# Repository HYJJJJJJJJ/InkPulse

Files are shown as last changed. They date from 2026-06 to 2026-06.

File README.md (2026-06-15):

# InkPulse

> 一块放在桌面的 7.5" 三色墨水屏，实时显示 **Claude Code 的工作状态、token 用量、待办事项、照片**，外加时钟与温湿度。
> 渲染全部在电脑端完成，设备只负责"把电脑渲染好的整屏位图拉下来贴上去"。

InkPulse 是一个**软硬件一体**的开源项目，包含：自制 PCB（ESP32-S3 + UC8179 墨水屏驱动）、3D 打印楔形外壳、设备固件、以及电脑端的渲染服务 Hub。

---

## 目录

- [它是什么](#它是什么)
- [系统架构](#系统架构)
- [仓库结构](#仓库结构)
- [技术规格速查](#技术规格速查)
- [快速开始（端到端）](#快速开始端到端)
- [当前状态与路线图](#当前状态与路线图)
- [文档索引](#文档索引)

---

## 它是什么

桌面信息屏，单屏组合显示（不翻页，避免三色屏每次全刷闪烁）：

- **Claude 状态**（主角）：某台开发机上 Claude Code 的实时状态 —— 空闲 / 工作中 / 等你输入 / 刚完成 / 出错，附项目名。需要注意的状态用**红色**强调。
- **用量**：订阅制下今日 token（输入/输出/缓存）、估算花费、5 小时计划窗口剩余比例。
- **待办**：工作/生活待办，提供局域网网页（手机也能加）。
- **照片**：可选的整屏照片布局（Floyd–Steinberg 三色抖动）。
- **顶栏白送**：时钟/日期 + 板载温湿度。

**设计取舍**（详见 [显示系统设计文档](software/docs/superpowers/specs/2026-06-09-inkpulse-display-system-design.md)）：局域网内使用、常插电无电池、订阅制用量靠解析本机日志、布局用 YAML 配置而非拖拽编辑器。

---

## 系统架构

**瘦客户端 + 本机 Hub 渲染**：复杂的排版、三色量化、抖动都在电脑上做好，设备只做整屏 blit。改布局只改配置、不用重新烧固件。

```
开发机 (跑 Claude Code)                          墨水屏设备 (ESP32-S3)
┌─────────────────────────────────────┐
│  Claude Code ──hooks──┐              │
│                       ▼              │
│  ┌────────── InkPulse Hub ─────────┐ │   WiFi / HTTP      ┌──────────────────┐
│  │ 采集器 → 状态模型 → 渲染引擎     │ │ ─────────────────▶ │ 固件:             │
│  │   ├ 用量(解析 ~/.claude 日志)    │ │  GET /frame        │  BLE/SoftAP 配网  │
│  │   ├ 待办(JSON + 网页)           │ │  → 96000B 双plane  │  拉帧→变了才刷    │
│  │   ├ 照片(目录轮换)              │ │  + ETag/304        │  →按节拍轻睡循环  │
│  │   └ Claude状态(hook POST 推送)  │ │  + X-Next-Refresh  │  离线缓存上一帧   │
│  └─────────────────────────────────┘ │                    └──────────────────┘
│   ▲ config.yaml  ▲ photos/  ▲ todos   │                       ▲ HTU21D 温湿度
└─────────────────────────────────────┘                       随取帧请求上报
```

**关键协议**（设备 ⇄ Hub）：

| 项 | 约定 |
|---|---|
| 取帧 | `GET /frame`，请求带 `If-None-Match: <上次ETag>` |
| 帧格式 | 黑 plane(48000B) + 红 plane(48000B) = **96000B**；行主序，每行 100 字节，MSB=最左像素；bit=1 表示该色 |
| 去重 | `ETag`=帧内容哈希；未变返回 `304`，**设备不刷屏**（三色屏体验命门：避免无谓闪烁） |
| 节奏 | 响应头 `X-Next-Refresh`（秒）由 Hub 决定下次拉取间隔 |
| 上报 | 设备取帧时把温湿度作为 query 带上（`/frame?t=22&h=55`），Hub 渲染进顶栏 |

---

## 仓库结构

```
InkPulse/
├── hardware/        Altium Designer PCB 工程（原理图 + PCB + 3D STEP）
│   └── library/     元件库（git submodule）
├── cad/             build123d 参数化外壳（楔形三件套 + 抽拉盖板）+ 校验脚本
│   └── output/      生成的 STL/STEP 产物
├── software/
│   ├── firmware/    ESP32-S3 固件（ESP-IDF）：UC8179 驱动 + 配网 + 拉帧主循环
│   ├── hub/         电脑端 Hub（Python/FastAPI）：采集 + 渲染 + HTTP 服务
│   └── docs/        软件侧设计文档（specs）与实现计划（plans）
└── docs/            硬件/外壳设计文档
```

各子系统都有自己的 README：[hardware](hardware/README.md) · [cad](cad/README.md) · [firmware](software/firmware/README.md) · [hub](software/hub/README.md)。

---

## 技术规格速查

| 模块 | 规格 |
|---|---|
| 主控 | ESP32-S3 模组（YD-ESP32-S3），WiFi + BLE + PSRAM |
| 屏幕 | 英瑞达 E075A42，7.5"，**800×480**，黑/白/红三色 (BWR)，控制器 **UC8179**，4 线 SPI |
| 刷新 | 全刷约 15~30s，**无局刷、无灰阶**；红色仅用于强调/告警 |
| 帧缓冲 | 双 plane（黑+红）= 96000 B ≈ 94 KB |
| 传感器 | 板载 HTU21D 温湿度（I2C，地址 0x40） |
| 供电 | USB-C 5V → LDO 3.3V，无电池，常插电 |
| 烧录 | CH343G USB 串口 + DTR/RTS 自动下载 |
| 外壳 | 3D 打印楔形支架，屏面仰角 60°，前框/后盖/底座三件 + 抽拉盖板 |

**引脚映射**（以 PCB 网表为准）：

| 信号 | GPIO | | 信号 | GPIO |
|---|---|---|---|---|
| SCL(CLK) | 41 | | DC | 39 |
| SDA(MOSI) | 42 | | RES(RST) | 38 |
| CSB(CS) | 40 | | BUSY_N | 37 |

HTU21D：SCL=GPIO2, SDA=GPIO1。

---

## 快速开始（端到端）

从零到屏上显示，需要两步：起 Hub（电脑）→ 烧固件并配网（设备）。

### 1. 起 Hub（电脑端）

```bash
cd software/hub
pip install -e ".[dev]"
( cd web-ui && npm ci && npm run build )           # 构建配置中心前端（或直接用 ./run.sh, 已内置）
cp config.example.yaml ~/inkpulse-config.yaml      # 按需改 photos/todos 路径
INKPULSE_CONFIG=~/inkpulse-config.yaml python -m inkpulse_hub
# 监听 0.0.0.0:8080（INKPULSE_PORT 可改）
```

浏览器打开 `http://<本机IP>:8080/` 即可进**配置中心**——分区管理待办/日程/行情/天气/照片、可视化布局编辑，常驻「真机当前帧 / 改完预览」面板，改动经 SSE 即时反映。无设备也能用 `/preview.png` 看渲染效果。
详见 [Hub README](software/hub/README.md)。

### 2. 烧固件 + 配网（设备端）

```bash
cd software/firmware
# 先把 main/net_config.h 的 HUB_FRAME_URL 改成你电脑的局域网地址
./build.sh setup                       # 首次：set-target esp32s3
PORT=/dev/ttyUSB0 ./build.sh fm        # 编译 + 烧录 + 看日志
```

设备首次上电无凭据 → 开 **BLE 配网**（用 Espressif 官方 *ESP BLE Provisioning* App，设备名 `PROV_InkPulse`，PoP `inkpulse`）；BLE 超时 180s 自动回退 SoftAP 网页配网。配好网后设备自动拉帧上屏。详见 [固件 README](software/firmware/README.md)。

### 3.（可选）接 Claude Code 状态

把 `software/hub/hooks/claude_status.sh` 挂到 `~/.claude/settings.json` 的 hooks，在 SessionStart→working、Stop→done、Notification→waiting_for_input 等时机上报状态。

---

## 当前状态与路线图

**已端到端跑通并真机验证**：BLE 配网 → 连 WiFi → 拉 Hub 帧 → 三色墨水屏显示仪表盘（时钟/Claude 状态/用量/温度），中文清晰、无残影。

| 子系统 | 状态 |
|---|---|
| 固件：UC8179 驱动 + 拉帧主循环 | ✅ 跑通 |
| 固件：BLE 配网（+ SoftAP 兜底） | ✅ 跑通（SoftAP 兜底路径代码就绪，未单独实测） |
| Hub：采集 + 渲染 + HTTP 服务 | ✅ 跑通，33 项测试通过 |
| 外壳 CAD：四件套 + 装配/干涉校验 | ✅ 模型与校验脚本就绪 |
| 硬件 PCB | ✅ 已制板、已焊接联调 |

**已知限制**：
- 板载这颗 HTU21D **湿度通道硬件损坏**（温度正常，湿度恒返回 0）；Hub 已在顶栏隐藏无效湿度，换好传感器后自动恢复显示。

**后续可做**：
- 微信小程序替代官方 App 配网（提升体验）
- 待办/照片/配置化的进一步打磨
- SoftAP 兜底路径的实测验证

---

## 文档索引

**设计文档（specs）**
- [显示系统设计](software/docs/superpowers/specs/2026-06-09-inkpulse-display-system-design.md) —— 软件总体架构、协议、布局、刷新策略
- [BLE 配网设计](software/docs/superpowers/specs/2026-06-11-inkpulse-ble-provisioning-design.md) —— BLE 主 + SoftAP 兜底
- [外壳设计](docs/superpowers/specs/2026-06-03-inkpulse-enclosure-design.md) —— 楔形外壳尺寸、PCB 机械接口约定

**实现计划（plans）**
- [固件：屏驱动](software/docs/superpowers/plans/2026-06-09-inkpulse-firmware-driver.md)
- [固件：联网](software/docs/superpowers/plans/2026-06-09-inkpulse-firmware-net.md)
- [固件：BLE 配网](software/docs/superpowers/plans/2026-06-11-inkpulse-firmware-ble-prov.md)
- [Hub](software/docs/superpowers/plans/2026-06-09-inkpulse-hub.md)

**子系统 README**：[hardware](hardware/README.md) · [cad](cad/README.md) · [firmware](software/firmware/README.md) · [hub](software/hub/README.md)

---

## 许可

见 [LICENSE](LICENSE)。

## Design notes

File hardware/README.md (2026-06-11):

# InkPulse 硬件（PCB）

InkPulse 驱动板的 **Altium Designer** 工程：ESP32-S3 主控 + UC8179 墨水屏接口 + HTU21D 温湿度 + USB-C 供电/烧录。板尺寸 **70.10 × 50.04mm**。

## 工程文件

| 文件 | 说明 |
|---|---|
| `PCB_Project.PrjPcb` | Altium 项目主文件（层定义/规则/工程树） |
| `PCB_Project.PrjPcbStructure` | 项目结构清单 |
| `Sheet1.SchDoc` | 原理图 |
| `PCB1.PcbDoc` | PCB 设计（布线/层/丝印） |
| `PCB1.step` | 3D STEP 导出，供 `cad/` 做装配/干涉校验 |

用 Altium Designer 打开 `PCB_Project.PrjPcb`。

## 元件库（submodule）

`library/` 是 git submodule，源 `https://github.com/HYJJJJJJJJ/AD_Library.git`，含 Altium PCB 封装库（`*.PcbLib`）与原理图库（`*.SchLib`）。首次克隆后初始化：

```bash
git submodule update --init --recursive
```

## 板上关键

| 模块 | 器件/说明 |
|---|---|
| 主控 | ESP32-S3 模组（YD-ESP32-S3），WiFi + BLE + PSRAM，板上最高元件 ≈3.7mm |
| 屏接口 | UC8179 4 线 SPI（SCL/SDA/CS/DC/RES/BUSY）+ 外部升压（GDR/RESE 驱动 MOSFET + 电感）；24-pin FPC 排座 |
| 传感器 | HTU21D 温湿度（I2C，地址 0x40，SCL=GPIO2 / SDA=GPIO1） |
| 供电 | USB-C 5V → LDO(CJ6107B33M) 3.3V，无电池 |
| 烧录 | CH343G USB 串口 + DTR/RTS 自动下载 |
| 输入 | BOOT / RESET 两键 + 1 个红色 LED |

**ESP32 ↔ 屏幕引脚映射**（固件 `main/pins.h`，以网表为准）：

| 信号 | GPIO | | 信号 | GPIO |
|---|---|---|---|---|
| SCL(CLK) | 41 | | DC | 39 |
| SDA(MOSI) | 42 | | RES(RST) | 38 |
| CSB(CS) | 40 | | BUSY_N | 37 |

## 机械接口（与外壳约定）

坐标原点 = 板几何中心；X = 长边方向；Y = Type-C(+) ↔ FPC(−) 方向。

| 项目 | 规格 | 位置 |
|---|---|---|
| 板外形 | 70.10 × 50.04，板厚 1.6mm | 中心对齐外壳 |
| 安装孔 ×4 | Φ3.2 (M3) | (±30, ±20) |
| Type-C 母座 16P | 供电/烧录 | Y− 长边中点 (0, −22)，**朝外壳后** |
| 24-pin 显示排座 | FPC 插座 | Y+ 长边中点 (0, +22)，朝屏 |

> 外壳为机械基准、PCB 跟随。详见 [外壳设计文档 §5](../docs/superpowers/specs/2026-06-03-inkpulse-enclosure-design.md)。`cad/analyze_pcb.py` 可从 `PCB1.step` 自动提取这些接口数据。

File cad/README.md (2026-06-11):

# InkPulse 外壳（CAD）

3D 打印楔形桌面外壳的**参数化建模**与校验脚本。屏面相对桌面仰角 60°，三件式打印 + 螺丝装配，外加一块抽拉盖板。

> 完整设计依据（尺寸、PCB 机械接口约定、公差）见 [外壳设计文档](../docs/superpowers/specs/2026-06-03-inkpulse-enclosure-design.md)。

## 工具链

- **建模库**：[build123d](https://github.com/gumyr/build123d) 0.10.0（Python 参数化 CAD）
- **校验**：numpy + matplotlib（干涉/装配/质心）
- 环境：Python 3.11+

```bash
conda create -n cad python=3.11
conda activate cad
pip install build123d numpy matplotlib
```

## 生成模型

```bash
cd cad
python3 enclosure.py        # 生成四件套 + 装配体，导出到 output/
```

所有尺寸是 `enclosure.py` 顶部的具名变量（与设计文档 §9 一一对应），改参数重跑即可。

## 零件（output/）

| 件 | 文件 | 作用 | 打印姿态 |
|---|---|---|---|
| 前框 bezel | `bezel.{stl,step}` | 正面开视窗露可视区，唇边压玻璃黑边 | 正面朝下（前表面最平整） |
| 后盖 back cover | `back_cover.{stl,step}` | 压紧玻璃、保护背面、开 FPC 过线槽 | 平放 |
| 底座 base | `base.{stl,step}` | 楔形，装 70×50 PCB，60° 斜接前框，后壁开 Type-C 口 | 平放 |
| 抽拉盖板 lid | `lid.{stl,step}` | 底座底盖，导轨 + 卡扣 detent + 防滑横条 | 平放 |
| 装配体 | `assembly.step` / `assembly_shell.step` | 60° 仰角姿态总装（含 PCB 与屏参考） | — |

**装配关系**：玻璃从背面放入前框 → 垫 0.5mm 泡棉 → 后盖螺丝压紧 → 屏框组件在 60° 斜接缝与底座拼接 → PCB 用 M3 锁在底座螺柱（柱心 ±30,±20）→ FPC 从屏框底经后盖线槽折入底座接显示排座。

**打印工艺**：PLA/PETG，层高 0.2mm，3 圈壁，配合间隙 0.4mm，目标免支撑/极少支撑。

## 校验脚本

这些脚本读取真实 `hardware/PCB1.step` 做几何校验，确保外壳与 PCB 配合：

| 脚本 | 作用 | 输出 |
|---|---|---|
| `analyze_pcb.py` | 从 PCB STEP 提取外形/板厚/孔位/高元件/连接器位置 | 机械接口结论 |
| `fitcheck.py` | 把真实 PCB 放入底座，检查配合间隙、螺柱对孔、Type-C 对位 | `output/fitcheck.png` |
| `check_interf.py` | 装配体各零件两两干涉体积检测（>1mm³ 报冲突） | 干涉表 |
| `fpc_reach.py` | 装配姿态下屏 FPC 出线点 → PCB 显示排座的走线距离是否够弯折 | 距离报告 |
| `verify_v3.py` | v3（PCB 前移后）关键复验：FPC 跨度 / base∩PCB / lid∩PCB / 盖板余量 / 螺柱位 | 验证清单 |
| `render_preview.py` | 4 个零件 STL 渲染成预览图 | `output/preview_parts.png` |

## 关键参数（节选）

```
SCREEN: 170.20 × 111.20 × 1.25mm，可视区 163.20 × 97.92mm
PCB:    70.10 × 50.04mm，M3 孔位 (±30, ±20)，最高元件 ≈3.7mm（ESP32 模块）
外壳:   壁厚 2.5mm，唇厚 1.2mm，仰角 60°
底座:   宽大底脚板 130 × 90 × 4mm（抗后倾），两片 60° 斜墙在 ±63
Type-C: 朝后（+Y，背向用户），开口 10×4mm，中心离内底 ≈7.3mm
```

> PCB 机械接口以**外壳为基准、PCB 跟随**；坐标原点=板几何中心，已用 `fitcheck.py` 将真实 PCB STEP 放入底座校验通过。

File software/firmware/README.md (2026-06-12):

# InkPulse 固件（ESP32-S3 + UC8179 7.5" BWR 墨水屏）

- **阶段一**：屏驱动 bring-up（清屏 + 白/黑/红测试图案）—— 已通过。
- **阶段二**：联网瘦客户端 —— BLE 配网（SoftAP 兜底）→ 从 Hub 拉 800×480 三色帧 → 写屏；ETag/304 去重、离线保留上一帧、按 `X-Next-Refresh` 节拍循环；HTU21D 温湿度随请求上报。

## 环境

ESP-IDF v5.3.2（建议装在 `~/esp/esp-idf`，可用 `IDF_PATH` 覆盖）。每开新终端先激活：

```bash
source ~/miniforge3/etc/profile.d/conda.sh && conda activate espidf   # 若用 conda
. ~/esp/esp-idf/export.sh
```

> 国内网络：工具链走 `dl.espressif.cn` 镜像、源码走 gitee。

## 构建 / 烧录 / 看日志（跨平台脚本）

脚本会自动激活 ESP-IDF 环境（找不到 `idf.py` 时 source `$IDF_PATH/export.sh`）。

**Linux / macOS / WSL** — `./build.sh`：

```bash
cd software/firmware
./build.sh setup            # 首次: set-target esp32s3
./build.sh build            # 编译
PORT=/dev/ttyUSB0 ./build.sh fm   # 烧录 + 看日志(Ctrl+] 退出)
./build.sh verify           # bring-up 验证模式(温湿度+白黑红, 不联网)
./build.sh clean
```

**Windows PowerShell** — `.\build.ps1`：

```powershell
cd software\firmware
.\build.ps1 setup
.\build.ps1 build
$env:PORT='COM5'; .\build.ps1 fm
.\build.ps1 verify
```

> 也可直接用原生 `idf.py set-target esp32s3 && idf.py build && idf.py -p <PORT> flash monitor`。
> 脚本未识别的子命令会透传给 `idf.py`，例如 `./build.sh menuconfig`。

## 配置 Hub 地址

编辑 `main/net_config.h`，把 `HUB_FRAME_URL` 改成你电脑跑 `inkpulse_hub` 的局域网地址：

```c
#define HUB_FRAME_URL "http://192.168.1.23:8080/frame"   // 改成你的 IP
```

Hub 默认端口 8080（`INKPULSE_PORT` 可改）。

## 首次配网（BLE 为主，SoftAP 兜底）

无 WiFi 凭据时，设备**优先开 BLE 配网**；超时（`PROV_BLE_TIMEOUT_S`，默认 180s）仍未配网则**自动回退 SoftAP 网页配网**。

### 方式一：BLE（推荐）

1. 手机装 **ESP BLE Provisioning** App（Espressif 官方，App Store / Google Play）
2. 打开 App → *Provision New Device* → 扫码或选设备 **PROV_InkPulse**
3. 输入 Proof of Possession：**inkpulse**
4. 选家里 WiFi → 填密码 → 提交
5. App 显示配网成功后，设备**直接复用该连接拉帧上屏，无需重启**

> 配网参数在 `main/net_config.h`：`PROV_BLE_NAME` / `PROV_POP` / `PROV_BLE_TIMEOUT_S`。
> 收到凭据后由 `wifi_prov_mgr` 完成 WiFi 连接并回报 App，再进主循环——不在配网收尾处 `esp_restart`，否则 App 会误报 “Device disconnected”。
> 后续计划：用微信小程序替代官方 App 进一步提升体验（见 `../docs`）。

### 方式二：SoftAP（BLE 超时兜底）

BLE 超时未配网时设备自动开热点 **InkPulse-Setup**（密码 `inkpulse123`）：

1. 手机/电脑连该热点 → 浏览器打开 `http://192.168.4.1`
2. 填 WiFi 的 SSID / 密码 → 保存 → 设备重启
3. 重启后连 WiFi → 拉帧 → 屏上显示 Hub 渲染的仪表盘

凭据存在 NVS namespace `inkpulse`；`./build.sh erase-flash` 可清空重新配网。

## 引脚映射（原理图确认）

| 信号 | GPIO | | 信号 | GPIO |
|---|---|---|---|---|
| SCL(CLK) | 41 | | DC | 39 |
| SDA(MOSI) | 42 | | RES(RST) | 38 |
| CSB(CS) | 40 | | BUSY_N | 37 |

HTU21D（I2C）：SCL=GPIO2, SDA=GPIO1，地址 0x40。

## 帧/颜色契约（与 Hub `/frame` 对齐，勿改）

- body = 黑 plane(48000B) + 红 plane(48000B) = 96000B；行主序，每行 100 字节，MSB=最左像素。
- 黑 plane bit=1→黑；红 plane bit=1→红。
- 写屏映射（`ip_display` 的 `uc8179.c`，阶段一极性结论）：
  - 0x10(B/W) `1=白 0=黑` → 发 `~black`
  - 0x13(RED) `1=红` → 红 plane 直发（`EPD_RED_INVERT=0`；若实测红/白反相改 1）
- 响应头 `ETag`（带引号哈希）、`X-Next-Refresh`（秒）；请求带 `If-None-Match`，命中返回 304 不刷屏。

## 代码结构（ESP-IDF components 分层）

固件按标准 components 分层解耦,`main` 只组装接口、不依赖具体实现。换屏/换数据源只需新增对应实现 component,上层零改动。接口用 ops 结构体(函数指针表 + 工厂函数)。

| component | 职责 | 公开接口 / 工厂 |
|---|---|---|
| `ip_hal` | SPI/I2C/GPIO 封装 + 板级引脚（`board_pins.h`） | `hal_spi_*` / `hal_i2c_*` |
| `ip_display` | 墨水屏（通用 display 接口 + UC8179 实现 + selftest） | `display_if_t` / `uc8179_driver()` |
| `ip_sensor` | 温湿度（sensor 接口 + HTU21D，读数带有效位） | `sensor_if_t` / `htu21d_sensor()` |
| `ip_net` | WiFi STA 连接（WPA3-SAE + 带间隔循环重连） | `ip_net_init/prepare_sta/sta_connect` |
| `ip_provisioning` | BLE/SoftAP 配网 + NVS 凭据 | `provisioning_if_t` / `ble_provisioning()` / `softap_provisioning()` / `creds_*` |
| `ip_channel` | 数据源（channel 接口 + HTTP-Hub 拉帧/上报，**不碰显示**） | `channel_if_t` / `http_hub_channel()` |
| `ip_config` | 编译期常量（Hub URL / 配网参数，`net_config.h`） | — |
| `main` | app：纯接口组装 + 主循环编排（`INKPULSE_VERIFY` 切 selftest） | — |

**换屏**：新增 `components/ip_display_xxx/` 提供 `display_if_t`，改 `main.c` 一行工厂 + CMake，上层（channel/sensor/net/app）零改动。
**换数据源**：新增 channel 实现（如 BLE 传帧）提供 `channel_if_t`，同理。

设计与实现计划见 `../docs/superpowers/specs/2026-06-12-inkpulse-firmware-layered-arch-design.md` 与 `../docs/superpowers/plans/2026-06-12-inkpulse-firmware-layered-arch.md`。

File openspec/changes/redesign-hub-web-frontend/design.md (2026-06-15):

## Context

Hub 配置中心现状是单文件 `software/hub/inkpulse_hub/web/config.html`（459 行，vanilla JS + `innerHTML` 拼接 + 内联样式），10 张卡片叠成长卷轴。后端 `server.py` 已提供完整的 `/api/*` 业务端点，渲染由 `render.engine.render_frame(cfg, state, profile)` 完成——`/frame`(设备字节) 与 `/preview.png`(预览图) 同源同一帧、on-demand 渲染。设备是瘦客户端，仅周期性 `GET /frame`（ETag/304 去重，`X-Next-Refresh` 节拍），e-ink 实际上屏约 21s 延迟。

关键缺口：服务端从不记录"上次真正送给设备的是哪一帧"，所以网页无法呈现"设备此刻物理显示的内容"；网页刷新预览靠每个操作后 `setTimeout(refreshPreview, 300)`，既不跟手也不能多端同步。

## Goals / Non-Goals

**Goals:**
- 用 Vue 3 + Vite 重写配置中心，侧栏分区导航拆掉长卷轴。
- 网页常驻"真机当前帧"（设备最后拉走的帧）+ "改完预览"切换，所见即真机。
- SSE 实时同步替换所有客户端定时刷新；多端打开自动一致。
- 纸墨/e-ink 视觉风格，响应式。
- 后端改动是纯增量加法，不碰 `render_frame` 渲染核心，设备固件零改动。

**Non-Goals:**
- 不改设备端渲染逻辑或 `/frame` 的字节格式与 ETag/304 协议（设备无感）。
- 不把屏幕上的实时数值拆成 web 原生数据卡（探索时确认走 B·真机帧，不是 A·数据镜像）。
- 不引入用户认证 / 多用户（hub 仍是单用户局域网工具）。
- 不替换现有 `/api/*` 业务端点的契约。

## Decisions

### D1：Vue 3 + Vite，而非 React 或保留 vanilla
配置型仪表盘、单文件组件(SFC)、样板少、运行时体积小，最贴这个场景。React 同样可行但样板更多；保留 vanilla 无法根治"拼字符串 + 无反应式"的老问题（用户已明确选"上正经框架"）。源码置于 `software/hub/web-ui/`，与 Python 包并列。

### D2：dist 部署时 build，不提交产物
hub 由 systemd 托管，部署时增加 `npm ci && npm run build` 一步产出 `web-ui/dist/`，FastAPI 用 `StaticFiles` 挂载。保持 git 仓库干净、避免产物与源码漂移。代价是部署机需 Node/npm，并在 README/部署文档中记录。**回退**：若构建链暂不可用，可临时保留旧 `config.html` 作 fallback 路由直到 dist 就绪（迁移期）。

### D3："真机当前帧"靠服务端记录最后送出帧实现
在 `/frame` handler 中，当返回真实帧体（非 304）时，把该帧的 `png_bytes` + 时间戳 + 当前 env(t/h/rssi) 存入 hub 状态（`state.py` 或新 `device_view` 模块的内存字段，单设备、单槽即可）。新增：
- `GET /api/device/frame.png` → 返回该 PNG（无记录时回退为当前 `preview.png` 或占位）。
- `GET /api/device/status` → `{ pulled_at, age_s, rssi, temp, humidity, etag }`。
这样"真机当前帧"与"改完预览(`/preview.png`)"是两张可对比的图，差异窗口正好可视化 e-ink 延迟。**备选**：在网页侧用 ETag 推断——否决，服务端记录更直接、可附 env/时间戳。

### D4：SSE 单向流 + 独立 web 同步令牌，替代轮询
**关键修正**：现有 `_refresh["token"]`（`/api/refresh-token`）是**设备**轮询的"强制立即刷屏"信号，只应由用户点「刷新屏幕」(`/api/refresh`) 触发。若把"设备拉帧"并入同一令牌会造成死循环（设备拉帧→bump→设备再拉帧），把"每次数据改"并入则会让设备每改一条就强刷一次、伤 e-ink。因此采用**两个独立令牌**：
- **设备令牌** `refresh_token`（`/api/refresh-token`）：语义**完全不变**，仅 `/api/refresh` 触发，设备只看它。
- **web 同步令牌** `web_token`（仅 SSE 用）：配置改 / 数据改(todos/habits/events/market/photos/...) / 设备拉帧 / `/api/refresh` 都 `bump`，**只驱动网页**自动刷新预览与真机帧；设备永不感知。

新增 `GET /api/stream`（`text/event-stream`），推送 `{ token, device_pulled_at }`，网页订阅后据此自动刷新，**删除所有 `setTimeout(refreshPreview, 300)`**。SSE 而非 WebSocket：单向推送够用、FastAPI 下 `StreamingResponse` 实现简单、无额外依赖、`EventSource` 断线自动重连。SSE 生成器以 ~1s 轮询 `web_token` 变化（避免跨线程信号，sync 端点在线程池里 bump，不能安全 `set()` 事件循环里的 Event），变化即推送。**备选**：网页直接轮询 `/api/refresh-token`——否决，延迟高、多端不同步、且会与设备令牌语义打架。

### D5：信息架构——侧栏分区 + 常驻帧主角
导航分区拆掉长卷轴，按"低频配置 vs 高频日常"归类：
```
总览 | 屏幕(布局+编辑器+刷新间隔) | 待办 | 习惯 | 日程 | 行情 | 天气 | 照片 | 设置
```
顶部/侧栏常驻 `[真机当前] / [改完预览]` 切换 + `⟳刷屏` 按钮，跨分区始终可见。布局编辑器(网格框选)作为"屏幕"分区下的子面板保留现有交互。

### D6：纸墨视觉语言
承接 `docs/mockups/mockup-explorer.html` 既有配色审美，建立 CSS 设计 token（纸白底、墨黑字、点缀红——对应 BWR 三色屏）。响应式：桌面侧栏、窄屏抽屉/底部 Tab。

## Risks / Trade-offs

- [部署新增 Node 构建依赖] → 在部署文档/README 记录 `npm ci && npm run build`；迁移期保留旧 HTML fallback（D2）。
- [SSE 长连接占用 worker / 断线] → 限制单连接、心跳 keep-alive、客户端 `EventSource` 自动重连；uvicorn 异步天然支持。
- [最后送出帧的内存状态在 hub 重启后丢失] → 可接受：重启后首次设备拉帧即重建；`/api/device/frame.png` 无记录时回退到 `preview.png`。
- [前端大改面积、回归风险] → 现有 `/api/*` 契约不变，逐分区迁移并对照旧页验证；后端改动有 pytest 覆盖。
- [真机帧 vs 预览混淆用户] → UI 明确标注"设备 N 秒前拉帧"与"下次拉帧将变成"，把延迟讲清楚而非藏起来。

## Migration Plan

1. 后端先行：加 `/api/device/*` 与 `/api/stream`、`/frame` 记录最后送出帧；补 pytest。旧 `config.html` 暂留。
2. 搭 `web-ui/` Vue+Vite 骨架，逐分区迁移（先总览+屏幕+预览/真机帧，再 todos/habits/events/market/weather/photos/settings）。
3. 接 SSE，删除 `setTimeout(refreshPreview,300)`。
4. `StaticFiles` 挂载 `dist/`，切换默认入口；验证通过后移除 `config.html`、`todos.html` 及 `/config`、`/todos` 旧路由。
5. 更新部署文档（构建步骤）。**回退**：保留旧 HTML 路由分支即可快速切回。

## Open Questions

- 纸墨配色的具体 token 值是否直接复用 mockup-explorer 的调色板，还是另立一套？（实现时定）
- 窄屏导航用底部 Tab 还是抽屉？（实现时按手感定）

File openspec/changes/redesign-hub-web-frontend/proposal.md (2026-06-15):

## Why

Hub 的配置中心目前是一个 459 行的 `config.html` 单文件：10 张卡片叠成一根长卷轴、用 vanilla JS 拼 `innerHTML`、内联样式满天飞。三个痛点叠加——(1) 全堆一页要命的长滚，配置类与日常类内容互相干扰；(2) 实时预览埋在第 3 张卡、改完要靠 `setTimeout(refreshPreview, 300)` 手动刷，预览不跟手；(3) 视觉朴素。更关键的是：网页只能看到一张"按当前 state 渲染的 PNG"，**看不到设备此刻物理显示的那一帧**——而这正是用户想要的"所见即真机"。

## What Changes

- **BREAKING**：用 Vue 3 + Vite 重写整个配置中心，退役 `config.html` 与遗留的 `todos.html`。前端产物 `dist/` 经 FastAPI `StaticFiles` 挂载到 `/`。
- 用**侧栏分区导航**拆掉长卷轴：总览 / 屏幕(布局+编辑器+刷新) / 待办 / 习惯 / 日程 / 行情 / 天气 / 照片 / 设置，各分区各司其职。
- 引入**"真机当前帧"常驻主角**：网页顶部/侧栏常驻一块，显示设备最后真正拉走的那一帧（= 此刻玻璃上的内容），附"设备 N 秒前拉帧 · RSSI · 温度"。可在 `[真机当前]` 与 `[改完预览]` 间切换，把 e-ink 刷新延迟可视化。
- 后端**增量加法**（不动渲染核心）：`/frame` 命中时记录"最后送给设备的帧"（png + 时间戳 + rssi/temp）；新增 `GET /api/device/frame.png` 与 `GET /api/device/status`。
- 引入 **SSE 实时流** `GET /api/stream`：统一 `refresh-token`，配置改 / 数据改 / 设备拉帧都 bump，网页订阅后自动更新预览与真机帧——**删除所有 `setTimeout(refreshPreview, 300)`**，多端打开自动同步。
- 现代化**纸墨 / e-ink 视觉风格**，承接 `docs/mockups/mockup-explorer.html` 已有的配色审美；响应式，手机上也可用。
- 现有 `/api/*` 业务端点（todos/habits/weather/events/market/config/layouts/photos/refresh）**保持不变**，仅被新前端消费。

## Capabilities

### New Capabilities
- `hub-web-ui`: Vue 3 + Vite 重写的 Hub 配置中心——侧栏分区导航、纸墨视觉、响应式，常驻"真机当前帧 / 改完预览"切换面板；Vite `dist/` 经 FastAPI 静态挂载、部署时 build。
- `device-frame-mirror`: 后端记录"最后送给设备的帧"（png + 时间戳 + rssi/temp），并通过 `GET /api/device/frame.png`、`GET /api/device/status` 暴露给网页，实现"真机当前帧"镜像。
- `hub-realtime-sync`: SSE 流 `GET /api/stream` 统一 `refresh-token` 信号（配置改/数据改/设备拉帧均 bump），网页订阅后自动刷新预览与真机帧，取代客户端定时轮询。

### Modified Capabilities
<!-- 现有 dashboard-rendering(设备端渲染)的需求不变；本次只新增 web 与后端配套端点。 -->

## Impact

- **新增前端工程**：`software/hub/web-ui/`（Vue 3 + Vite 源码 + `package.json`），build 产物 `dist/`。
- **`software/hub/inkpulse_hub/server.py`**：新增 `/api/device/frame.png`、`/api/device/status`、`/api/stream`(SSE)，`/frame` handler 增加"记录最后送出帧"；用 `StaticFiles` 挂载 `dist/`；移除 `/config`、`/todos` 旧 HTML 路由与 `web/config.html`、`web/todos.html`。
- **`software/hub/inkpulse_hub/state.py`**（或新模块）：保存最后送出帧的字节/PNG/时间戳/env。
- **部署**：systemd 托管的 hub 启动前需 `npm ci && vite build`（或文档化的构建步骤）；新增 Node/npm 构建依赖。
- **测试**：新增 `/api/device/*`、`/api/stream` 的 pytest；前端可加轻量构建校验。
- 设备固件**无需改动**（仍只拉 `/frame`）。

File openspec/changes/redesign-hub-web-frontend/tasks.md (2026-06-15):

## 1. 后端：真机当前帧记录与端点 (device-frame-mirror)

- [x] 1.1 在 hub 状态（`state.py` 或新 `device_view` 模块）增加"最后送出帧"内存槽：png 字节、时间戳、env(t/h/rssi)、etag
- [x] 1.2 修改 `/frame` handler：返回 200 真实帧体时写入该槽；304 命中时不覆盖
- [x] 1.3 新增 `GET /api/device/frame.png`（无记录时回退 preview/占位，不报错）
- [x] 1.4 新增 `GET /api/device/status`（`pulled_at`/`age_s`/`rssi`/`temp`/`humidity`）
- [x] 1.5 pytest 覆盖：拉帧后被记录、304 不覆盖、无记录回退、status 字段

## 2. 后端：统一信号源与 SSE (hub-realtime-sync)

- [x] 2.1 抽出 `bump_web()` 单一入口；写请求经 middleware 统一 bump，`/frame` 拉帧经 record_device_frame bump（设备 refresh_token 语义不变，避免死循环）
- [x] 2.2 新增 `GET /api/stream`（`text/event-stream`），token 变化时推送 `{token, device_pulled_at}`，含心跳 keep-alive
- [x] 2.3 pytest 覆盖：数据变更/拉帧触发 bump、设备令牌不受影响、`sse_stream` 初值+变更各发一条事件

## 3. 前端工程脚手架 (hub-web-ui)

- [x] 3.1 在 `software/hub/web-ui/` 初始化 Vue 3 + Vite 工程（`package.json`、构建脚本）
- [x] 3.2 建立纸墨视觉设计 token（纸白/墨黑/红点缀）与全局样式，承接 mockup-explorer 配色
- [x] 3.3 搭好 API 封装层（`/api/*` 调用）与 SSE 客户端（`EventSource` 自动重连）
- [x] 3.4 实现侧栏分区导航骨架（总览/屏幕/待办/习惯/日程/行情/天气/照片/设置）+ 响应式窄屏导航

## 4. 前端：常驻预览/真机帧面板

- [x] 4.1 实现跨分区常驻面板：`[真机当前]`/`[改完预览]` 切换 + `⟳刷屏`
- [x] 4.2 真机当前视图接 `/api/device/frame.png` + `/api/device/status`，标注"设备 N 秒前拉帧 · RSSI · 温度"
- [x] 4.3 改完预览视图接 `/preview.png`；两视图均由 SSE 事件自动刷新，去除任何固定 setTimeout 刷新

## 5. 前端：各分区面板迁移

- [x] 5.1 屏幕分区：布局选择 + 布局编辑器(网格框选保留交互) + 刷新间隔
- [x] 5.2 待办、习惯分区
- [x] 5.3 日程、行情、天气分区
- [x] 5.4 照片分区（上传/删除/钉选）
- [x] 5.5 设置分区（预算/token 上限/刷新间隔等）
- [x] 5.6 总览分区（汇总入口 + 真机帧主视图）

## 6. 集成、退役与文档

- [x] 6.1 FastAPI 用 `StaticFiles` 挂载 `web-ui/dist/` 为网页入口
- [x] 6.2 移除 `web/config.html`、`web/todos.html` 及 `/config`、`/todos` 路由（旧页测试一并删除）
- [x] 6.3 更新 README/部署文档：`run.sh` 内置幂等 build、hub/主 README 构建步骤与端点表、systemd 注意事项
- [x] 6.4 全量回归：pytest 292 通过、端到端冒烟(SPA 入口/旧路由404/设备帧端点/API)验证

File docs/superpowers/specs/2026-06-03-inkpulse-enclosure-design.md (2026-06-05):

# InkPulse 墨水屏桌面外壳 — 设计文档

- 日期：2026-06-03
- 状态：已确认，待实现
- 目标：为 InkPulse 项目（7.5" 三色墨水屏 + 50×50 驱动板）设计一个可 3D 打印的楔形桌面外壳。

## 1. 背景与依据

- **墨水屏**：深圳英瑞达 **E075A42**（7.5" 三色 AMEPD，800×480）。规格书：`hardware/docs/英瑞达E075A42 （BWR）(1).pdf`。
  - 外形：**170.20 (W) × 111.20 (H) × 1.25 (厚，含膜) mm**，重 44±0.5g。
  - 可视区 (AA)：**163.20 × 97.92 mm**。
  - 黑边（AA 到外形，**非对称**）：上 3.49 / 下 9.79（FPC 侧）/ 左右各 3.50 mm（长边方向居中，短边方向 AA 上偏）。
  - **FPC 排线**：从 **170.20mm 长边居中**引出（判据：偏宽黑边 9.79mm 落在 111.20mm 方向轴上，绑定边垂直于该轴 → 即长边）。FPC 宽 **79.90 ±0.2mm**，露出/弯折段 **11.50–12.50mm**，带 PI 补强（总厚 0.30mm，补强段不可弯，弯折仅发生在 0.10mm 软段）。
  - 背面平整、无金属背板或突起，可整面贴泡棉。
  - 接口 24-pin（脚距规格书未标注数值，需实测/向供应商确认，常见 0.5mm 但不可据此下料）。
- **驱动板**：**70.10 × 50.04mm**（实测自 `hardware/PCB1.step`，由 build123d 导入测量）。Type-C 与显示 FPC 排座分别在两条 70mm 长边中点。板载 16P Type-C 母座用于供电/烧录。
  - 早期为 50×50，后改版为 70×50；外壳已据 STEP 实测更新（见 §5）。
- **约束/选择**（与用户确认）：
  - 屏横放（170.2 宽 × 111.2 高），FPC 在底部长边。
  - 外形为 "∠" 楔形，底座位于屏框**正下方**。
  - 屏面与水平桌面**仰角 60°**。
  - 三件式打印 + 螺丝装配。
  - PCB 四角 M3 螺柱固定。
  - Type-C 开口**朝后**（背向用户）。
  - 打印机幅面 ≥ 220×220（屏框可整片打印）。
  - 材料默认 PLA/PETG，层高 0.2mm，3 圈壁。
  - **外壳为机械基准，PCB 跟随**（见 §5 接口约定）。

## 2. 总体架构

楔形桌面支架，三个 FDM 打印件 + 螺丝装配：

| 件 | 作用 | 打印姿态 |
|---|---|---|
| 前框 bezel | 正面开视窗露可视区，唇边压玻璃黑边 | 正面朝下 → 前表面最平整 |
| 后盖 back cover | 压紧玻璃、保护背面、开 FPC 过线槽 | 平放 |
| 底座 base（楔形） | 装 50×50 PCB，与前框 60° 拼接，后壁开 Type-C 口 | 平放 |

装配关系：玻璃从背面放入前框 → 垫 0.5mm 泡棉 → 后盖螺丝压紧（屏框组件）→ 屏框组件在 60° 斜接缝与底座螺丝拼接 → PCB 用 M3 锁在底座螺柱上 → FPC 从屏框底经后盖线槽折入底座接显示排座。

## 3. 屏框（前框 + 后盖）

- 玻璃容腔：170.20×111.20，单边间隙 0.4mm（实装容差）。
- **视窗开口**：163.20 × 97.92 + 0.5mm 余量；**向上偏置**——上边框 ~3.0 / 下边框（FPC 侧）~9.3 / 左右 ~3.0mm。视窗中心相对玻璃中心**上移 ≈ 3.15mm**（= (9.79−3.49)/2）。
- 前框唇边压黑边（不碰 AA），唇厚 1.2mm。
- 壁厚 2.5mm；屏框外形约 **176 × 117mm**。
- **背腔减薄至 5mm**（仅容玻璃 1.25 + 泡棉 0.5 + 薄后盖凸台）→ 前框总深 **7.2mm**（原 19.2），后盖总厚 **5.25mm**（原 17.25）。
- 后盖：与屏框外形齐平，4× M2.5 自攻螺丝压向前框；玻璃背面垫 0.5mm 泡棉。
- 后盖 FPC 过线槽：**宽 84 × 深 13mm**，位于底部长边中央（对齐 FPC 79.9mm 宽 + 余量）。PI 补强段直出、软段折弯下行。

## 4. 底座（楔形 + PCB 仓 + 宽大底脚板）

- **中央 PCB 核心盒**：内腔容 70×50 PCB，四周间隙 0.5mm；4× M3 打印螺柱（boss），柱心 (±30, ±20)，柱高 4mm；**内腔净高 9mm**（顶面元件仅 3.7mm，已减薄；壁高 11mm 仍包住 Type-C 开口）。
- **后壁 Type-C 开口**：10 × 4mm（含 0.5 容差 + 倒角），中心离内底 ≈ **7.3mm**；Type-C 朝 +Y（背向用户）。底脚板低矮（4mm）不遮挡插拔。
- **宽大扁平底脚板（稳定性）**：**130 (W) × 90 (D) × 4mm**，横跨支撑 176mm 宽屏、抗后倾。屏重心水平投影（Y≈−16）落在脚板内 → 不倾倒。
- **两片 60° 斜墙（gusset）**：外移到脚板宽边 **±63**，横撑屏宽；起于脚板顶。**斜面朝 −Y+Z（朝观察者-上），使屏朝 −Y 观察者、向后倾**（朝向经校验：法线 ny=−0.87, nz=+0.50, arccos=60°）。2× M3 接缝螺丝横穿斜墙。
- 顶部线槽对位显示排座，承接屏框下来的 FPC。

## 5. PCB 机械接口约定 v1（外壳基准，PCB 跟随）

坐标原点 = 板几何中心；X 右为正；Y 朝 Type-C/后为正、朝屏/前为负。单位 mm。

**实测自 `hardware/PCB1.step`（板几何中心为原点；X=长边方向，Y=Type-C↔FPC 方向）**：

| 项目 | 规格 | 位置（板中心原点） |
|---|---|---|
| 板外形 | **70.10 × 50.04**，板厚 1.6（STEP 简化为 0.41，取实际 1.6） | 中心对齐外壳 |
| 安装孔 ×4 | **Φ3.2 (M3)** | **(±30, ±20)** |
| Type-C 母座 16P | body 11.3×7.6，口中心离板底 ≈1.65mm | **Y− 长边中点 (0, −22)** |
| 24-pin 显示排座 | 0.5mm 间距 FPC 插座，~12mm 宽 | **Y+ 长边中点 (0, +22)** |
| 最高元件 | **≈3.7mm**（ESP32 模块, 17.6×15.8 @ (−8.7,2.4)） | — |

> **装配朝向**：Type-C 边朝外壳后（+Y），FPC 排座边朝屏（前/−Y）。装入时 PCB 相对外壳绕 Z 翻 180°。
> 外壳侧已据此更新：PCB 仓 71.1×51、螺柱 (±30,±20)、Type-C 开口在 +Y 壁中心高 7.65mm。
> 已用 `cad/fitcheck.py` 将真实 PCB 放入底座校验：螺柱对孔、板落仓内、Type-C 对位开口，全部通过。

## 6. 打印工艺与公差

- 前框正面朝下、后盖与底座平放，目标**免支撑或极少支撑**。
- 配合间隙 0.4mm；自攻螺纹底孔按 M2.5/M3 自攻留 0.2mm。
- 材料 PLA/PETG，层高 0.2mm，壁 3 圈。
- 输出：STEP（导回 Altium 做装配/干涉检查）+ STL（切片打印）。

## 7. 实现方式（工具链）

- **build123d（Python）** 参数化建模，所有尺寸为脚本顶部变量。
- 环境：用户提供的 conda 环境（待建：`conda create -n cad python=3.11 && pip install build123d`）。
- 重活（写脚本、生成模型、干涉/可打印性验证）派 subagent 执行，结论回传，避免污染主上下文。

## 8. 未决/风险

- **24-pin 排座脚距未知**：规格书未标，建议实测；不影响外壳腔体设计（排座位置由 §5 约定），仅影响 PCB 选型。
- **Type-C 母座精确机械尺寸**：按 16P 通用值取默认，待实物/封装确认后微调开口。
- **重心稳定性**：170×111 屏 60° 后倾于 50mm 深底座，需在 CAD 后用质心/倾覆校核；必要时底座向后延伸或加配重槽。
- FPC 软段最小弯折半径需在装配验证时确认不超限。

## 9. 参数清单（CAD 变量，初值）

```
# 屏模组
SCREEN_W=170.20  SCREEN_H=111.20  SCREEN_T=1.25
AA_W=163.20  AA_H=97.92
BORDER_TOP=3.49  BORDER_BOTTOM=9.79  BORDER_SIDE=3.50
FPC_W=79.90  FPC_EXPOSED=12.50
# 外壳
WALL=2.5  LIP=1.2  FIT_GAP=0.4  FOAM_T=0.5
WINDOW_MARGIN=0.5
ANGLE_DEG=60
BACK_LIP_DEPTH=5.0        # 背腔深(减薄) -> 前框总深~7.2, 后盖~5.25
# 底座/PCB
PCB=50.0  PCB_T=1.6  STANDOFF_H=4.0
HOLE_D=3.2  HOLE_INSET=4.0
TYPEC_W=12.5  TYPEC_H=6.0  TYPEC_PORT_Z=5.65   # 实测自PCB1.step
FPC_CONN_Y=-22.8
CAVITY_CLEAR=9.0          # 减薄(原15); 元件仅3.7mm
PCB_W=70.10  PCB_D=50.04  M3_POS_X=30  M3_POS_Y=20
# 宽大底脚板 + 斜墙
BASE_FOOT_W=130.0  BASE_FOOT_D=90.0  BASE_FOOT_T=4.0
GUSSET_HEIGHT=40.0  GUSSET_T=4.0   # 斜墙在 ±(FOOT_W/2-GUSSET_T/2)=±63
```

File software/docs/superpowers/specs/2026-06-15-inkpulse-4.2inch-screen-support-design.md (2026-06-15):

# InkPulse 4.2 寸屏(SSD1677 BW)支持 — 设计

> 日期:2026-06-15 · 状态:已批准,待写实现计划

## 背景与目标

现有 InkPulse 使用 7.5 寸 **E075A42**(800×480,UC8179,BWR 三色)墨水屏。
现要新增对 4.2 寸 **YRD0426BBS770F0**(480×800,SSD1677 类,纯黑白 1-bit,支持局部刷新)的支持,
并满足三个目标:

1. **硬件**:核对新旧屏 FPC 是否 pin-to-pin 对应,判断是否改板。
2. **固件**:屏驱动充分解耦,能快速从 UC8179(BWR)切换到 SSD1677(BW)。
3. **hub 布局**:检测屏幕大小,基于现有 7.5 寸布局新实现一组 4.2 寸 480×800 竖屏布局。

一句话方案:**新屏与旧屏 pin-to-pin 兼容、不改板;固件编译期选驱动;hub 由设备上报的面板标识驱动多 profile 渲染(尺寸/颜色/旋转/网格/打包全随 profile)。**

## 已确认的硬事实(来自规格书)

新屏 `YRD0426BBS770F0`(`hardware/docs/YRD0426BBS770F0HP-V2.0-4.2_Inch-480x800.pdf`):

- 分辨率 **480(H)×800(V) 竖屏**;有效区 55.68×92.80mm;外形 62.37×105.33mm。
- **1-bit 纯黑白单 plane**(非 BWR);控制器 RAM 仍为 **800×480**,单 plane **48000 字节**(800/8×480)。
- 控制器命令集 `0x12/0x0C/0x01/0x11/0x44/0x45/0x4E/0x4F/0x24/0x22/0x20/0x10` =
  标准 **SSD16xx(SSD1677 类)**。
- 接口 4 线 SPI(BS1=L);信号:CS#/D-C#/RES#/SCL/SDA/BUSY;24-pin FPC;图像更新 ~1.1s;支持局部刷新;内置温度传感器。

> 注意:控制器 RAM 是 800×480(横向),模组按竖屏 480 宽×800 高观看。
> 因此"480×800 竖屏"在出帧时需要 **旋转 90°** 映射到 800×480 的 RAM。

## 数据流总览

```
设备(GET /frame?...&panel=bw_426)  ──►  hub
   │ 编译期 Kconfig 选屏                    │ panel id → ScreenProfile
   │ ssd1677 driver (display_if_t)          │ 选 layout 集 + 网格 + 颜色 + 旋转 + 打包
   ▼                                        ▼
 48000B 单plane ◄──── 800×480 1bpp ◄── rotate90 ◄── 渲染 480×800 竖屏画布
```

---

## 第 1 节 · 硬件(结论:**不改板**)

逐脚对比(旧屏 E075A42 规格书 p6 vs 新屏 YRD0426 规格书 p7):

| 脚 | 旧屏 E075A42(7.5″ BWR) | 新屏 YRD0426(4.2″ BW) | 一致 |
|---|---|---|---|
| 1 | NC | NC | ✓ |
| 2 | GDR | GDR | ✓ |
| 3 | RESE | RESE | ✓ |
| 4 | NC | NC | ✓ |
| 5 | VSHR | VSH2 | ✓ |
| **6** | **TSCL**(外置温感 I2C) | **NC** | ⚠ |
| **7** | **TSDA**(外置温感 I2C) | **NC** | ⚠ |
| 8 | BS | BS1 | ✓ |
| 9 | BUSY_N | BUSY | ✓ |
| 10 | RST_N | RES# | ✓ |
| 11 | DC | D/C# | ✓ |
| 12 | CS-N | CS# | ✓ |
| 13 | CLK/SCL | SCL | ✓ |
| 14 | DATA/SDA | SDA | ✓ |
| 15 | VDDIO | VDDIO | ✓ |
| 16 | VDDA | VCI | ✓ |
| 17 | VSS | VSS | ✓ |
| 18 | VDDD | VDD | ✓ |
| 19 | VPP | VPP | ✓ |
| 20 | VSH | VSH1 | ✓ |
| 21 | VGH | VGH | ✓ |
| 22 | VSL | VSL | ✓ |
| 23 | VGL | VGL | ✓ |
| 24 | VCOM | VCOM | ✓ |

**结论:24 脚中 22 脚完全同位,信号线(BS/BUSY/RST/DC/CS/SCL/SDA)全部一致 → 电气 pin-to-pin 兼容,不需要改板。**
唯一差异 pin6/7:旧屏是外置温感 I2C(TSCL/TSDA),新屏是 NC。本项目温湿度走独立板载 HTU21D、不经屏 FPC,故 NC 无影响。

交付物为一份**真机核对清单**(非代码):

1. 照新屏参考电路核对升压外围电容(GDR/RESE/VGH/VGL/VSH)值是否需微调。
2. 真机确认板上 pin6/7 未被强驱动到会干扰的电平(NC 一般安全)。
3. 新屏更小(62×105mm),**结构件/外壳/FPC 走线需重做**(属结构设计,不属改电路板)。

---

## 第 2 节 · 固件(编译期选驱动)

固件已有良好抽象:`ip_display/display.h` 定义 `display_if_t`(含 `get_caps`),`ip_channel` 的 `ch_init(caps)` 已用 `caps->frame_bytes` 决定拉多少字节。只需新增一个驱动实现 + 编译期选择。

- 新增组件驱动 `components/ip_display/src/ssd1677.c`,实现 `display_if_t`;
  `get_caps` 返回 `{width:480, height:800, color_model:DISP_BW, frame_format:"bw-1plane", frame_bytes:48000}`。
- `Kconfig` 增加 `choice INKPULSE_PANEL`:
  - `PANEL_UC8179_BWR_750`(默认,现状)
  - `PANEL_SSD1677_BW_426`
- `main.c` 按宏选驱动:
  ```c
  const display_if_t *disp =
  #if CONFIG_PANEL_SSD1677_BW_426
      ssd1677_driver();
  #else
      uc8179_driver();
  #endif
  ```
- 命令序列照规格书 p35 OTP 参考码:
  `0x12(软复位)→0x0C(升压软启动)→0x01(驱动输出/尺寸)→0x11(数据进入模式)→0x44/45(RAM XY 窗口)→0x4E/4F(RAM XY 计数器)→0x24(写 BW)→0x22(0xF7)→0x20(刷新)`;
  局刷走 SSD1677 partial update 流程(部分窗口 + partial LUT/0x22 参数)。
- `s_framebuf` 尺寸随 Kconfig(BW 仅需 48000;BWR 96000)。
- `mark_offline` 出 BW 变体:画黑色 X(无 red plane),与现 BWR 版同位。
- `ssd1677_selftest` 对标现有 `uc8179_selftest`:白/黑/棋盘 + 一次局部刷新演示。

**真机 bring-up 校准项**(非纯软件可定):

- 渲染→面板的旋转方向(90° 还是 270°)。
- 打包 bit 极性(`1`=黑 还是 `1`=白)。
- 升压软启动 / VCOM / LUT 参数微调。

URL 上报:固件在 `GET /frame` URL 追加 `&panel=<id>`(由 Kconfig 选屏决定,如 `bw_426` / `bwr_750`),供 hub 选 profile。

---

## 第 3 节 · hub(profile 驱动多尺寸)

### 现状耦合点

- `render/planes.py` 写死 `WIDTH,HEIGHT=800,480` + BWR 双 plane(`to_planes`/`pack_frame`)。
- `render/grid.py` 从 planes 取尺寸。
- `render/layouts.py` 仅有单一全局 `GRID={cols:8,rows:6}` 与一套 `BUILTIN_LAYOUTS`。
- `render/engine.py` 按写死尺寸建画布、打 BWR 包。
- `render/widgets.py` 多为 Zone 相对坐标 + 按 z.h/z.w 算字号(可缩放),少数用 RED(日历"今天")。
- `server.py` 的 `/frame` 为无状态拉模式,仅读 `t`/`h` 查询参数,帧为全局单一。

### 引入 ScreenProfile

把渲染知识集中到 hub 的一个 profile 表:

```python
bwr_750 = {w:800, h:480, color:"bwr", rotate:0,  grid:(8,6), pack:bwr_2plane}  # 现状
bw_426  = {w:480, h:800, color:"bw",  rotate:90, grid:(4,8), pack:bw_1plane}   # 新增
```

### 改动

- **`planes.py`**:移除写死尺寸/BWR;
  - `pack_frame(img, profile)`:按 `profile.color` 选单 plane(BW)或双 plane(BWR);
    按 `profile.rotate` 在 hub 侧用 PIL 旋转 90°(480×800 → 800×480)后再 1bpp 打包。
  - BW 单 plane:`to_plane_bw(img)` 输出 48000B。
- **`grid.py`**:`cell_to_zone(grid, p, profile)` 用 `profile.w/h`。
- **`layouts.py`**:`BUILTIN_LAYOUTS` 改为**按 profile 分组**:
  - `bwr_750` 沿用现有 8×6 六布局;
  - `bw_426` 新增 4×8 竖版六布局,**同名**(dash/photo/clock/usage/split/todo);
  - `get_layout(path, name, profile)`;用户自建布局存储按 profile 命名空间隔离。
- **`engine.py`**:`render_frame(cfg, state, profile)` 按 profile 建画布、选布局集、渲染、打包。
- **`server.py /frame`**:解析 `&panel=<id>` → 解析 ScreenProfile(**缺省/未知回退 `bwr_750`**,兼容现役固件)→ `render_frame(cfg, state, profile)`;ETag/preview 随 profile。
- **颜色降级**(BW profile):
  - 提供 `accent(profile)`:BWR 返回红、BW 返回黑。
  - 提供 `emphasize(d, zone, ...)`:今天等原本靠红区分的元素改用加框/反色/下划线。
  - 仅日历"今天"、市场涨跌等少数 widget 需改;红→黑后语义靠形状保留。

### 4×8 竖版布局草案(可在 plan 阶段微调)

```
480×800 / 4列×8行(格子 120×100px)
dash:  header(4×1) / claude_status(4×2) / usage(4×2) / todos(4×3)
photo: photo(4×8)
clock: big_clock(4×3) / calendar(4×3) / 余 2 行留白或 header
usage: usage(4×3) / usage_ring(4×2) / claude_status(2×3) + todos(2×3)
split: header(4×1) / claude_status(4×2) / calendar(4×2) / todos(4×3)
todo:  todos(4×5) / calendar(4×3)
```

---

## 第 4 节 · 兼容性

- 现役 7.5 寸固件不带 `panel` 参数 → hub 回退 `bwr_750` → 行为完全不变(**零回归**)。
- 新 4.2 寸固件带 `&panel=bw_426` → hub 渲 480×800 竖屏 → 旋转 → 48000B 单 plane。

---

## 第 5 节 · 测试

**hub(可纯软件验证,无需硬件)**:

- profile 解析与 `/frame` 参数解析 + 缺省/未知回退 `bwr_750`。
- 各 profile 网格数学(cell_to_zone 边界无缝)。
- 单 plane(BW,48000B)/ 双 plane(BWR,96000B)打包正确。
- 旋转正确性:已知图案渲染→旋转→校验像素落位。
- 颜色降级:BW 下红→黑且"今天"有替代强调。
- 6 个竖版布局逐个渲染不抛异常、产出 48000B 帧。
- 扩展现有 `test_planes/test_grid/test_engine/test_layouts` 为 profile 参数化。

**固件**:`ssd1677_selftest` + `INKPULSE_VERIFY` harness;真机校准旋转方向/bit 极性/升压。

---

## 第 6 节 · 实现拆分(两条独立 plan + 一份硬件清单)

- **Plan A(hub 多 profile)**:profile 重构(planes/grid/engine/layouts)+ bw_426 竖版布局 + 颜色降级 + `/frame` panel 参数 + 测试。
  **可在 hub 用 `/preview.png` 完整验证,不依赖硬件,应先行。**
- **Plan B(固件 ssd1677 驱动)**:Kconfig 选屏 + `ssd1677.c` + caps/URL panel id + BW `mark_offline` + selftest + 真机校准。
- **硬件核对清单**:随 Plan B 收尾(升压电容核对、pin6/7、结构件/外壳重做)。

两者通过 `&panel=` + ScreenProfile 解耦;A 与 B 可并行,A 可独立先验。

## 非目标(YAGNI)

- 不做固件运行时自动探测屏型(编译期 Kconfig 已足够)。
- 不把控制器时序/LUT 参数化下发(不同控制器差异大,得不偿失)。
- 本期不为 4.2 寸引入旧屏没有的新 widget;先复用现有 widget 重排。

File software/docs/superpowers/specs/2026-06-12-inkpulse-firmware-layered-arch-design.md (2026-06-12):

# InkPulse 固件分层解耦架构 — 设计文档

- 日期：2026-06-12
- 状态：已与用户确认方向，待评审后进入实现计划
- 范围：`software/firmware/` —— 把现有平铺的 `main/*.c` 重构为标准 ESP-IDF components 分层架构

---

## 1. 背景与目标

当前固件所有模块平铺在 `main/`（`epd_uc8179`/`htu21d`/`wifi_prov`/`ble_prov`/`frame_client`/`main`/`net_config`/`pins`），互相直接 `#include`、无接口隔离。典型耦合：

- `frame_client.c` 直接 `#include "epd_uc8179.h"` 并调用 `epd_display_planes(black, red)` —— 把「数据来源（HTTP/Hub）」和「显示（UC8179 双 plane）」绑死在一个函数里。
- `epd_uc8179.h` 一个头暴露了 HAL（`epd_send_cmd/data`）+ UC8179 驱动序列 + 双 plane 协议（`EPD_RED_INVERT`）+ bring-up 测试图案，四层混在一起。

**目标**：按标准嵌入式工程分层解耦，使以后
- **换屏幕**（不同墨水屏控制器/尺寸，甚至单色/多色/LCD）只新增 display 实现、不动上层；
- **换上层数据源**（Hub 服务端 / App / PC-BLE）只新增 channel 实现、不动上层。

## 2. 设计前提（已与用户确认）

| 边界 | 结论 |
|---|---|
| 显示抽象层次 | **通用「显示设备」接口**：能力查询（分辨率/色彩模型/帧格式）+ 显帧/刷新/睡眠。不假设双 plane 三色。 |
| 上层通道 | **双向 channel 抽象**：帧下行 + 状态上行（温湿度），预留控制下行。本期只实现 WiFi/HTTP，BLE **仅配网**。 |
| 交付范围 | **重构现有功能**搬进分层 + 立好接口并预留双向/多 transport；**不**实现 BLE 传帧/双向控制。 |
| 重构形态 | **完整 ESP-IDF components 化**：每层独立 component，`include/` 接口 + `src/` 实现 + `CMakeLists` 显式依赖。 |

**非目标（YAGNI）**：BLE 传帧、双向控制下行、状态上报除温湿度外的项、运行时多 display/channel 共存。这些只在接口上预留，不实现。

## 3. Component 分层与依赖方向

```
components/
├── ip_hal/           SPI/I2C/GPIO 封装 + 板级引脚(board_pins.h)
├── ip_display/       【接口】display.h(能力查询/显帧/刷新/清屏/睡眠)
│                     【实现】uc8179.c  → 依赖 ip_hal
├── ip_sensor/        【接口】sensor.h(读环境量, 带有效位)
│                     【实现】htu21d.c  → 依赖 ip_hal
├── ip_net/           WiFi STA 生命周期(连接/WPA3-SAE/循环重连/状态)
├── ip_provisioning/  【接口】provisioning.h
│                     【实现】ble_prov.c + softap_prov.c + creds_nvs.c → 依赖 ip_net
├── ip_channel/       【接口】channel.h(取帧/上报env/预留控制下行)
│                     【实现】http_hub.c → 依赖 ip_net
└── ip_config/        编译期常量(Hub URL、配网参数、刷新节拍默认)
main/                 app: 只组装接口 + 主循环编排, 变薄
```

**依赖方向严格单向，上层只依赖接口头**：

```
main(app) ──→ display.h / channel.h / sensor.h / provisioning.h / ip_net / ip_config
uc8179.c ──→ ip_hal          htu21d.c ──→ ip_hal
http_hub.c ──→ ip_net        ble/softap_prov ──→ ip_net + creds_nvs
```

app **从不** `#include` 任何具体实现头（`uc8179.h`/`htu21d.h`/`http_hub.h`）。

## 4. 接口定义（ops 结构体 / 函数指针表）

C 里以「能力 struct + ops 函数指针表 + 工厂函数」实现面向接口编程。换实现 = 让 app 取另一个工厂 + 改 CMake，零改上层逻辑。

### 4.1 display（`ip_display/include/ip_display/display.h`）

```c
typedef enum { DISP_BWR, DISP_BW, DISP_ACEP7, DISP_RGB } disp_color_model_t;

typedef struct {
    uint16_t width, height;
    disp_color_model_t color_model;
    const char *frame_format;   // 如 "bwr-dualplane"; Hub 据此渲染
    size_t frame_bytes;          // 一帧字节数(BWR 800x480 = 96000)
} display_caps_t;

typedef struct {
    esp_err_t (*init)(void);
    void      (*get_caps)(display_caps_t *out);
    esp_err_t (*show)(const uint8_t *frame, size_t len);  // 写一帧(格式由 caps 定义)
    void      (*refresh)(void);
    void      (*clear)(void);
    void      (*sleep)(void);
} display_if_t;

const display_if_t *uc8179_driver(void);   // 工厂
```

> UC8179 实现内部保留现有极性结论（`0x10` 取反、`0x13` 直发）与 bring-up 测试图案（移到实现内部的 `uc8179_selftest.c`，不进公开接口）。

### 4.2 sensor（`ip_sensor/include/ip_sensor/sensor.h`）

```c
typedef struct {
    float temp_c;     bool temp_valid;
    float humidity;   bool humidity_valid;   // 传感器损坏读 0 时置 false
} sensor_env_t;

typedef struct {
    esp_err_t (*init)(void);
    esp_err_t (*read)(sensor_env_t *out);
} sensor_if_t;

const sensor_if_t *htu21d_sensor(void);
```

> 有效位取代现状的「传 -100 哨兵」：湿度通道坏时 `humidity_valid=false`，上层/Hub 据此隐藏，语义清晰。

### 4.3 channel（`ip_channel/include/ip_channel/channel.h`）

```c
typedef struct { bool changed; int next_refresh_s; } channel_result_t;

typedef struct {
    esp_err_t (*init)(const display_caps_t *caps);   // 知道要拉什么帧格式
    // 拉一帧到 buf(buf 大小= caps.frame_bytes), 顺带上报 env; changed=false 表示未变(304)
    esp_err_t (*fetch)(uint8_t *buf, size_t buf_len,
                       const sensor_env_t *env, channel_result_t *out);
    // 预留(本期不实现): esp_err_t (*poll_control)(channel_control_t *out);
} channel_if_t;

const channel_if_t *http_hub_channel(void);
```

### 4.4 net / provisioning

```c
// ip_net: WiFi STA(含 WPA3-SAE + 带间隔循环重连, 沿用现有修复)
esp_err_t ip_net_connect(const char *ssid, const char *pass);
bool      ip_net_is_up(void);

// ip_provisioning: 拿到凭据存 NVS(creds_nvs); 成功后(BLE)复用已建连接
typedef struct { bool (*run)(int timeout_s); } provisioning_if_t;
const provisioning_if_t *ble_provisioning(void);
const provisioning_if_t *softap_provisioning(void);
bool creds_load(char *ssid, size_t sl, char *pass, size_t pl);
```

## 5. 帧格式与能力协商

- 设备启动时由 `display->get_caps()` 得到 `display_caps_t`，`channel->init(caps)` 据此知道要拉哪种帧；HTTP 实现把 `frame_format`/分辨率作为请求参数或头带给 Hub，Hub 渲染对应格式。
- 本期 UC8179 = `bwr-dualplane`/800×480/96000B，与现有 `/frame` 协议一致（行为不变）。
- 换屏（如单色/ACeP7）只改 `get_caps` 返回值 + 对应 `show()` 解码，Hub 端按上报能力渲染——设备上层与 channel 接口不变。

## 6. 数据流（app 主循环编排）

```c
const display_if_t *disp   = uc8179_driver();
const sensor_if_t  *sensor = htu21d_sensor();
const channel_if_t *chan   = http_hub_channel();

disp->init();  display_caps_t caps; disp->get_caps(&caps);
sensor->init();

if (!creds_load(...)) {                       // 无凭据 → 配网
    if (!ble_provisioning()->run(PROV_BLE_TIMEOUT_S))
        softap_provisioning()->run(...);       // 兜底; 配完重启或复用连接
}
ip_net_connect(ssid, pass);                    // WPA3-SAE + 循环重连
chan->init(&caps);
disp->clear();                                 // 开机消残影

static uint8_t framebuf[/*caps.frame_bytes 上限*/];
while (1) {
    sensor_env_t env; sensor->read(&env);
    channel_result_t r;
    if (chan->fetch(framebuf, sizeof framebuf, &env, &r) == ESP_OK && r.changed) {
        disp->show(framebuf, caps.frame_bytes);
        disp->refresh();
    }
    delay_s(r.next_refresh_s);
}
```

帧 buffer 由 app 持有（`.bss`），channel 填、display 显示；三方通过接口协作，互不知道对方实现。

## 7. 现有代码 → 新结构映射

| 现有 | 去向 |
|---|---|
| `epd_uc8179.c` HAL 部分(SPI/GPIO/send_cmd/data/wait_busy) | `ip_hal/` |
| `epd_uc8179.c` UC8179 序列 + `epd_display_planes` | `ip_display/src/uc8179.c`(实现 `display_if_t`) |
| `epd_uc8179.c` 测试图案(`show_split/checker/solid`) | `ip_display/src/uc8179_selftest.c`(实现内部) |
| `htu21d.c` | `ip_sensor/src/htu21d.c`(实现 `sensor_if_t`，加有效位) |
| `wifi_prov.c` STA 连接/重连部分 | `ip_net/` |
| `wifi_prov.c` 配网编排 + SoftAP 页 + NVS 凭据 | `ip_provisioning/`(softap_prov + creds_nvs) |
| `ble_prov.c` | `ip_provisioning/src/ble_prov.c`(实现 `provisioning_if_t`) |
| `frame_client.c` | `ip_channel/src/http_hub.c`(实现 `channel_if_t`，去掉对 display 的直接依赖) |
| `net_config.h` | `ip_config/` |
| `pins.h` | `ip_hal/include/ip_hal/board_pins.h` |
| `main.c` | `main/`(只做接口组装 + 主循环 + 保留 `INKPULSE_VERIFY` 走 display selftest) |

## 8. 错误处理 / 容错（沿用现有，不退化）

- 离线：`channel->fetch` 失败保留上一帧、按退避节拍重试（现有行为）。
- WiFi：`ip_net_connect` 内含 WPA3-SAE + 带 2s 间隔循环重连（沿用本周期修复）。
- 配网：BLE 超时 → SoftAP 兜底（`esp_wifi_stop` 后切 AP，沿用修复）。
- 接口调用返回 `esp_err_t`，app 对失败做日志 + 安全降级，不 crash。

## 9. 测试策略

- **接口契约**：每个 ops 工厂返回非空、`get_caps` 字段合理，可在真机 boot 时断言。
- **display selftest**：`INKPULSE_VERIFY` 走 `uc8179_selftest`（白/黑/红/分屏/棋盘），真机肉眼验证（沿用，已修宏生效问题）。
- **端到端**：配网 → 连 WPA3 → 拉帧 → 上屏，真机回归（现有 harness）。
- 纯逻辑（如 sensor 有效位判定、帧字节数校验）可抽到 host 可测函数。

## 10. 落地分期（详细步骤留给实现计划）

1. **骨架**：建 components 目录 + 各 `CMakeLists` + 接口头（先空实现/桩），全工程能编译。
2. **下沉实现**：按映射表逐 component 迁移现有代码到实现里，对齐接口；每迁一层编译通过。
3. **app 重写**：`main.c` 改为纯接口组装 + 主循环；删旧平铺文件。
4. **真机回归**：selftest + 端到端配网拉帧上屏，行为与重构前一致。

## 11. 验收标准

- 目录为 components 分层，`main` 不再 `#include` 任何具体实现头。
- 「换屏」可行性自检：能描述新增一个 display 实现 component 需要改哪些（答案应为：新 component + app 一行 + CMake，零改上层）。
- 真机端到端行为与重构前一致（配网/拉帧/上屏/温度显示/重连）。

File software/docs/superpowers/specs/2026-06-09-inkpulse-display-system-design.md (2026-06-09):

# InkPulse 墨水屏显示系统 — 设计文档

- 日期：2026-06-09
- 状态：设计已与用户确认，待评审后进入实现计划
- 范围：`software/` 目录下的全部软件（开发机侧 Hub + 设备侧固件 + Claude Code hook 脚本）

---

## 1. 背景与目标

基于已有硬件（ESP32-S3 + 7.5" 三色墨水屏）开发一个**桌面信息屏**，显示：

- **Claude 状态（A）**：某台开发机上 Claude Code 的实时工作状态
- **Claude 用量（B）**：订阅制下的 token 用量 / 花费估算 / 计划窗口剩余
- **待办（C）**：工作/生活待办事项
- **照片（D）**：照片展示
- **白送项**：板载温湿度 + 时钟/日期

核心诉求：**显示内容可配置**，默认布局由实现方给出合理值。

### 非目标（v1 不做，YAGNI）
- 图形化拖拽布局编辑器（v1 用 YAML 配置）
- 云端中继 / 远程访问（局域网内使用；中继留作后续可选插件）
- 电池供电 / 低功耗优化（硬件常插电，无电池）
- API Key 计费模式的用量（用户是订阅制；详见 §4.2）

---

## 2. 硬件事实（来自原理图与 E075A42 规格书）

| 模块 | 事实 | 对软件的约束 |
|---|---|---|
| 主控 | ESP32-S3 模组（YD-ESP32-S3），WiFi + BLE，含 PSRAM | 联网无碍；PSRAM 足以放整屏帧缓冲 |
| 屏幕 | E075A42，7.5"，**800×480**，**黑/白/红三色 (BWR)**，控制器 **UC8179**，4 线 SPI；有效区 163.2×97.92mm | 全刷约 15~30s，**无局刷、无灰阶、无动画**；红色仅用于强调/告警 |
| 屏幕信号 | SCL(SPI CLK)、SDA(MOSI)、CSB(CS)、DC、RES(复位)、BUSY(忙信号输入)；BS 选择 3/4 线 SPI；外部升压由 GDR/RESE 驱动板载 MOSFET(SI2304)+电感，芯片内部时序控制 | 固件只需驱动 SPI + 控制脚；上电升压由面板上电命令触发，硬件已就绪 |
| 供电 | USB-C 5V → LDO(CJ6107B33M) → 3.3V，**无电池、无充电** | 常插电桌面设备，可常驻联网、按计划刷新 |
| 传感器 | 板载 HTU21D 温湿度（I2C：IIC_SDA / IIC_SCL） | 时钟/温湿度 widget 数据源 |
| 输入 | 仅 BOOT / RESET 两键，1 个红色 LED | 几乎无物理交互，配置/控制走网络侧 |
| 烧录 | CH343G USB 串口 + DTR/RTS 自动下载 | 调试方便 |

> 帧缓冲大小：800×480 = 384,000 px；1 bit/px/plane = 48,000 B；BWR 双 plane（黑 + 红）= 96,000 B ≈ 94 KB，PSRAM 充裕。

> ESP32 与屏幕/传感器的具体 GPIO 映射以 PCB 网表为准，bring-up 阶段核对。

---

## 3. 总体架构（方案：瘦客户端 + 本机 Hub 渲染）

```
开发机 (Claude Code 订阅)                          墨水屏设备 (ESP32-S3)
┌──────────────────────────────────────┐
│  Claude Code ──hooks──┐               │
│                       ▼               │
│  ┌──────────  InkPulse Hub  ──────────┐│   WiFi / HTTP     ┌────────────────┐
│  │ 采集器 → 数据模型 → 渲染引擎        ││───────────────────▶│ 固件:           │
│  │                    → HTTP /frame    ││  位图 + ETag       │  拉帧→变了才刷  │
│  │                    → Web /todos     ││  + X-Next-Refresh  │  →轻睡→循环     │
│  └─────────────────────────────────────┘│                    │  离线缓存上一帧│
│   ▲config.yaml  ▲photos/  ▲todo 存储     │                    └────────────────┘
└──────────────────────────────────────┘
```

**渲染在电脑上完成**：Hub 把整屏渲染成三色位图，设备只负责"拉下来贴上去"。改布局只改配置、不烧固件；三色照片抖动也只能在电脑上做好。

**离线处理（内建，与开发机是否常开无关）**：设备连不上 Hub 时保留上一帧并显示离线角标，退避重连。

---

## 4. 组件设计（边界清晰，各自可独立测试）

### 4.1 Hook 脚本（Claude Code 侧）
- 挂在 Claude Code 的 `settings.json` hooks：`SessionStart` / `Stop` / `Notification` / `UserPromptSubmit`（及可用的工作开始/结束钩子）
- 每次触发：把当前状态 + 项目名 POST 到 Hub（如 `POST /ingest/claude-status`）
- 脚本保持极薄；网络失败静默忽略（不阻塞 Claude Code）

### 4.2 采集器（Collectors，Hub 内，各产出一个类型化数据模型）
1. **Claude 状态采集器**：接收 hook POST，维护状态机
   `idle / working / waiting_for_input / done(刚完成) / error`，附带 `project`、`since`（进入该状态时间）
2. **用量采集器**：解析订阅会话日志 `~/.claude/projects/**/*.jsonl`（ccusage 思路）
   产出：今日 token（输入/输出/缓存）、估算花费、Max 计划 5 小时窗口剩余比例、今日会话数
   > 订阅制无官方用量 API，只能解析本机日志；日志结构变更需容错（缺失 → 该项 `n/a`）
3. **待办采集器**：读取待办存储（见 §4.5）
4. **照片采集器**：扫描照片文件夹，按策略选/轮换一张

每个采集器：输入明确（hook / 日志文件 / 存储 / 文件夹），输出一个 dataclass，依赖隔离，可单测。

### 4.3 渲染引擎（Hub 内）
- 输入：`config.yaml`（布局+启用的 widget）+ 各数据模型
- 流程：按 widget 把内容排版到 800×480 画布 → 量化为 **黑 plane + 红 plane** 两个 1-bit 位图
  - 文本/图标：纯黑白 + 红色强调
  - 照片：**Floyd–Steinberg 三色抖动**（黑/白/红）
- 技术：Python + Pillow
- 产物：两个 bitplane 的字节缓冲 + 一个内容哈希（用于 ETag）

### 4.4 HTTP 服务（Hub 内）
- `GET /frame`：返回打包的双 plane 位图；响应头 `ETag`（内容哈希）、`X-Next-Refresh`（建议下次拉取间隔秒数）；请求带 `If-None-Match` 命中则 `304`
- `GET /preview.png`：把当前帧渲染成 PNG，**在电脑上肉眼调布局**用（无需设备）
- `GET /health`：健康检查
- `POST /ingest/claude-status`：接收 hook 上报
- `GET|POST /todos` + 静态页：待办 Web UI（见 §4.5）
- 技术：FastAPI

### 4.5 待办 Web UI（按用户要求新增）
- Hub 提供一个轻量网页 `/todos`：增加 / 勾选完成 / 删除待办
- 局域网可访问 → 手机也能加待办
- 后端存储：**JSON 文件**（如 `~/inkpulse/todos.json`），简单够用
- Markdown 文件作为**可选导入源**（`- [ ]` 语法），非主路径

### 4.6 固件（设备侧，ESP-IDF）
- **WiFi STA**：连接配置好的 AP
- **配网**：v1 用 SoftAP 配网页一次性写入 NVS（无按键也能配）；实现复杂时先编译期写死兜底
- **主循环**：
  1. 连 WiFi（断则重连退避）
  2. `esp_http_client` 请求 `GET /frame`，带 `If-None-Match: <上次ETag>`
  3. `304` → 不刷屏；`200` → 解析双 plane → 写 UC8179 → 全刷
  4. 按响应头 `X-Next-Refresh` 延时 / 轻睡，循环
- **墨水屏驱动**：ESP-IDF 自写精简 **UC8179 SPI 驱动**（命令表取自 E075A42 规格书）：复位时序、上电、写黑 RAM、写红 RAM、刷新、深睡
- **离线**：保留上一帧（NVS/RAM 缓存最近 ETag 与帧），连不上时维持显示 + 角标
- **温湿度**：设备 I2C 读 HTU21D，在请求 `/frame` 时把读数随请求带上（query/header），由 Hub 渲染进顶栏（数据归属明确：设备采集、Hub 渲染）
- 不上 LVGL：瘦客户端只需整屏 blit 双 plane

---

## 5. 设备 ⇄ Hub 协议

| 项 | 约定 |
|---|---|
| 取帧 | `GET /frame`，`Accept` 二进制；带 `If-None-Match` |
| 帧格式 | 头部(宽/高/plane数/字节序) + 黑 plane(48000B) + 红 plane(48000B)；可选 RLE 压缩 |
| 去重 | `ETag` = 帧内容哈希；未变返回 `304`，设备不刷屏（**三色屏体验命门：避免无谓闪烁**） |
| 节奏 | 响应头 `X-Next-Refresh` 由 Hub 决定下次拉取间隔（秒） |
| 上报 | 设备可在取帧时附带温湿度（query 或 header） |

---

## 6. 默认布局（实现方决定，可配置覆盖）— 组合仪表盘，不翻页

> 翻页每切一次全刷（闪 15~30s），故默认单屏组合：

```
┌──────────────────────────────────────────────┐
│ 6/9 周一 14:32        🌡22°C 💧55%   [顶栏]     │
├───────────────────────────┬────────────────────┤
│   🔴 等你输入              │ 今日用量            │
│   project: InkPulse        │  1.2M tok ≈ $0      │
│   (Claude 状态 — 主角)     │  5h窗口 ▓▓▓▓░ 68%   │
├───────────────────────────┴────────────────────┤
│ ☐ 完成固件刷屏  ☐ 写 todos 解析  ☑ 定架构        │
│ (待办 取前几条)                                  │
└──────────────────────────────────────────────┘
```

- 红色用于"等你输入 / 出错"等需注意状态
- **照片**作为**可选布局**（如配置成 "Claude 空闲时整屏照片" 或定时切换），不挤默认仪表盘

---

## 7. 刷新策略（针对三色屏慢刷）

- **状态变化事件驱动**刷新，设**最小刷新间隔**（如 ≥60s）+ 防抖，避免连续闪屏
- **用量/时钟定时**刷新（如每 5~10 分钟）；时钟只到分钟，不显示秒
- **照片**慢速轮换（如 30~60 分钟）
- **ETag 去重**：帧未变设备不刷屏
- 调度逻辑集中在 Hub（设备只听 `X-Next-Refresh`），便于调参

---

## 8. 配置（v1：YAML 文件，Web 配置界面留后）

开发机上一个 `config.yaml`，至少包含：
```yaml
device:
  width: 800
  height: 480
refresh:
  min_interval_s: 60
  periodic_s: 600
sources:
  claude_logs: ~/.claude/projects
  photos_dir: ~/inkpulse/photos
  todos_store: ~/inkpulse/todos.json   # 或 sqlite
layout:
  default:
    widgets: [header_clock_env, claude_status, usage, todos]
  # photo: { fullscreen_photo }   # 可选布局
```
（最终 schema 在实现阶段定稿。）

---

## 9. 容错

- **Hub**：任一采集器失败 → 对应 widget 显示 `n/a`，不拖垮整帧；渲染按 widget 隔离
- **设备**：连不上 Hub → 留上一帧 + 离线角标 + 退避重连；WiFi 断 → 重连循环
- **Hook**：上报失败静默，不影响 Claude Code

---

## 10. 测试策略

- **采集器**：用日志 / todo 存储样本做单元测试（解析正确性、缺失容错）
- **渲染引擎**：PNG 黄金图对比（布局回归）
- **HTTP 服务**：端点契约测试（`/frame` 头部、`304`、`/todos` 增删）
- **固件**：用 mock Hub 喂已知帧验证刷屏；`/preview.png` 在电脑上肉眼调布局；UC8179 驱动 bring-up 在真机上分步验证（复位→上电→写 RAM→刷新）

---

## 11. 落地分期（详细步骤留给实现计划）

- **Phase 1 — 打通管道**：Hub 渲染一张**静态**仪表盘 → `/frame` → 固件拉取并全刷成功（含 ETag/304、离线缓存、UC8179 驱动）
- **Phase 2 — 接真实数据**：Claude 状态 hook + 用量日志解析 → 仪表盘活起来
- **Phase 3 — 待办/照片/配置化**：待办 Web UI + 照片抖动 + `config.yaml` 驱动布局 + 刷新策略调参

---

## 12. 待实现阶段核实的开放项
- E075A42 对应的 UC8179 具体命令时序（规格书 §7 命令表）与外部升压上电序列
- ESP32 ↔ 屏幕/HTU21D 的 GPIO 映射（PCB 网表）
- 订阅会话日志 JSONL 的字段结构与 Max 计划窗口口径
- 帧是否启用 RLE 压缩

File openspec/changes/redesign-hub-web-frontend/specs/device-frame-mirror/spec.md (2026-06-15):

## ADDED Requirements

### Requirement: 记录最后送给设备的帧
当设备通过 `GET /frame` 取得真实帧体（非 304）时，hub SHALL 记录该帧对应的预览 PNG、记录时间戳以及当时的环境数据（温度/湿度/RSSI）。该记录 MUST 反映"设备此刻物理显示的内容"。304 命中（设备复用缓存）SHALL 不覆盖已记录的帧。

#### Scenario: 设备拉取新帧后被记录
- **WHEN** 设备请求 `/frame` 且 hub 返回 200 帧体
- **THEN** hub 更新"最后送出帧"的 PNG、时间戳与 env 快照

#### Scenario: 304 不覆盖记录
- **WHEN** 设备请求 `/frame` 且命中 ETag 返回 304
- **THEN** hub 保留先前记录的最后送出帧不变

### Requirement: 真机当前帧端点
hub SHALL 提供 `GET /api/device/frame.png`，返回最后送给设备的帧的 PNG。当尚无记录时 SHALL 回退返回当前渲染预览或占位图，而非报错。

#### Scenario: 已有记录
- **WHEN** 设备至少拉过一次帧后，网页请求 `/api/device/frame.png`
- **THEN** 返回该帧的 PNG 图像

#### Scenario: 尚无记录回退
- **WHEN** hub 启动后设备尚未拉过帧，网页请求 `/api/device/frame.png`
- **THEN** 返回当前预览或占位图，HTTP 状态为成功

### Requirement: 设备状态端点
hub SHALL 提供 `GET /api/device/status`，返回最后拉帧时间、距今时长（秒）、以及最近上报的 RSSI、温度、湿度等设备状态。

#### Scenario: 查询设备状态
- **WHEN** 网页请求 `/api/device/status`
- **THEN** 返回包含 `pulled_at`、`age_s` 及可得的 `rssi`/`temp`/`humidity` 的 JSON

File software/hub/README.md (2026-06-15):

# InkPulse Hub

开发机侧服务：采集 Claude 状态/用量、管理待办/照片，把整屏渲染成 **800×480 三色位图**供墨水屏设备拉取。基于 FastAPI + Pillow。

> 设计背景见 [显示系统设计文档](../docs/superpowers/specs/2026-06-09-inkpulse-display-system-design.md)。

## 运行

```bash
cd software/hub
pip install -e ".[dev]"
( cd web-ui && npm ci && npm run build )           # 构建配置中心前端 → web-ui/dist
cp config.example.yaml ~/inkpulse-config.yaml      # 按需修改
INKPULSE_CONFIG=~/inkpulse-config.yaml python -m inkpulse_hub
```

> `run.sh` 已内置幂等的 Web UI 构建步骤（dist 不存在才 build），用脚本/systemd 启动时无需手动跑 `npm`。手动起服务则需先 build 一次，否则配置中心页面 404（API 仍正常）。开发前端用 `cd web-ui && npm run dev`（vite dev server 自动反代 :8080 的 `/api`、`/frame`、`/preview.png`、`/photos`）。

- 监听 `0.0.0.0:8080`（环境变量 `INKPULSE_PORT` 可改）。
- `INKPULSE_CONFIG` 不设时全部用默认值。
- **配置中心**（Vue SPA）：浏览器开 `http://<本机IP>:8080/` —— 侧栏分区(总览/屏幕/待办/习惯/日程/行情/天气/照片/设置)，常驻「真机当前帧 / 改完预览」面板，改动经 SSE 即时反映。手机连同一局域网也可用。
- 纯预览图：`http://<本机IP>:8080/preview.png`；真机当前帧：`/api/device/frame.png`
- 设备取帧：`GET /frame`

## 一键启动（多平台）

仓库提供幂等启动脚本：自动找 Python(≥3.11) → 没 venv 就建 → 没装依赖就 `pip install -e .` → 选配置 → 起服务。venv/依赖已在则秒起。

| 平台 | 脚本 | 用法（在 `software/hub`） |
|---|---|---|
| Linux / macOS / WSL | `run.sh` | `./run.sh` |
| Windows | `run.ps1` | `.\run.ps1`（被拦就 `powershell -ExecutionPolicy Bypass -File .\run.ps1`） |

环境变量 `INKPULSE_PORT` / `INKPULSE_CONFIG` 均生效；后者不设时自动用 `~/inkpulse-config.yaml`（存在才用）。

## 开机自起（systemd user 服务，Linux/WSL）

让 Hub 随系统启动、崩溃自动重启，无需手动开终端。

```bash
mkdir -p ~/.config/systemd/user
cat > ~/.config/systemd/user/inkpulse-hub.service <<'EOF'
[Unit]
Description=InkPulse Hub (e-ink 渲染服务)
After=network-online.target
Wants=network-online.target

[Service]
Type=simple
WorkingDirectory=%h/workspace/InkPulse/software/hub
ExecStart=%h/workspace/InkPulse/software/hub/run.sh
Environment=PATH=/usr/local/sbin:/usr/local/bin:/usr/sbin:/usr/bin:/sbin:/bin
Restart=always
RestartSec=5
# 可选覆盖：
# Environment=INKPULSE_PORT=8080
# Environment=INKPULSE_CONFIG=%h/inkpulse-config.yaml

[Install]
WantedBy=default.target
EOF

loginctl enable-linger "$USER"          # 不登录终端也常驻（WSL 一启动就拉起）
systemctl --user daemon-reload
systemctl --user enable --now inkpulse-hub.service
```

> `WorkingDirectory`/`ExecStart` 按你的仓库实际路径改（上面用 `%h` 代表家目录）。

运维：

```bash
systemctl --user status inkpulse-hub        # 状态
systemctl --user restart inkpulse-hub       # 改代码/布局后重启
journalctl --user -u inkpulse-hub -f        # 实时日志
```

> **WSL 注意**：需 `/etc/wsl.conf` 开 `[boot] systemd=true`；且 WSL 在你首次打开任意终端时才启动（`wsl --shutdown` 后服务也随之停，再次打开终端会自动拉起）。

## 模块结构

```
inkpulse_hub/
├── __main__.py        入口：起 uvicorn，读 INKPULSE_CONFIG / INKPULSE_PORT
├── config.py          Config dataclass + YAML 加载（refresh / sources / layout）
├── server.py          FastAPI 应用与全部 HTTP 端点
├── state.py           HubState：聚合状态/待办/温湿度 + 时钟 + 农历(cnlunar)，供渲染
├── models.py          数据类：ClaudeStatus / Usage / TodoItem / Photo
├── collectors/        采集器
│   ├── usage.py       解析 ~/.claude/projects/**/*.jsonl → 今日 token/花费/窗口比例
│   ├── todos.py       TodoStore：JSON 文件 CRUD（list/add/toggle/delete）
│   └── photos.py      pick_photo：扫描照片目录选一张
├── render/            渲染
│   ├── engine.py      render_frame：排版 → 量化双 plane → 出 Frame(body/etag/png)
│   ├── widgets.py     draw_header / draw_claude_status / draw_usage / draw_todos
│   ├── planes.py      RGB → 黑/红双 plane 编码（96000B）；ETag 哈希
│   └── dither.py      dither_bwr：照片 Floyd–Steinberg 三色抖动
└── hooks/             见下「接 Claude Code 状态」

web-ui/                配置中心前端（Vue 3 + Vite，独立工程）
├── src/components/    Sidebar / PreviewPanel（真机帧 ⇄ 预览 切换）
├── src/sections/      各分区：Overview/Screen/Todos/Habits/Events/Market/Weather/Photos/Settings
├── src/store.js       全局 store + SSE(EventSource) 订阅 /api/stream
└── dist/              构建产物，被 server.py 用 StaticFiles 挂载到 /（.gitignore）
```

**采集模型是推拉混合**：用量/待办/照片是 Hub 主动拉（解析日志/读文件），Claude 状态是 hook 主动 POST 推送。

## HTTP 端点

| 方法 | 路径 | 说明 |
|---|---|---|
| GET | `/health` | 健康检查 `{"ok": true}` |
| GET | `/frame?t=<温度>&h=<湿度>` | 96000B 双 plane 帧；带 `ETag`/`X-Next-Refresh`；`If-None-Match` 命中返回 304 |
| GET | `/preview.png` | 「改完预览」：按当前配置渲染的 PNG（下次拉帧设备会变成的样子）|
| GET | `/` | 配置中心 Vue SPA（构建后由 StaticFiles 挂载）|
| GET | `/api/device/frame.png` | 「真机当前帧」：设备最后真正拉走的那一帧（= 此刻物理显示）|
| GET | `/api/device/status` | 设备状态：`pulled_at`/`age_s`/`rssi`/`temp`/`humidity` |
| GET | `/api/stream` | SSE 实时流：web 同步令牌变化即推送，网页据此自动刷新（取代轮询）|
| GET | `/api/todos` | 待办列表 JSON（另有 habits/events/market/weather/layouts/photos/config 等）|
| POST | `/api/todos` | 新增待办，body `{"text": "..."}` |
| POST | `/api/todos/{id}/toggle` | 切换完成状态 |
| DELETE | `/api/todos/{id}` | 删除待办 |
| POST | `/api/refresh` | 请求真机立即刷新（递增**设备**刷新令牌；web 令牌另算）|
| POST | `/ingest/claude-status` | 接收 hook 上报，body `{"state": "...", "project": "..."}` |

## 配置（config.yaml）

```yaml
refresh:
  min_interval_s: 60       # 最小刷新间隔（防抖）
  periodic_s: 600          # 周期刷新（用量/时钟）
sources:
  claude_logs: ~/.claude/projects     # Claude Code 会话日志目录
  photos_dir: ~/inkpulse/photos        # 照片目录
  todos_store: ~/inkpulse/todos.json   # 待办存储
  layouts_store: ~/inkpulse/layouts.json   # 自定义布局存储(网页编辑器写入)
layout:
  # 当前生效布局名(对应 layouts.json 里的 key);内置: dash/photo/usage/todo/clock/split
  name: dash
usage:
  window_token_limit: 2000000   # 5h 窗口 token 上限，进度条按此算占用
  budget_usd: null              # 今日花费预算(USD)，超过则花费数字标红；null=不启用
```

任一采集器失败 → 对应 widget 显示 `n/a`，不拖垮整帧（按 widget 隔离容错）。

## 仪表盘渲染规则

- **头部两行**：第一行完整日期时间 `2026-06-12 11:23 周五`（红色强调）+ 温湿度；第二行**农历**（`cnlunar` 纯算法算出"农历日期 · 生肖年 · 节气"，遇节日自动标红）。
- **红色策略（强调 + 告警，但克制护刷新/防残影）**：固定强调红 = 日期；告警红 = Claude 等输入/出错、窗口占用 >90%、超预算（需配 `budget_usd`）、节日。分区标题栏用黑底白字（结构，不用红），正文/待办/温湿度保持黑色。
- **丰富元素**：黑底白字分区标题栏、放大的花费 hero 数字、状态持续时长（`已 N 分钟`）、今日会话数、窗口占用百分比、真复选框 ☑/☐（完成项删除线）。
- e-ink 约束:只有黑/白/红，全刷约 20s，红刷新更慢/残影更顽固;`engine.py` 关抗锯齿（`fontmode="1"`）保证红字为纯 `(255,0,0)`。
- **布局自定义**:屏幕为 8×6 网格,布局是数据(`layouts.json`)。配置中心(`/`)「屏幕」分区的"布局编辑器"可点格子放 widget、存成命名布局。加新 widget = 在 `render/registry.py` 注册一个绘制函数。

## 接 Claude Code 状态（hooks）

把 `hooks/claude_status.sh` 接到 `~/.claude/settings.json` 的相应 hook，在
SessionStart→`working`、Stop→`done`、Notification→`waiting_for_input` 等时机调用并传入状态名：

```bash
claude_status.sh working        # 状态 ∈ {idle, working, waiting_for_input, done, error}
```

脚本自动取 `basename "$PWD"` 作项目名，POST 到 `$INKPULSE_HUB`（默认 `http://127.0.0.1:8080`），2 秒超时、失败静默（不阻塞 Claude Code）。

## 测试

```bash
pytest -q       # 覆盖 config/state/models/采集器/渲染/HTTP 端点
```

测试覆盖配置加载、采集器解析与容错、双 plane 编码、各 widget 绘制、HTTP 端点契约。

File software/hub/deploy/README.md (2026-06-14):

# 部署:systemd 开机自起

把 InkPulse Hub 注册为 systemd 服务,随 WSL/systemd 启动自动拉起,崩溃自动重启。

> 前提:WSL 已开启 systemd(`/etc/wsl.conf` 含 `[boot]\nsystemd=true`,本机已配)。
> 注意:WSL 下"开机自起"= **WSL 发行版启动时**自动起(打开终端 / `wsl` 命令 / Windows 任务计划拉起 WSL),并非 Windows 登录即起,除非你另行让 WSL 随 Windows 自启。

## 安装(需要 sudo)

```bash
sudo install -m644 /home/zqx/workspace/InkPulse/software/hub/deploy/inkpulse-hub.service \
  /etc/systemd/system/inkpulse-hub.service
sudo systemctl daemon-reload
sudo systemctl enable --now inkpulse-hub
```

## 验证

```bash
systemctl status inkpulse-hub          # active (running) 即成功
curl -s localhost:8080/health          # {"ok":true}
journalctl -u inkpulse-hub -f          # 跟踪日志
```

## 常用操作

```bash
sudo systemctl restart inkpulse-hub    # 改代码后重启
sudo systemctl stop inkpulse-hub       # 临时停(开发时手动 run.sh 前先停, 免端口冲突)
sudo systemctl disable inkpulse-hub    # 取消自起
```

## 自定义

- 换端口/配置:在 `[Service]` 段加 `Environment=INKPULSE_PORT=9000` 或 `Environment=INKPULSE_CONFIG=/home/zqx/my.yaml`,改后 `daemon-reload` + `restart`。
- 首次启动若 `.venv` 不存在,`run.sh` 会自动建 venv 并 `pip install -e .`(需联网,耗时);稳态下已建好则直接起。

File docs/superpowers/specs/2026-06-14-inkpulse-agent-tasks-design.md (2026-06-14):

# InkPulse 工作任务桥(Claude Code ↔ Hub)设计文档

> 日期:2026-06-14 · 状态:已通过设计评审,待写实现计划
> 关联:`/ingest/claude-status` + `hooks/claude_status.sh`(已有的状态上报雏形)· 待办/日程(手工录入 widget)

## 1. 背景与目标

现有 hub 的数据多靠用户在 `/config` 手工增删。本设计打通 **Claude Code 会话 → hub** 的自动管道,把"我正在干什么"实时推上墨水屏,减少手工维护:

- **A 实时镜像(确定性/hook)**:Claude Code 的 TodoWrite 任务列表随会话变化,经 PostToolUse hook 自动推到屏上。
- **B 按需提炼(skill)**:用户在会话里调用一个 skill,让 AI 提炼当前"工作焦点/持久行动项"推上去。

与手工 `todos` **解耦**:Agent 数据进独立存储 + 专属 widget,互不影响。本期只做 **Claude Code**(Codex 以后再加适配脚本,hub 端接口平台无关)。

### 已核实的机制前提(Claude Code hooks)
- `PostToolUse` hook 支持 `"matcher": "TodoWrite"`。
- hook stdin JSON 含:`tool_name`、`tool_input`(TodoWrite 的 `todos` 数组:`content`/`status`/`activeForm`,`status∈{pending,in_progress,completed}`)、`tool_response`、`cwd`、`session_id`、`transcript_path`。
- shell hook 可读 stdin 并 `curl` POST 到本地;`exit 0` 不阻塞会话(沿用 `claude_status.sh` 策略)。

## 2. 范围

### 本期做(In Scope)
- hub 存储 `AgentTaskStore`(`~/inkpulse/agent_tasks.json`):接收/合并/读取"最近活跃"会话快照。
- hub 端点 `POST /ingest/agent-tasks`。
- `state` 注入 `agent_tasks`;屏上 widget `draw_agent_tasks`,注册为 `agent_tasks`。
- 客户端(随仓库发布 + 安装说明):
  - A:`hooks/inkpulse_agent_tasks.sh`(PostToolUse(TodoWrite) 脚本)+ `~/.claude/settings.json` hooks 片段。
  - B:`skills/inkpulse-sync/SKILL.md`(用户调用的提炼-推送技能)。
- 配套测试。

### 本期不做(Out of Scope / YAGNI)
- 多项目并排显示(只显示最近活跃的单一项目)。
- 跨会话历史 / 任务归档。
- 屏 → 会话的反向控制。
- Codex 适配(hub 接口已平台无关,后续加脚本即可)。
- 把 agent 任务回写进手工 `todos`。
- AI 自动(无人触发)提炼——B 需用户显式调用 skill。

## 3. 决策记录(brainstorm 结论)

| 决策点 | 选择 | 理由 |
|---|---|---|
| 平台 | **先 Claude Code** | 已有状态 hook 基础;TodoWrite+PostToolUse 支撑 A;集成面不翻倍 |
| 待办来源 | **A 镜像 + B 提炼都做** | A 实时确定性,B 按需 AI 判断 |
| 存储 | **独立 `agent_tasks` + 专属 widget** | 与手工 `todos`(长期个人提醒)生命周期不同,解耦防冲掉 |
| 多会话 | **最近活跃者胜出,单一视图** | 贴合"我现在在干嘛";屏上信息聚焦 |
| A 机制 | **PostToolUse(TodoWrite) 实时推送** | 已验证可行;比 hub 轮询 transcript 简单实时 |

## 4. 架构总览

```
Claude Code 会话(任一项目)
 ├─ A: PostToolUse hook (matcher "TodoWrite")
 │    hooks/inkpulse_agent_tasks.sh: 读 stdin JSON → 取 tool_input.todos + cwd
 │    → POST /ingest/agent-tasks {project: basename(cwd), tasks:[{content,status}]}
 └─ B: skill /inkpulse-sync(用户调用)
      AI 提炼当前焦点/行动项 → POST /ingest/agent-tasks {project, highlights:[...]}

hub:
 POST /ingest/agent-tasks → AgentTaskStore(cfg.agent_tasks_store) 写入(按 project 合并)
 build_render_state(now) → state["agent_tasks"] = store.current(now)
 render: placement(widget="agent_tasks")
   └─ _agent_tasks 适配器 → draw_agent_tasks(d, z, state["agent_tasks"])
```

合并规则(单一"最近活跃"快照):
- POST 带 `project` + (可选)`tasks` 和/或 `highlights` + 服务器侧记 `updated_at`。
- **同项目**:更新本次 POST 提供的字段(只给 tasks 则只更新 tasks,highlights 保留;反之亦然)。
- **不同项目**:整体替换为新快照(新 project + 本次字段;另一字段清空)。

### 模块划分(单一职责)
- `collectors/agent_tasks.py`(新增):`AgentTaskStore` —— 读写 + 合并 + `current`。
- `config.py`(改):`agent_tasks_store` 路径字段 + sources 覆盖。
- `state.py`(改):`HubState` 持 store;`build_render_state` 注入 `agent_tasks`。
- `server.py`(改):`POST /ingest/agent-tasks`。
- `render/widgets.py`(改):`draw_agent_tasks`。
- `render/registry.py`(改):注册 `agent_tasks`。
- 客户端:`hooks/inkpulse_agent_tasks.sh`、`skills/inkpulse-sync/SKILL.md`、安装说明(`deploy/README.md` 增补或新文件)。

## 5. 数据模型

### 5.1 存储(`~/inkpulse/agent_tasks.json`)
单一"最近活跃"快照:
```jsonc
{
  "project": "InkPulse",
  "updated_at": 1718000000.0,
  "tasks": [{"content": "写 ingest 端点", "status": "in_progress"},
            {"content": "实现 widget", "status": "pending"}],
  "highlights": ["记得给解析加测试"]
}
```
- `status ∈ {pending, in_progress, completed}`(与 TodoWrite 一致;未知值当 pending)。
- `highlights`:字符串列表(B 提炼),可空。
- 文件不存在/损坏(非 dict / JSON 错)→ 视为空(`current` 返回 None),不抛异常。

### 5.2 `AgentTaskStore`(`collectors/agent_tasks.py`)
```python
class AgentTaskStore:
    def __init__(self, path): ...
    def ingest(self, now, project, tasks=None, highlights=None) -> None:
        # 读旧快照; 若旧.project == project: 合并(仅覆盖传入的非 None 字段);
        # 否则: 新建快照(project + 传入字段, 另一字段为 [] )。统一写 updated_at=now。
        # tasks 规范化: 每项取 {content:str, status:str(三值, 否则 pending)}, 丢弃空 content。
    def current(self, now) -> dict | None:
        # 返回 {project, tasks, highlights, age_s}; 无快照 -> None
```
- `ingest` 的 `tasks`/`highlights` 任一可为 None(表示"本次不更新该字段")。

## 6. 屏上 widget(`draw_agent_tasks`)

```
┌ 工作中 · InkPulse ──────┐
│ ■ 写 ingest 端点           │  ← in_progress
│ □ 实现 agent_tasks widget  │  ← pending
│ ✓ 探索 hook 机制           │  ← completed(带删除线)
│ · 记得给解析加测试          │  ← highlights(有才显示)
│              活跃于 2 分钟前 │
└──────────────────────────┘
```
- 顶部 `_title_bar(f"工作中 · {project}")`(project 超长截断;无 project 兜底「工作中」)。
- `agent_tasks` 为 None → 居中提示「无活动会话」,return。
- 任务行(按存储顺序,按高度截断):状态标记 + content(超长截断):
  - `in_progress` → `■`;`completed` → `✓` + 删除线;其余(pending) → `□`。(字形:`■`/`□`/`✓` 思源黑已确认存在。)
- highlights(若非空):分隔后每条前缀 `·`,同样截断。
- 右下角:`age_s` → 「活跃于 X 分钟前」;若 `age_s` 超过 `STALE_S`(2 小时)→ 显示「会话可能已结束」。
- 纯黑,无红。
- 签名 `draw_agent_tasks(d, z, data)`,`data` 为 `current(now)` 的返回(含 `age_s`)或 None。

## 7. API(`server.py`)

| 方法 | 路径 | 说明 |
|---|---|---|
| POST | `/ingest/agent-tasks` | body `{project, tasks?, highlights?}`;`project` 空 → 400;`tasks`/`highlights` 缺省表示不更新该字段;调用 `store.ingest(time.time(), ...)` |

- 与现有 `/ingest/claude-status` 同风格(内网上报口,轻校验)。
- `tasks` 元素非 dict / 缺 content 的由 store 规范化时丢弃。

## 8. 客户端(随仓库发布)

### 8.1 A:`hooks/inkpulse_agent_tasks.sh`(PostToolUse TodoWrite)
- 读 stdin JSON;用 `python3 -c`(或 jq)取 `tool_input.todos`(→ `[{content,status}]`)与 `cwd`;`project=basename(cwd)`。
- `curl -s -m 2 -X POST $HUB/ingest/agent-tasks -d '{"project":...,"tasks":[...]}'`;`|| true`;`exit 0`。
- `~/.claude/settings.json` 片段:`hooks.PostToolUse[{matcher:"TodoWrite", hooks:[{type:"command", command:".../inkpulse_agent_tasks.sh"}]}]`。

### 8.2 B:`skills/inkpulse-sync/SKILL.md`
- 描述:用户调用后,让模型**提炼当前会话的工作焦点/持久行动项**(2~5 条简短中文),取当前项目名,`curl` POST 到 `/ingest/agent-tasks` 的 `highlights`(不动 tasks)。
- 仅在用户显式调用时运行(不自动)。

### 8.3 安装说明
- 在 `deploy/README.md`(或新增 `deploy/claude-code.md`)写清:拷脚本、配 settings.json hooks、放 skill、`INKPULSE_HUB` 环境变量。

## 9. 错误处理

- agent_tasks.json 不存在/损坏 → `current` 返回 None,widget 显示「无活动会话」,不崩。
- POST 空 project → 400;tasks 元素畸形 → store 规范化丢弃,不崩。
- hook:hub 不可达 → `curl ... || true` + `exit 0`,绝不阻塞 Claude Code 会话。
- 过期快照(`age_s > STALE_S`)→ widget 标「会话可能已结束」(不自动删除,留最后状态)。
- 单 widget 异常仍由引擎 per-widget 隔离画 `n/a`。

## 10. 测试计划(pytest + 少量 hook 解析测)

- `AgentTaskStore`:首次 ingest 写 tasks;同项目再 ingest highlights → 两者并存;不同项目 ingest → 整体替换(旧字段清空);tasks 规范化(丢空 content / 未知 status→pending);坏文件 → current None;`current` 含 age_s。
- `state`:无快照 → `agent_tasks` None;注入新鲜快照 → dict。
- API:`POST /ingest/agent-tasks` 正常 / 空 project 400 / 只传 highlights 不动 tasks。
- `draw_agent_tasks`:各状态标记(■/□/✓)画出黑像素;highlights 段;空 → 提示不崩;过期 → 「会话可能已结束」;长内容截断不崩。
- `registry`:`agent_tasks` 已注册,注入 state 下绘制不抛错。
- hook 脚本:把 stdin 解析逻辑写成可独立调用的小段(`python3 -c` 同款),给样例 TodoWrite stdin JSON 验证产出的 POST body(`tasks`+`project`)。

## 11. 新增依赖

无。hub 端标准库 + 现有栈;客户端用 `python3`/`curl`(系统自带)。

## 12. 验收标准

1. Claude Code 会话里 TodoWrite 变化时,屏上 `agent_tasks` widget 自动显示该会话任务(状态标记)+ 项目名 + 新鲜度。
2. 用户调用 `/inkpulse-sync` skill 后,屏上出现 AI 提炼的焦点(highlights),不影响 tasks。
3. 多会话切换时屏跟随最近活跃项目;无活动/坏文件不崩;过期标注会话可能已结束;hook 失败不阻塞会话。
4. 全部测试通过。

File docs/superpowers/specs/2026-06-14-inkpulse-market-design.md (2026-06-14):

# InkPulse 行情 widget(设计文档)

> 日期:2026-06-14 · 状态:已通过设计评审,待写实现计划
> 关联:天气 `weather`(联网范式:fetch+缓存+stale-while-revalidate,已归档)。第三期最后一块。

## 1. 背景与目标

第三期联网 widget 的收尾项:**行情**。在墨水屏上显示一组自选标的(**A股/指数 + 加密货币**)的现价与涨跌幅;标的在网页 `/config` 管理。复用天气立的联网范式(后台抓取 + 缓存 + 失败降级,渲染不阻塞网络)。

## 2. 范围

### 本期做(In Scope)
- `collectors/market.py`:两源抓取(腾讯 A股 / OKX 加密)+ 解析归一 + 带缓存的 `MarketService`(SWR)。
- 自选标的配置(runtime,网页增删):`market_symbols`。
- 屏上 widget `draw_market`:名称 + 现价 + 涨跌幅(涨红跌黑),注册为 `market`。
- `state` 注入当前行情(纯函数化,便于测试)。
- 网页 `/config` 行情卡片:增/删标的(类型 + 代码)。
- 配套 API 与测试。

### 本期不做(Out of Scope / YAGNI)
- K线 / 分时图 / 历史走势 / 盘口五档。
- 美股 / 港股 / 场外基金(本期只 A股+指数+加密;美股港股境内源不稳)。
- 涨跌停 / 阈值提醒、自选排序拖拽。
- 货币换算(加密以 OKX 计价币种原样显示,如 USDT)。

## 3. 决策记录(brainstorm 结论 + 实测)

| 决策点 | 选择 | 理由 / 实测 |
|---|---|---|
| 标的类型 | **A股/指数 + 加密** | 用户需求 A+C |
| A股源 | **腾讯 `qt.gtimg.cn`** | 实测可用、无 key、无需 Referer、支持逗号批量;**返回 GBK** 需解码;自带名称 |
| 加密源 | **OKX `www.okx.com/api/v5/market/ticker`** | 实测干净 JSON、无 key、代理可达;**Binance 实测被地域封锁**(restricted location)故弃用 |
| 抓取/缓存 | **复用天气 SWR** | 后台线程刷新,`current()` 只读缓存不阻塞渲染,失败降级旧缓存 |
| 刷新间隔 | **300 秒(5 分钟)** | 行情变化快于天气;每 /frame 本就 ~10min,5min TTL 触发后台刷新 |
| 涨跌配色 | **涨=RED,跌/平=BLACK** | 中国"红涨绿跌";e-ink 三色有红无绿,故涨用红、跌用黑 |
| 标的存储 | **`market_symbols` 进 RUNTIME_FIELDS** | 网页可调;runtime.json 存列表 |

## 4. 架构总览

```
/config 行情卡片 ──(增/删标的)──> /api/market/symbols ──> cfg.market_symbols + save_runtime + svc.clear()

板子 GET /frame → build_render_state(now):
  market_symbols 非空? → svc.current() 取缓存(命中即用)
                         svc.maybe_refresh(symbols, now)  # 过期/标的变更则后台线程抓取, 本次不等
                       → state["market"] = [{type,code,name,price,change_pct}, ...]
  为空? → state["market"] = []
render: placement(widget="market")
  └─ _market 适配器 → draw_market(d, z, state["market"])
```

要点:网络与渲染解耦(`current()` 只读缓存);解析为纯函数(注入字节/JSON),`MarketService` 的刷新决策(`_needs_refresh`)与同步抓取(`refresh_now`)分离、线程仅包装 —— 全部可单测,网络不真连。

### 模块划分(单一职责)
- `collectors/market.py`(新增):见 §5。
- `config.py`(改):`market_cache` 路径字段 + sources 覆盖;`market_symbols` 进 `RUNTIME_FIELDS`。
- `state.py`(改):`HubState` 持 `MarketService`;注入 `market` + 触发非阻塞刷新。
- `render/widgets.py`(改):新增 `draw_market`。
- `render/registry.py`(改):注册 `market`。
- `server.py`(改):`/api/market*` 端点。
- `web/config.html`(改):行情卡片。

## 5. `collectors/market.py`

### 5.1 常量与归一结构
```python
REFRESH_S = 300                       # 5 分钟
TIMEOUT_S = 8
TENCENT = "https://qt.gtimg.cn/q="    # 批量: 逗号拼接 cn 代码
OKX = "https://www.okx.com/api/v5/market/ticker?instId="
# 归一 quote: {"type": "cn"|"crypto", "code": str, "name": str,
#             "price": float, "change_pct": float}
```

### 5.2 抓取与解析(纯解析可单测)
```python
def _get_bytes(url) -> bytes: ...        # urlopen().read(); 网络seam, 测试 monkeypatch

def parse_tencent(text: str) -> dict:
    # 入参: 已 GBK 解码的一行 v_sh000001="1~名称~代码~现价~昨收~..~涨跌幅~..";
    # 取 名称=字段[1], 现价=float(字段[3]), change_pct=float(字段[32])
    # 返回 {type:"cn", code, name, price, change_pct}; 字段不足/非数值 -> 抛/None 由调用方跳过

def fetch_cn(codes: list) -> list:
    # 批量: _get_bytes(TENCENT + ",".join(codes)).decode("gbk"); 按行解析 parse_tencent
    # 每行失败跳过; 整体网络失败抛(由 refresh 吞)

def parse_okx(obj: dict, code: str) -> dict:
    # obj = OKX 响应; d=obj["data"][0]; last=float(d["last"]); open24h=float(d["open24h"])
    # change_pct = (last-open24h)/open24h*100; name = code 去 "-USDT" 等取基础符号(如 BTC)
    # 返回 {type:"crypto", code, name, price:last, change_pct}

def fetch_crypto(code) -> dict:
    # json.loads(_get_bytes(OKX + code)); parse_okx
```

### 5.3 `MarketService`(缓存 + SWR,结构同 `WeatherService`)
```python
def is_stale(fetched_at, now) -> bool: return (now - fetched_at) >= REFRESH_S

class MarketService:
    def __init__(self, cache_path): ...           # makedirs; Lock + _refreshing
    def _read_cache(self): ...                     # {fetched_at, sig, quotes}; 坏/缺 -> None
    def current(self) -> list:                     # 读缓存返回 quotes(无缓存 -> [])
    def clear(self): ...
    def _sig(self, symbols): ...                   # 标的签名(用于检测变更), 如 tuple(sorted(...))
    def _needs_refresh(self, symbols, now): ...     # 无缓存 / 标的变更 / is_stale
    def refresh_now(self, symbols, now, fetch_cn=fetch_cn, fetch_crypto=fetch_crypto):
        # 分流: cn 批量 fetch_cn, crypto 逐个 fetch_crypto; 单标的失败跳过
        # 成功项汇成 quotes(保持 symbols 顺序), 写缓存 {fetched_at:now, sig, quotes}
        # 整体异常吞掉记日志, 保留旧缓存
    def maybe_refresh(self, symbols, now, ...):     # _needs_refresh 才起 daemon 线程
```
- 缓存文件 `~/inkpulse/market_cache.json`:`{"fetched_at": float, "sig": [...], "quotes": [...]}`。坏/缺当无缓存。
- `current()` 不触网(渲染路径只调它 + `maybe_refresh`)。

## 6. 屏上 widget(`draw_market`)

```
┌ 行情 ─────────────────┐
│ 上证指数   4031.51  +1.12% │   ← 涨=红
│ 贵州茅台   1680.00  -0.45% │   ← 跌=黑
│ BTC       64544.6  +1.04% │
└──────────────────────┘
```
- 顶部 `_title_bar("行情")`。
- `quotes` 为空 → 居中提示「无标的 · 去网页添加」,return。
- 每行:名称(左,超长截断)+ 现价(中)+ 带符号涨跌幅(右,`+1.12%`/`-0.45%`)。
  - **涨跌幅 > 0 → RED;≤ 0 → BLACK**(名称与现价恒黑)。
  - 价格格式:`f"{price:.2f}"`(加密大数也用 2 位小数,够用)。
- 按 `zone.h` 估算可容纳行数,`quotes[:N]` 截断。
- 签名 `draw_market(d, z, quotes)`,`quotes=[{name,price,change_pct,...}]`。

## 7. API(`server.py`)

| 方法 | 路径 | 说明 |
|---|---|---|
| GET | `/api/market` | `{symbols: cfg.market_symbols, quotes: svc.current()}`,供网页显示当前 |
| GET | `/api/market/symbols` | 返回 `cfg.market_symbols` |
| POST | `/api/market/symbols` | body `{type,code}`;`type∈{cn,crypto}` 且 `code` 非空 → 追加并 `save_runtime`+`svc.clear()`;否则 400;重复(同 type+code)忽略 |
| DELETE | `/api/market/symbols` | body `{type,code}`(或 query),移除该标的 + `save_runtime`+`svc.clear()` |

- `code` 规范化:cn 去空格小写(如 `sh000001`);crypto 大写(如 `BTC-USDT`)。具体规范化在 server 入口做。

## 8. 网页 `/config` 行情卡片

- 列出 `market_symbols`:`类型 代码  ×`(× 删除)。
- 录入行:类型下拉(A股/指数=cn、加密=crypto)+ 代码输入(占位提示:cn 填 `sh000001`/`sh600519`,crypto 填 `BTC-USDT`)+「添加」。
- 增删后刷新本卡片 + `refreshPreview()`。

## 9. 错误处理

- `market_symbols` 为空 → widget「无标的 · 去网页添加」;`/api/market` 的 `quotes` 为 `[]`。
- 首次无缓存 → widget 同空提示(后台已起刷新,下帧即有);为简化不单设"加载中"态(行情非首屏关键)。
- 单标的抓取/解析失败 → 跳过该标的,其余正常;整源网络失败 → 后台线程吞异常、保留旧缓存。
- 缓存文件坏/缺 → 当无缓存,不崩。
- GBK 解码失败 → 该批 cn 解析跳过(不崩)。
- POST 非法 type / 空 code → 400。
- 并发刷新 `_refreshing` 标志防抖;daemon 线程不挂起进程。
- 单 widget 异常仍由引擎 per-widget 隔离画 `n/a`。

## 10. 测试计划(pytest,**不真连网络**)

- `parse_tencent`:样例(GBK 解码后的)行 → 名称/现价/涨跌幅;字段不足/非数值不崩(跳过)。
- `parse_okx`:样例 OKX JSON → last/change_pct 计算;name 取基础符号。
- `fetch_cn`/`fetch_crypto`:monkeypatch `_get_bytes` 返回样例字节(cn 给 GBK 编码字节)→ 归一结构;批量多行;单行坏跳过。
- `is_stale`:边界。
- `MarketService`:注入假 `fetch_cn`/`fetch_crypto` + 控 `now` —— 无缓存刷新、新鲜不刷、标的变更刷新(`_sig`)、`refresh_now` 写缓存、单标的失败仍写其余、整体失败保留旧缓存、`current` 无缓存返回 `[]`、`clear`。
- `state`:无标的 → `market` `[]`;有标的 + 注入新鲜缓存 → `market` 为 list。
- `draw_market`:有数据画黑+红像素(涨红);空 → 提示不崩;全跌(无红)只黑;长名截断不崩。
- API:GET 结构;POST 加 / 非法 type 拒 / 空 code 拒 / 重复忽略;DELETE。
- `registry`:`market` 已注册,注入 state 下绘制不抛错。

## 11. 新增依赖

无。`urllib`/`json`/`threading`/`bytes.decode("gbk")`(GBK 编解码是 Python 标准库内置 codec)均标准库。

## 12. 验收标准

1. 网页能增删自选标的(A股/指数 + 加密);屏上 `market` widget 显示各标的名称+现价+涨跌幅,涨红跌黑。
2. 网络后台抓取不阻塞渲染;单标的失败跳过、整源失败用旧缓存,不崩。
3. 无标的/坏缓存不崩;非法标的被 API 拒。
4. 全部测试通过(网络部分 mock,不真连)。

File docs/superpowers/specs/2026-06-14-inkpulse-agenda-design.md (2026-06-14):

# InkPulse 日程 widget(设计文档)

> 日期:2026-06-14 · 状态:已通过设计评审,待写实现计划
> 关联:待办 `todos`(本地录入范式)· 月历 `calendar` · 天气 `weather`(已归档)。第三期原计划联网,但日程无可靠外部来源(用户无可用 ICS),故落地为**本地录入打样**。

## 1. 背景与目标

第三期日程 widget。原设想订阅外部日历(ICS),但用户**当前没有可靠的 ICS 来源**,故本期不联网,做一个**本地录入的最小可用日程板**:用户在网页 `/config` 添加日程(标题 + 日期 + 可选时间),墨水屏按时间排出近期日程、过期自动隐去。定位是"打样",刻意精简。

与现有 `todos` 的区别:日程带**具体日期/时刻**,按时间排序、按相对日(今天/明天/日期)标注、过期自动消失;`todos` 是无时间的勾选清单。

## 2. 范围

### 本期做(In Scope)
- 事件存储 `EventStore`(`~/inkpulse/events.json`):增/删/列表 + `upcoming` 过滤排序。仿 `TodoStore`。
- 屏上 widget `draw_agenda`:近期日程列表(相对日标签 + 时间 + 标题),注册为 `agenda`。
- `state` 注入近期日程(纯函数化,便于测试)。
- 网页 `/config` 日程卡片:增/删 + 录入(标题 + 日期 + 可选时间)。
- 配套 API 与测试。

### 本期不做(Out of Scope / YAGNI)
- 订阅外部日历(ICS/CalDAV)—— 无可靠来源,留待以后。
- 重复事件、提醒/通知、条目编辑、起止时间段、地点/备注。
- 跨设备同步、农历/节假日联动(农历已在头部)。
- 屏上录入(墨水屏无输入)。

## 3. 决策记录(brainstorm 结论)

| 决策点 | 选择 | 理由 |
|---|---|---|
| 数据来源 | **本地手动录入** | 无可靠 ICS 来源;先打样 |
| 条目粒度 | **标题 + 日期 + 可选时间** | 填时间=定时事件,不填=全天;最贴合真实日程又不啰嗦 |
| 排序/范围 | **按 date+time 升序,只显 date≥今天,取前 N** | 议程式展示,过期自动隐去 |
| 过期判定 | **按日期**(date < 今天 隐去) | 简单;今天的事件当天整天都显示,不按时刻消失 |
| widget 名 | **`agenda`** | 区别于已有月历 `calendar` |

## 4. 架构总览

```
build_render_state(now)
  └─ EventStore(cfg.events_store).upcoming(now, AGENDA_LIMIT)
       → state["events"] = [{"id","title","date","time"}, ...]  # date≥今天, 升序

render: placement(widget="agenda")
  └─ _agenda 适配器 → draw_agenda(d, z, state["events"], state["now"])

网页 /config 日程卡片 ──(增/删)──> /api/events* ──> EventStore
```

设计要点:存储/过滤/排序在 `EventStore`;widget 为纯函数(注入事件 + `now`),`now` 仅用于算"今天/明天"相对标签,测试确定性。

### 模块划分(单一职责)
- `collectors/events.py`(新增):`EventStore` —— events.json 读写 + add/delete/list + upcoming。
- `config.py`(改):新增 `events_store` 路径字段 + sources 覆盖。
- `state.py`(改):`HubState` 持 `EventStore`;`build_render_state` 注入 `events`。
- `render/widgets.py`(改):新增 `draw_agenda`。
- `render/registry.py`(改):注册 `agenda` widget + 适配器。
- `server.py`(改):`/api/events` 系列端点。
- `web/config.html`(改):日程卡片。

## 5. 数据模型

### 5.1 存储(`~/inkpulse/events.json`)
裸 JSON 列表(仿 `todos.json`),每条:
```jsonc
[{"id": "a1b2c3d4", "title": "团队周会", "date": "2026-06-14", "time": "14:30"},
 {"id": "...",        "title": "交报告",   "date": "2026-06-14", "time": ""}]   // time="" = 全天
```
- `id`:`uuid4().hex[:8]`(同 `TodoStore`)。
- 文件不存在/损坏(非列表/JSON 错)→ 视为空 `[]`,不抛异常。

### 5.2 `EventStore`(`collectors/events.py`)
```python
AGENDA_LIMIT = 8   # state 注入上限(widget 再按高度截断)

class EventStore:
    def __init__(self, path): ...
    def list(self) -> list[dict]:          # 全部, 按 (date, time) 升序; time="" 视为最早("00:00"前)
    def add(self, title, date, time="") -> dict:   # 追加, 返回新条目; 调用方已校验
    def delete(self, eid) -> None
    def upcoming(self, now, limit) -> list[dict]:  # date >= 今天(由 now 求) 的, 升序, 取前 limit
```
- 排序键:`(date, time or "00:00")` —— 全天事件(`time=""`)排在当天定时事件之前。
- `今天` 由 `now`(unix 秒)经 `date.fromtimestamp(now).isoformat()` 求;`upcoming` 保留 `date >= 今天` 的条目。

## 6. 屏上 widget(`draw_agenda`)

```
┌ 日程 ──────────────────┐
│ 今天 14:30  团队周会         │
│ 今天 全天   交报告           │
│ 明天 09:00  体检             │
│ 6/18 周三 19:00 看演出       │
└───────────────────────┘
```
- 顶部 `_title_bar("日程")`。
- `events` 为空 → 居中提示「无日程 · 去网页添加」,return。
- 每行:**相对日标签** + 时间 + 标题:
  - 相对日:`date==今天`→「今天」;`==明天`→「明天」;否则「`M/D 周X`」(周X 用 `_WEEKDAYS`)。
  - 时间:`time` 非空→`time`(如 `14:30`);空→「全天」。
  - 标题:超长按宽度截断(同 `draw_todos`)。
- 按 `zone.h` 估算可容纳行数,`events[:N]` 截断。
- 纯黑,无红。
- 签名:`draw_agenda(d, z, events, now)`,`events=[{"title","date","time"}, ...]` 已升序。

## 7. API(`server.py`)

| 方法 | 路径 | 说明 |
|---|---|---|
| GET | `/api/events` | 返回全部日程(`list()`,升序),供网页渲染 |
| POST | `/api/events` | body `{title,date,time}`;`title` 空白 → 400;`date` 非 `YYYY-MM-DD` → 400;`time` 非空且非 `HH:MM` → 400 |
| DELETE | `/api/events/{id}` | 删除该日程 |

- 校验:`date` 用 `datetime.date.fromisoformat` 解析失败 → 400;`time` 非空时用 `datetime.time.fromisoformat`(或正则 `HH:MM`)校验失败 → 400。
- 增删后网页刷新本卡片 + 调 `refreshPreview()`(沿用现有模式)。

## 8. 网页 `/config` 日程卡片

- 列出每条日程:`日期 时间  标题  ×`(`×` 删除)。按 `GET /api/events` 顺序。
- 录入行:标题输入框 + `<input type=date>` + `<input type=time>`(可留空)+「添加」。
- 添加/删除后刷新本卡片 + `refreshPreview()`。

## 9. 错误处理

- events.json 不存在/损坏 → 当空 `[]`,不崩。
- POST 空标题 / 坏日期 / 坏时间 → 400。
- `events` 为空 → widget「无日程 · 去网页添加」。
- 单 widget 异常仍由引擎 per-widget 隔离画 `n/a`。

## 10. 测试计划(pytest)

- `EventStore`:add/list/delete;`list` 按 (date,time) 升序、全天排当天之前;`upcoming` 过滤过期(date<今天)并取前 limit;损坏文件当空;持久化跨实例。
- `state`:`build_render_state` 含 `events`(list)。
- `draw_agenda`:有数据画黑像素;空 → 提示不崩;今天/明天/日期标签与"全天"分支均不崩;长标题截断不崩。
- API:GET 结构;POST 加 / 空标题拒 / 坏日期拒 / 坏时间拒;DELETE。
- `registry`:`agenda` 已注册,注入 state 下绘制不抛错。

## 11. 新增依赖

无。复用现有 Pillow / 标准库(`datetime`/`uuid`/`json`)。

## 12. 验收标准

1. 网页能新增/删除日程(标题+日期+可选时间);屏上 `agenda` widget 按时间排出近期日程,相对日标签 + 时间/全天 + 标题,过期自动隐去。
2. 无日程/坏文件不崩;坏日期/坏时间/空标题被 API 拒。
3. 全部测试通过。

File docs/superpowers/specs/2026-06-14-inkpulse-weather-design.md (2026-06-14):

# InkPulse 天气 widget(设计文档)

> 日期:2026-06-14 · 状态:已通过设计评审,待写实现计划
> 关联:第二期数据 widget(已归档 `docs/superpowers/archive/`)。**第三期(联网 widget)的第一个**。

## 1. 背景与目标

第三期做需要**对外请求第三方 API** 的 widget(前两期全是本地数据、零联网)。本设计是第三期第一个:**天气**。

目标:在墨水屏上显示某地点的**当前天气 + 未来 3 天预报**;地点由用户在网页 `/config` 搜索城市设定。这是项目首个联网 widget,重点是把"联网"的复杂度(失败降级、缓存、不阻塞渲染)处理干净,为后续日程/行情 widget 立范式。

## 2. 范围

### 本期做(In Scope)
- 数据源 Open-Meteo(免费、**无需 API key**),标准库 `urllib.request` 抓取(零新依赖)。
- `collectors/weather.py`:抓取 + 解析 + 地理编码 + 带缓存的 `WeatherService`(stale-while-revalidate)。
- 网页 `/config` 天气地点卡片:城市搜索 → 选定 → 存坐标到 runtime。
- 屏上 widget `draw_weather`:当前天气(手绘图标 + 中文词 + 当前温度)+ 今日高低 + 未来 3 天预报 + 缓存新鲜度。注册为 `weather`。
- 配套 API 与测试。

### 本期不做(Out of Scope / YAGNI)
- 空气质量 / AQI(Open-Meteo 另一套接口,后续再说)。
- 逐小时预报、降水概率、风力风向、日出日落、生活指数。
- 多地点切换 / 收藏夹(只存一个地点)。
- IP 自动定位(本机常开代理 TUN,IP 会解析到代理出口节点的城市,必然错;故只用网页手动配)。
- 天气预警推送 / 阈值标红(纯黑显示)。
- 字体天气符号字形(思源黑缺失严重,改用 Pillow 手绘图标)。

## 3. 决策记录(brainstorm 结论)

| 决策点 | 选择 | 理由 |
|---|---|---|
| 数据源 | **Open-Meteo** | 完全免费、**无需 key**、全球、当前+逐日齐全;换源只影响一个模块 |
| HTTP | **标准库 `urllib.request`** | 零新依赖,延续项目最小依赖原则 |
| 定位 | **网页手动配地点(地理编码)** | IP 定位因代理 TUN 必然错;`/config` 搜城市最稳且契合现有模式 |
| 抓取时机 | **stale-while-revalidate,后台线程刷新** | 渲染**绝不阻塞网络**(否则一帧卡在超时上,叠加 e-ink 21s 很糟) |
| 刷新间隔 | **30 分钟** | 天气变化慢,避免每帧打 API |
| 展示 | **手绘图标 + 中文天气词 + 温度** | 图标比纯文字好看;字体符号字形缺失,故 Pillow 自绘(同打卡/曲线画法) |
| 图标 | **7 类**(晴/多云/阴/雾/雨/雪/雷) | WMO 码归并,绘制函数可控 |

## 4. 架构总览

```
/config 搜城市 → GET /api/weather/search?q=杭州 → geocode() → 候选[{name,lat,lon,admin}]
  用户选定 → POST /api/weather/location {lat,lon,name} → 存 runtime + 清 weather_cache

板子 GET /frame → build_render_state(now):
  有坐标? → svc.current(now) 取缓存(命中即用)
            svc.maybe_refresh(lat, lon, now)  # 过期/坐标变更则起后台线程抓取, 本次不等
          → state["weather"] = {...解析数据, "age_s", "status"}  (无缓存则 None)
            state["weather_place"] = "杭州"
  无坐标? → state["weather"] = None; state["weather_place"] = None
render: placement(widget="weather")
  └─ _weather 适配器 → draw_weather(d, z, state["weather"], state["weather_place"])
```

设计要点:**网络与渲染解耦**——渲染只读缓存,刷新在后台线程;`parse_weather` 为纯函数(注入 JSON + now),`is_stale` 为纯函数,均确定性可测;网络抓取(`fetch_weather`/`geocode`)隔离在薄薄一层,单测不真连(mock `urlopen` 或只测解析)。

### 模块划分(单一职责)
- `collectors/weather.py`(新增):见 §5。
- `config.py`(改):`weather_cache` 路径字段 + `sources` 覆盖;`weather_lat`/`weather_lon`/`weather_place` 进 `RUNTIME_FIELDS`。
- `state.py`(改):`HubState` 持 `WeatherService`;`build_render_state` 注入 `weather`/`weather_place` 并触发非阻塞刷新。
- `server.py`(改):`/api/weather*` 端点。
- `render/widgets.py`(改):`draw_weather` + 7 图标 helper。
- `render/registry.py`(改):注册 `weather`。
- `web/config.html`(改):天气地点卡片。

## 5. `collectors/weather.py`

### 5.1 WMO 天气码 → 中文 + 图标类别
```python
# 类别枚举: "sun" "partly" "cloud" "fog" "rain" "snow" "thunder"
# WMO_CN[code] = (中文词, 类别)
# 0 晴/sun; 1 晴/sun; 2 多云/partly; 3 阴/cloud;
# 45,48 雾/fog; 51..57 毛毛雨/rain; 61..67 雨(小/中/大)/rain;
# 71..77 雪/snow; 80..82 阵雨/rain; 85,86 阵雪/snow; 95..99 雷阵雨/thunder
```
未知码 → `("未知", "cloud")` 兜底。

### 5.2 抓取与解析
```python
OPEN_METEO = "https://api.open-meteo.com/v1/forecast"
GEOCODE = "https://geocoding-api.open-meteo.com/v1/search"
TIMEOUT_S = 8

def fetch_weather(lat, lon) -> dict:
    # urlopen(OPEN_METEO?latitude=&longitude=&current=temperature_2m,weather_code
    #         &daily=weather_code,temperature_2m_max,temperature_2m_min
    #         &timezone=auto&forecast_days=4, timeout=TIMEOUT_S) -> json.load
    # 抛 URLError/超时/JSON 错由调用方处理

def parse_weather(raw: dict, now: float) -> dict:
    # 纯函数。返回:
    # {"cur_temp": float, "cur_code": int, "cur_cn": str, "cur_cat": str,
    #  "today_hi": float, "today_lo": float,
    #  "days": [{"label": "明"/"周三", "cn", "cat", "hi", "lo"}, ...3条]}  # 未来3天
    # label: 明天="明", 其余用 _WEEKDAYS; 日期对齐用 daily.time

def geocode(name) -> list[dict]:
    # urlopen(GEOCODE?name=&count=5&language=zh) -> [{"name","lat","lon","admin"}]
    # 无结果/失败 -> []
```

### 5.3 缓存与 SWR(`WeatherService`)
```python
REFRESH_S = 1800   # 30 分钟

def is_stale(fetched_at, now) -> bool:   # 纯函数
    return (now - fetched_at) >= REFRESH_S

class WeatherService:
    def __init__(self, cache_path): ...
    def current(self, now) -> dict | None:
        # 读缓存文件 {fetched_at, lat, lon, raw}; 无 -> None
        # 返回 {**parse_weather(raw, now), "age_s": now-fetched_at,
        #       "status": "ok"|"stale"}  (stale = is_stale)
    def maybe_refresh(self, lat, lon, now) -> None:
        # 若无缓存 或 缓存坐标≠当前坐标 或 is_stale: 且当前无刷新在跑 ->
        #   起 daemon 线程: fetch_weather -> 写缓存 {fetched_at:now,lat,lon,raw}
        #   线程内异常 try/except 吞掉(记 print), 不抛
        # 用 threading.Lock + _refreshing 标志防并发
    def clear(self) -> None:   # 删缓存文件(改地点时调)
```
- 缓存文件 `~/inkpulse/weather_cache.json`:`{"fetched_at": float, "lat": float, "lon": float, "raw": {...}}`。坏/缺 → 视为无缓存。
- `current` 不触发网络;`maybe_refresh` 才可能起线程。渲染路径只调 `current` + `maybe_refresh`(后者立即返回)。

## 6. 屏上 widget(`draw_weather`)

```
┌ 天气 · 杭州 ─────────────┐
│  (大图标) 多云   23°C     │
│           今日 26° / 18°   │
│ ───────────────────────  │
│ 明  (小)  27° / 19°       │
│ 周三(小)  24° / 17°       │
│ 周四(小)  22° / 16°       │
│              更新于 12 分钟前 │
└─────────────────────────┘
```
- 顶部 `_title_bar(f"天气 · {place}")`(无 place 时 `"天气"`)。
- 签名 `draw_weather(d, z, weather, place)`,**三态由 (place, weather) 区分**(无需额外标志):
  - `place is None` → 「未设置地点 · 去网页添加」(无坐标)。
  - `place` 有值 且 `weather is None` → 「加载中…」(有坐标但首次无缓存)。
  - `weather` 有值 → 正常态(下述)。
- 正常态:当前块大图标(§5.1 类别 → §6.1 绘制)+ 中文词 + 当前温度大字;今日高/低;分隔线;未来 3 天每行 小图标 + 高/低。
- 右下角:`age_s` → 「更新于 X 分钟前」(`status=="stale"` 也照常显示,数据即便旧也展示)。
- 纯黑无红。

### 6.1 七类图标(Pillow 手绘,字体无关)
`_wx_icon(d, cx, cy, r, cat)`:按 `cat` 画——
- `sun`:实心圆 + 8 条放射短线。
- `partly`:小太阳(圆+短线)左上 + 一朵云右下盖住部分。
- `cloud`:2~3 个叠圆 + 平底(空心或浅填)。
- `fog`:云 + 下方 3 条横线。
- `rain`:云 + 4~5 条斜短线。
- `snow`:云 + 3 个雪点(小圆/米字)。
- `thunder`:云 + 一条闪电折线(多段 `line`)。
大图标 `r` 大、预报行小图标 `r` 小,同一函数按 `r` 缩放。

## 7. API(`server.py`)

| 方法 | 路径 | 说明 |
|---|---|---|
| GET | `/api/weather/search?q=` | 代理 `geocode(q)`,返回候选 `[{name,lat,lon,admin}]`;空 `q` → `[]` |
| POST | `/api/weather/location` | body `{lat,lon,name}`,存进 runtime(`weather_lat/lon/place`)并 `save_runtime` + `svc.clear()`;缺字段 → 400 |
| DELETE | `/api/weather/location` | 清除地点(三字段置空)+ `save_runtime` + `svc.clear()` |
| GET | `/api/weather` | `{place, lat, lon, weather: current(now)或null}`,供 `/config` 显示当前 |

## 8. 网页 `/config` 天气地点卡片

- 搜索框 + 「搜索」:输入城市 → `GET /api/weather/search?q=` → 候选列表(每条 `名字 · 省/行政区`,点击即 `POST /api/weather/location`)。
- 顶部显示当前地点(`GET /api/weather` 的 `place`)+「清除」(`DELETE`)。
- 设置/清除后刷新本卡片 + `refreshPreview()`(沿用现有模式)。

## 9. 错误处理

- 无坐标 → widget「未设置地点 · 去网页添加」;API `/api/weather` 的 `weather` 为 null。
- 首次无缓存 → widget「加载中…」(后台已起刷新,下帧即有)。
- 抓取失败(网络/超时/解析)→ 后台线程吞异常记日志、不写缓存;`current` 仍返回上次缓存(`status` 可能 `stale`),widget 照常显示 + 「更新于 X 分钟前」;彻底无缓存才「加载中…」直至成功。
- `geocode` 无结果/失败 → 返回 `[]`,前端提示「没找到」。
- 并发刷新由 `_refreshing` 标志 + Lock 防抖;线程 daemon,进程退出不挂起。
- 缓存文件坏/缺 → 当无缓存,不崩。
- 单 widget 异常仍由引擎 per-widget 隔离画 `n/a`。

## 10. 测试计划(pytest,**不真连网络**)

- `parse_weather`:用样例 Open-Meteo JSON → 当前温度/天气码/中文词/类别正确;今日高低;未来 3 天 label(明/周X)与高低;各 WMO 段(0/2/3/45/61/71/80/95)映射到正确中文+类别;未知码兜底。
- `is_stale`:边界(刚好 30 分钟、之内、之外)。
- `WeatherService`:注入假 `fetch`(monkeypatch)+ 控 `now` —— 新鲜不刷;过期触发刷新写缓存;坐标变更触发刷新;`fetch` 抛异常时保留旧缓存不崩;无缓存 `current` 返回 None;`clear` 删缓存。
- `geocode`:mock `urlopen` 返回样例 JSON → 候选解析;空结果 → `[]`。
- `state`:无坐标 → `weather` None、`weather_place` None;有坐标(注入假缓存)→ `weather` 为 dict。
- `draw_weather`:正常数据画黑像素;7 类图标各画不崩;`place=None`→未设置提示;`place` 有值+`weather=None`→加载中;有黑像素、不崩。
- API:`search`(mock geocode)、`location` POST 存 runtime + 缺字段 400、`DELETE` 清除、`GET /api/weather` 结构。
- `registry`:`weather` 已注册,注入 state 下绘制不抛错。

## 11. 新增依赖

无。`urllib.request` / `json` / `threading` 均标准库。

## 12. 验收标准

1. 网页搜城市并选定后,屏上 `weather` widget 显示该地当前天气(图标+中文+温度)+ 今日高低 + 未来 3 天。
2. 网络抓取在后台进行,**不阻塞渲染**;抓取失败时显示上次缓存 + 新鲜度,不崩。
3. 未设地点显示提示;首次加载显示「加载中…」;坏缓存/无结果不崩。
4. 全部测试通过(网络部分以 mock/纯解析覆盖,不真连)。

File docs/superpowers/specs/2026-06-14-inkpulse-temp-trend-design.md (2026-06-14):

# InkPulse 温度曲线 widget(设计文档)

> 日期:2026-06-14 · 状态:已通过设计评审,待写实现计划
> 关联:网格布局系统(第一期,已归档)· 第二期只读 widget `usage_trend`/`project_dist`(已归档)· 习惯打卡(第二期,已合并)

## 1. 背景与目标

第二期数据 widget 的收尾项。板子(ESP32-S3 + HTU21D)每次拉帧 `GET /frame?t=..&h=..&rssi=..` 顺带上报温湿度;hub 现状只用 `set_env` 保存**最新一条**,无历史。湿度通道硬件损坏(I2C NACK,恒回哨兵值),仅温度有效,故本 widget 是**温度曲线**(非温湿度)。

目标:在墨水屏上画**最近 24 小时**的温度折线,叠加**当前温度大数字**与**24h 峰谷**,让人一眼看出室温现状与一天波动。需要新增历史存储(持久化,hub 重启不丢)。

## 2. 范围

### 本期做(In Scope)
- 历史存储 `EnvHistoryStore`(`~/inkpulse/env_history.json`):按时间追加温度采样 + 24h 裁剪 + 取窗口。
- `/frame` 入口:温度有效时追加一条采样。
- `state` 注入近 24h 采样(纯函数化,便于测试)。
- 屏上 widget `draw_temp_trend`:24h 温度折线 + 当前值大数字 + 高/低标记,注册为 `temp_trend`。
- 配套测试。

### 本期不做(Out of Scope / YAGNI)
- 湿度曲线(通道坏,无有效数据)。
- 网页端展示/配置温度历史(只读 widget,无交互)。
- 可配置时间窗 / 多档窗口(固定 24h)。
- y 轴刻度线 / 网格(墨水屏小字易糊,brainstorm 决定不做)。
- 高频采样 / 下采样固定槽(读数本就 ~10 分钟一个,直接画即可)。
- 温度报警 / 阈值标红(纯黑显示)。

## 3. 决策记录(brainstorm 结论)

| 决策点 | 选择 | 理由 |
|---|---|---|
| 时间窗 | **最近 24 小时** | 看一天昼夜温差节律;~144 点数据量可控 |
| 叠加信息 | **当前温度大数字 + 24h 高/低标记** | 信息够又不挤;y 轴刻度小字易糊,不做 |
| 存储 | **持久化环形(裁剪)列表落盘** | hub/板子重启不丢;仿 `TodoStore`/`HabitStore` 落盘模式 |
| 采样 | **每帧上报即存一条(~10min/点)** | `refresh_periodic_s=600`,读数天然稀疏,无需高频/下采样 |
| 峰谷标记字形 | **「高/低」中文字**,不用 `↑↓` 箭头 | 规避思源黑符号字形缺失风险 |
| 折线 x 轴 | **固定窗口 `[now-24h, now]` 映射** | 数据有空档显示为稀疏,不假装连续 |

## 4. 架构总览

```
板子 GET /frame?t=23.4&h=..&rssi=..
  └─ state.set_env(t,h,rssi)                 # 现有: 存最新一条(头部右上角用)
  └─ state.env_history.append(now, t)        # 新增: t 有效才追加, 顺手裁掉 >24h

build_render_state(now)
  └─ state["env_history"] = EnvHistoryStore(cfg.env_history_store).window(now)
       → [[ts:float, temp:float], ...]  近24h, 按 ts 升序

render: placement(widget="temp_trend")
  └─ _temp_trend 适配器 → draw_temp_trend(d, z, state["env_history"], state["now"])
```

设计要点:有效性过滤 + 裁剪 + 取窗口都在 `EnvHistoryStore`;widget 为纯函数(注入采样 + now),无 I/O 无时间调用,测试确定性。只存 `t` 不存 `h`,坏湿度数据自然被排除在外。

### 模块划分(单一职责)
- `collectors/env_history.py`(新增):`EnvHistoryStore` —— env_history.json 读写 + append(裁剪) + window。
- `config.py`(改):新增 `env_history_store` 路径字段 + `sources.env_history_store` 覆盖。
- `server.py`(改):`/frame` 里温度有效时 `state.env_history.append(time.time(), t)`。
- `state.py`(改):`HubState` 持有 store;`build_render_state` 注入 `env_history`。
- `render/widgets.py`(改):新增 `draw_temp_trend`。
- `render/registry.py`(改):注册 `temp_trend` widget + 适配器。

## 5. 数据模型

### 5.1 存储(`~/inkpulse/env_history.json`)
裸 JSON 列表(仿 `todos.json`),每条 `[unix秒(float), 温度(float)]`,按 ts 升序:
```jsonc
[[1749800000.0, 23.4], [1749800600.0, 23.6], [1749801200.0, 23.1]]
```
- 文件不存在/损坏(非列表/JSON 错)→ 视为空 `[]`,不抛异常。

### 5.2 `EnvHistoryStore`(`collectors/env_history.py`)
```python
RETENTION_S = 86400          # 24h
TEMP_MIN, TEMP_MAX = -40.0, 85.0   # 合理温度范围(挡 None/哨兵/越界)

class EnvHistoryStore:
    def __init__(self, path): ...
    def append(self, ts: float, temp) -> None:
        # temp 为 None 或不在 [TEMP_MIN, TEMP_MAX] → 直接 return(不存)
        # 否则: 读 → 追加 [ts, float(temp)] → 裁掉 ts < (this_ts - RETENTION_S) → 写
    def window(self, now: float) -> list[list]:
        # 返回 ts >= now - RETENTION_S 的采样, 按 ts 升序
```
- 裁剪以"本次 append 的 ts"为基准(`ts - RETENTION_S`),避免依赖墙钟。
- `window` 再按传入的 `now` 过滤一次(渲染时刻可能晚于最后采样)。

## 6. 屏上 widget(`draw_temp_trend`)

```
┌ 温度曲线 24h ─────────┐
│                      23°C │   ← 当前温度大数字(右上, 末点温度)
│        ╭╮      ╭─╮         │
│   ╭───╯ ╰─╮  ╭╯  ╰──╮      │   ← 24h 折线(纯黑)
│ ──╯       ╰──╯      ╰───   │
│ 高 26°  低 18°             │   ← 24h 峰谷(左下, 中文字)
└──────────────────────────┘
```
- 顶部 `_title_bar("温度曲线 24h")`。
- 采样数 `< 2` → 居中提示「暂无温度数据」,return(不崩)。
- **当前值**:末点温度,右上角大字号 `f"{temp:.0f}°C"`。
- **折线**:
  - x:`ts` 在 `[now-86400, now]` 线性映射到 [zone 左, zone 右];数据有空档则点稀疏(只连相邻采样点)。
  - y:`temp` 在 `[tmin, tmax]` 映射到 [zone 下, zone 上](温度高→偏上);`tmin==tmax`(全等)时画水平中线避免除零。
  - 相邻采样点 `d.line` 连段;单段宽度由像素决定,不分桶。
- **峰谷**:窗口内 `max`/`min` 温度,左下角 `f"高 {tmax:.0f}°  低 {tmin:.0f}°"`(中文字,避开箭头字形)。
- 纯黑,无红。
- 签名:`draw_temp_trend(d, z, samples, now)`,`samples=[[ts,temp], ...]` 升序。

## 7. 集成点

- `config.py`:`Config` 加 `env_history_store: str = os.path.expanduser("~/inkpulse/env_history.json")`;`load_config` 加 `sources.env_history_store` 覆盖。
- `state.py`:`HubState.__init__` 加 `self.env_history = EnvHistoryStore(cfg.env_history_store)`;`build_render_state` 加 `"env_history": self.env_history.window(now)`。
- `server.py`:`/frame` 内 `set_env` 之后,`if t is not None: state.env_history.append(time.time(), t)`(有效性由 append 内部把关)。
- `registry.py`:适配器 `_temp_trend(d,img,z,state,cfg,p) → W.draw_temp_trend(d, z, state.get("env_history", []), state.get("now"))`;`REGISTRY` 加 `"temp_trend": WidgetSpec("temp_trend","温度曲线",_temp_trend,{"cols":4,"rows":3})`(无参数)。

## 8. 错误处理

- env_history.json 不存在/损坏 → 当空 `[]`,不崩。
- 温度 `None`/越界(挡哨兵/坏值)→ append 静默丢弃,不入库。
- 采样 `< 2` → widget 画「暂无温度数据」提示,不崩。
- 全等温度(`tmin==tmax`)→ 画水平中线,不除零。
- 单 widget 异常仍由引擎 per-widget 隔离画 `n/a`。

## 9. 测试计划(pytest)

- `EnvHistoryStore`:append 后 window 含该点;append 越界/None 不入库;超 24h 旧点被裁;损坏文件当空;持久化跨实例;window 按 now 过滤并升序。
- `state`:`build_render_state` 含 `env_history`(list)。
- `server`:`GET /frame?t=23.4` 后 `state.env_history.window(now)` 多一条;`t` 缺省不追加。
- `draw_temp_trend`:有数据画黑线;空/单点画提示不崩;全等温度不崩;当前值与峰谷文字出现(有黑像素)。
- `registry`:`temp_trend` 已注册,注入 state 下绘制不抛错。

## 10. 新增依赖

无。复用现有 Pillow / 标准库。

## 11. 验收标准

1. 板子上报温度后,屏上 `temp_trend` 显示近 24h 折线,右上当前值、左下高/低标记。
2. hub 重启后历史仍在(持久化生效)。
3. 无数据/坏文件/坏温度值不崩;湿度坏通道数据不入库。
4. 全部测试通过。

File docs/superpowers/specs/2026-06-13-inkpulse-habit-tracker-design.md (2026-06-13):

# InkPulse 习惯打卡 widget(设计文档)

> 日期:2026-06-13 · 状态:已通过设计评审,待写实现计划
> 关联:网格布局系统(第一期,已归档 `docs/superpowers/archive/`)· 第二期只读 widget(已归档)

## 1. 背景与目标

第二期规划的本地数据 widget 中,「用量趋势 / 项目分布」已完成(只读、零新存储)。本设计做第二期需要**新存储 + 交互**的第一个:**习惯打卡**。

目标:在墨水屏上以"本周打卡墙"展示若干习惯的坚持情况;用户在网页 `/config` 里管理习惯并逐日打卡(可补打本周已过的日子)。设备屏只读显示,不在屏上操作。

## 2. 范围

### 本期做(In Scope)
- 习惯存储 `HabitStore`(`~/inkpulse/habits.json`):习惯列表 + 按日完成记录。
- 屏上 widget `draw_habits`:本周(周一~周日)打卡墙,注册为 `habits`。
- `state` 注入本周打卡数据(纯函数化,便于测试)。
- 网页 `/config` 新增「习惯打卡」卡片:增/删习惯 + 点格子打卡(本周任意已到日期,未来禁用)。
- 配套 API 与测试。

### 本期不做(Out of Scope / YAGNI)
- 习惯改名、拖拽排序。
- 连续天数 / 完成率统计(brainstorm 时的备选 C 未采纳)。
- 提醒 / 通知。
- 跨周历史视图(只展示本自然周)。
- 屏上直接打卡(墨水屏无逐项输入)。

## 3. 决策记录(brainstorm 结论)

| 决策点 | 选择 | 理由 |
|---|---|---|
| 显示形式 | **7 天打卡墙**(习惯×本周7天) | 最能体现"打卡"、一眼看连续性 |
| 7 天语义 | **本周(周一~周日)** | 表头 `一..日` 固定;今天列描边;未来留空 |
| 周起始 | **周一**(Mon=0) | 与现有月历 `firstweekday=0` 一致 |
| 打卡操作 | **网页可点本周任意已到日** | 可补打/纠错;未来日禁用 |
| 参数 | **v1 无参数** | 显示全部习惯,放不下就截;先简单 |

## 4. 架构总览

```
build_render_state(now)
  └─ HabitStore(cfg.habits_store).week_view(now)
       → state["habits"]   = [{"name": str, "days": [bool×7 周一→周日]}, ...]
       → state["habit_today_idx"] = 0..6   # 今天是本周第几列(周一=0)

render: placement(widget="habits")
  └─ _habits 适配器 → draw_habits(d, z, state["habits"], state["habit_today_idx"])

网页 /config「习惯打卡」卡片  ──(增删/打卡)──>  /api/habits*  ──>  HabitStore
```

设计要点:存储与"本周视图计算"放在 `HabitStore` / `state`,widget 与网页只消费结构化数据;widget 为纯函数(注入数据),测试确定性。

### 模块划分(单一职责)
- `collectors/habits.py`(新增):`HabitStore` —— habits.json 读写 + 打卡切换 + 本周视图。
- `config.py`(改):新增 `habits_store` 路径字段 + `sources.habits_store` 覆盖。
- `state.py`(改):`build_render_state` 注入 `habits` / `habit_today_idx`。
- `render/widgets.py`(改):新增 `draw_habits`。
- `render/registry.py`(改):注册 `habits` widget + 适配器。
- `server.py`(改):新增 `/api/habits` 系列端点。
- `web/config.html`(改):新增「习惯打卡」卡片。

## 5. 数据模型

### 5.1 存储(`~/inkpulse/habits.json`)
```jsonc
{
  "habits": [ {"id": "a1b2c3d4", "name": "运动"}, {"id": "...", "name": "阅读"} ],
  "log": { "2026-06-13": ["a1b2c3d4", "..."],   // 该日完成的习惯 id 列表
           "2026-06-12": ["a1b2c3d4"] }
}
```
- `id`:`uuid4().hex[:8]`(同 TodoStore)。
- `log` 按日期(本地 `YYYY-MM-DD`)归集当天打卡的习惯 id。删除习惯时一并从各日 `log` 移除其 id。

### 5.2 `HabitStore`(`collectors/habits.py`)
```python
class HabitStore:
    def __init__(self, path): ...
    def list(self) -> list[dict]:                  # [{"id","name"}]
    def add(self, name) -> dict:                    # 追加, 返回新习惯
    def delete(self, hid) -> None:                  # 删习惯 + 清各日 log 里的该 id
    def toggle(self, hid, date_iso) -> None:        # 在 date_iso 切换该习惯打卡(增/删)
    def is_done(self, hid, date_iso) -> bool
    def week_view(self, now) -> tuple[list[dict], int]:
        # 返回 ([{"name","days":[bool×7 周一→周日]}, ...], today_idx)
```
- `date_iso` 形如 `"2026-06-13"`;空习惯列表时 `week_view` 返回 `([], today_idx)`。
- 文件不存在/损坏 → 视为空(`{"habits":[],"log":{}}`),不抛异常。

### 5.3 本周日期计算
- 周一为起点:`monday = today - timedelta(days=today.weekday())`;7 列为 `monday + i`(i=0..6)。
- `today_idx = today.weekday()`(周一=0 … 周日=6)。

## 6. 屏上 widget(`draw_habits`)

```
┌ 习惯打卡 ──────────┐
│        一 二 三 四 五 六 日 │
│ 运动   ■ ■ ■ [■] · · ·   │   [■]=今天列描边, ·=未来留空
│ 阅读   ■ □ ■ [□] · · ·   │   ■=打卡, □=已过未打
│ 喝水   ■ ■ ■ [■] · · ·   │
└──────────────────┘
```
- 顶部 `_title_bar("习惯打卡")`;其下一行星期表头 `一..日`(列与下方格对齐)。
- 每行:习惯名(左,超长截断)+ 7 个格子:
  - 列 `< today_idx` 或 `== today_idx`:`■`(已打卡,实心方块)/ `□`(未打,空心方块);
  - 列 `> today_idx`(未来):`·`(小点/留空,不可达)。
  - 今天列(`== today_idx`)在格子外描一圈细框强调。
- 字形使用确认存在的 `■`(U+25A0)/`□`(U+25A1)(思源黑已含);纯黑,无红。
- 习惯数超出可显示行数时按可容纳行数截断(同 `draw_todos` 的 `items[:N]` 思路,N 由 `zone.h` 估算)。
- 无习惯 → 居中提示「无习惯 · 去网页添加」。

签名:`draw_habits(d, z, habits, today_idx)`,`habits=[{"name","days":[bool×7]}]`。

## 7. API(`server.py`)

| 方法 | 路径 | 说明 |
|---|---|---|
| GET | `/api/habits` | `{habits:[{id,name}], week:[7个 "YYYY-MM-DD"], done:{hid:[bool×7]}, today_idx}`:供网页渲染本周格 |
| POST | `/api/habits` | body `{name}`,新增习惯;空名返回 400 |
| DELETE | `/api/habits/{id}` | 删除该习惯(含清 log) |
| POST | `/api/habits/{id}/toggle` | body `{date}`,切换该习惯在 date 的打卡;**date 晚于今天 → 400**;未知 id → 404 |

打卡后网页可调用现有 `/api/refresh` 让真机刷新(同待办/照片)。

## 8. 网页 `/config`「习惯打卡」卡片

- 列出每个习惯:`名字  [一][二][三][四][五][六][日]  ×`
  - 7 个格子按 `done` 矩阵着色;**今天及之前可点**(toggle),**未来禁用置灰**;
  - `×` 删除习惯。
- 底部:输入框 + 「添加」按钮新增习惯。
- 打卡/增删后刷新本卡片 + 调 `refreshPreview()`(沿用现有模式)。

## 9. 错误处理

- habits.json 不存在/损坏 → 当空处理,不崩。
- toggle 未知习惯 id → 404;未来日期 → 400。
- 新增空白名 → 400。
- widget:`habits` 为空 → "无习惯 · 去网页添加";单 widget 异常仍由引擎 per-widget 隔离画 `n/a`。

## 10. 测试计划(pytest)

- `HabitStore`:add/list/delete(含从 log 清 id)、toggle 增删往返、is_done、损坏文件当空、`week_view` 结构与 today_idx、空习惯返回 `([], idx)`。
- `state`:`build_render_state` 含 `habits`(list)与 `habit_today_idx`(0..6)。
- `draw_habits`:有数据画黑格;空习惯画提示不崩;未来列不画实心格;今天列有描边。
- API 契约:GET 结构;POST 加/空名拒;DELETE;toggle 正常 / 拒未来 / 未知 id 404。
- registry:`habits` 已注册,注入 state 下绘制不抛错。

## 11. 新增依赖

无。复用现有 Pillow / 标准库。

## 12. 验收标准

1. 网页能新增/删除习惯,并点本周任意已到日期格子打卡(未来禁用)。
2. 屏上 `habits` widget 显示本周打卡墙,今天列描边、未来留空,数据与网页一致。
3. 无习惯/坏文件不崩;toggle 未来日期被拒。
4. 全部测试通过。

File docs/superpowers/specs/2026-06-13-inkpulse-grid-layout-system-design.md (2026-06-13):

# InkPulse 数据驱动网格布局系统(设计文档)

> 日期:2026-06-13 · 状态:已通过设计评审,待写实现计划
> 关联:[显示系统设计](2026-06-09-inkpulse-display-system-design.md) · [固件分层架构](2026-06-12-inkpulse-firmware-layered-arch-design.md)

## 1. 背景与目标

当前 Hub 的布局是 6 个写死的 Python 函数(`dash/photo/usage/todo/clock/split`),分区坐标硬编码在各函数里(仅 `dash` 读 `cfg.layout` 配合固定 `ZONES`)。"自定义布局"=网页里选 1 个预设;改布局必须改代码,加功能要同时碰布局逻辑。

**目标(提高自由度)**:把布局从代码变成**数据**,让用户在网页里把屏幕切成网格、往格子里放任意 widget、存成自己命名的布局;同时让"加新功能"退化成"加一个 widget 函数 + 注册一行"。

本设计是**第一期(地基)**,只做布局引擎本身 + 编辑器 + 2 个验证 widget。后续两期(见 §9)在此之上增量加 widget。

## 2. 范围

### 本期做(In Scope)
- 数据驱动**网格渲染引擎**(固定网格 + 矩形跨格,模型 B)。
- **Widget 注册表**:统一签名 + 元数据(默认跨度、参数 schema),把现有 8 个 widget 适配进来。
- 布局以 **JSON** 存储(`layouts.json`):命名布局 = placements 列表。
- **网页网格编辑器**("点格子选 widget"版):框选矩形 → 选 widget → 填参数 → 保存命名布局;布局切换/新建/删除;复用现有实时预览。
- 把现有 **6 个预设迁移**成 `builtin` 布局(像素位置尽量还原,从此可编辑、不可删)。
- **2 个验证 widget**:`countdown`(倒计时/纪念日)、`qrcode`(二维码)——纯本地、零新数据管线。
- 配套 **API** 与 **测试**。

### 本期不做(Out of Scope / YAGNI)
- 鼠标拖拽缩放编辑(本期只"点格子",拖拽留后续)。
- L4 像素级自由画布。
- 第二/三期的 7 个 widget(天气、日程、行情、用量趋势、项目分布、习惯打卡、温湿度曲线)。
- 布局导入/导出/分享。

## 3. 决策记录(brainstorm 结论)

| 决策点 | 选择 | 理由 |
|---|---|---|
| 自由度档位 | **L3 网格自定义** | 布局变数据,自由度大涨而复杂度可控 |
| 网格模型 | **B 固定网格 + 跨格** | 像 CSS Grid,墨水屏上随意摆又自动对齐,编辑器好做 |
| 第一期范围 | **地基 + 2 极简 widget** | 先把引擎跑通,不被数据采集拖住 |
| 编辑器程度 | **点格子选 widget** | 够用、好实现;拖拽留后续 |
| 默认网格 | **8 列 × 6 行**(格子 100×80px) | 800×480 整除,48 格易点选,跨格仍灵活;数值可配 |

## 4. 架构总览

```
render_frame(cfg, state)
  └─ load_layout(cfg.layout_name)         # 读 layouts.json → Layout(grid, placements)
       └─ for placement in placements:
            zone = cell_to_zone(grid, placement)   # 网格坐标 → 像素 Zone
            spec = REGISTRY[placement.widget]       # 注册表查 widget
            spec.draw(d, zone, state, cfg, placement.params)   # 单 widget 隔离容错
```

设计要点:现有 widget 函数已统一接收 `Zone`,因此本改造**复用全部现有 widget**,改动集中在引擎与新增的注册表/布局存储/编辑器。

### 模块划分(每个单元单一职责)
- `render/registry.py`(新增):`WidgetSpec` 数据类 + `REGISTRY` 字典 + 现有 widget 的薄适配器。依赖 `widgets.py`。
- `render/grid.py`(新增):`cell_to_zone()` 网格→像素换算;`Layout`/`Placement` 数据类。无副作用、纯函数,易测。
- `layouts.py`(新增):`layouts.json` 的加载/保存/迁移/校验。依赖 `grid.py`。
- `render/engine.py`(改):`render_frame` 改走数据驱动路径;退役 6 个 `draw_xxx`(逻辑转为 builtin 布局数据)。
- `render/widgets.py`(改):新增 `draw_countdown`、`draw_qrcode`。
- `server.py`(改):新增 `/api/layouts` 系列端点。
- `web/config.html`(改):新增网格编辑器区。

## 5. 数据模型

### 5.1 Widget 注册表(`render/registry.py`)
```python
@dataclass
class WidgetSpec:
    name: str                       # 唯一 key,如 "countdown"
    label: str                      # 中文显示名,如 "倒计时"
    draw: Callable                  # fn(d, zone, state, cfg, params) -> None
    default_span: dict              # {"cols": 3, "rows": 2} 拖入时默认大小
    params: list[dict]              # [{"key","label","type","default"}],编辑器据此生成表单

REGISTRY: dict[str, WidgetSpec]     # name -> spec
```
- 现有 widget 各写一个适配器把旧签名包成统一签名后登记:
  `header / claude_status / usage / usage_ring / todos / big_clock / month_calendar / photo`。
- `params` 的 `type` 第一期支持:`text`、`date`、`number`。

### 5.2 布局存储(`~/inkpulse/layouts.json`)
```jsonc
{
  "version": 1,
  "grid": {"cols": 8, "rows": 6},
  "layouts": {
    "dash": {
      "builtin": true,
      "placements": [
        {"widget": "header",        "col": 0, "row": 0, "colspan": 8, "rowspan": 1, "params": {}},
        {"widget": "claude_status", "col": 0, "row": 1, "colspan": 4, "rowspan": 3, "params": {}},
        {"widget": "usage",         "col": 4, "row": 1, "colspan": 4, "rowspan": 3, "params": {}},
        {"widget": "todos",         "col": 0, "row": 4, "colspan": 8, "rowspan": 2, "params": {}}
      ]
    },
    "我的桌面": { "placements": [ /* 用户自建,无 builtin 标记 */ ] }
  }
}
```
- `runtime.json` 的 `layout_name` 指向 `layouts` 的某个 key(沿用现有机制;`config.py` 的 `RUNTIME_FIELDS` 不变)。
- `grid` 全局一份(本期不做"每布局不同网格")。
- 文件不存在时由迁移逻辑生成(含 6 个 builtin)。

### 5.3 网格→像素换算(`render/grid.py`)
- `cell_w = WIDTH / cols`,`cell_h = HEIGHT / rows`(WIDTH=800, HEIGHT=480)。
- `cell_to_zone(grid, p)` → `Zone(round(p.col*cell_w), round(p.row*cell_h), round(p.colspan*cell_w), round(p.rowspan*cell_h))`。
- 边界用 round 累计,保证铺满不留缝;**gutter=0**(墨水屏避免多余分隔线,由 widget 自身决定是否画边框)。

## 6. 网页编辑器(`config.html` 新增区)

交互(点格子版):
1. 选/新建布局 → 画布(8×6)渲染其 placements。
2. 点一个格子=矩形起点,再点另一格=终点 → 黄色高亮选中区。
3. 右侧:widget 下拉(来自 `/api/layouts` 的 widget 目录)+ 按 `params` schema 自动生成的参数输入框 → "放入选中区域"。
4. 删除:点已有 widget → 删;移动/改尺寸:重新框选覆盖。
5. "保存布局" → `PUT /api/layouts/{name}`;切到该布局后点现有「刷新屏幕」即下发设备。
6. 下方复用现有 `/preview.png` 实时预览。

builtin 布局:可选中、可"另存为"副本编辑,不可直接删除/覆盖(UI 禁用删除按钮)。

## 7. API(`server.py`)

| 方法 | 路径 | 说明 |
|---|---|---|
| GET | `/api/layouts` | `{grid, layouts, widgets}`:全部布局 + 网格 + widget 目录(label/default_span/params schema) |
| PUT | `/api/layouts/{name}` | 新建/更新布局的 placements;body 校验 widget 存在、坐标在网格内 |
| DELETE | `/api/layouts/{name}` | 删除;`builtin` 返回 400 |

现有 `POST /api/config {layout_name}`、`POST /api/refresh`、`/preview.png` 不变。

## 8. 错误处理(沿用现有 per-widget 隔离原则)

- **未知 widget / 参数缺失**:该格画 `n/a` 占位框,不崩整帧。
- **布局文件损坏 / 空 / layout_name 不存在**:回退 `dash`,日志告警。
- **placements 越界**(超出 grid):加载时 clamp 到网格内 + 日志。
- **重叠区域**:编辑器阻止重叠落子;引擎按 placements 顺序渲染,后者覆盖前者(不报错)。
- **PUT 校验失败**:返回 400 + 原因,不写文件。

## 9. 后续分期(非本期,记录方向)

- **第二期(Claude 增强 + 本地批)**:用量趋势(近7天柱状)、项目分布(今日各项目占比)、习惯打卡、温湿度曲线(sparkline,注:本机湿度通道损坏,仅温度有效)。数据本地已有/好采,无外部 API 风险。
- **第三期(联网批)**:天气预报、今日日程(Google Calendar/ICS)、行情/自定义数值。共用"外部采集器 + 缓存 + 失败回退 n/a"一套模式。
- 每个 widget 落地 = 写 `draw_xxx` + 注册一行(+ 需要时加采集器),不动布局引擎——这正是本期地基的价值。

## 10. 测试计划(pytest,沿用现有风格)

- `grid.cell_to_zone`:各种 col/row/span 的像素换算,边界铺满不留缝。
- `layouts.json` 读写往返;迁移逻辑产出 6 个 builtin 且能渲染。
- 注册表查找;未知 widget 返回 None。
- 数据驱动 `render_frame`:用一个自定义布局渲染出非空帧。
- 单 widget draw 抛错 → 画 n/a、其余 widget 正常(隔离容错)。
- `draw_countdown`(日期差计算 + 文案)、`draw_qrcode`(纯黑白、可解码)输出正确。
- API 契约:GET 返回结构、PUT 校验(越界/未知 widget 拒绝)、DELETE 拒删 builtin。

## 11. 新增依赖

- `qrcode`(纯 Python,生成二维码 PIL 图像)。其余复用现有 Pillow/FastAPI 栈。

## 12. 验收标准

1. 网页里能新建一个布局、框选区域放入 widget(含 countdown/qrcode 并填参数)、保存、切换、在设备/预览上看到效果。
2. 原 6 个预设作为 builtin 仍可用、外观与现状基本一致、且可"另存为"后编辑。
3. 任一 widget 出错只影响该格,整帧仍出图。
4. 全部测试通过。

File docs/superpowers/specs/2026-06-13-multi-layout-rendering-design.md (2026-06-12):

# 阶段①：hub 多布局渲染

日期：2026-06-13
状态：待评审
所属：可视化配置多布局系统（整体 3 阶段之一）

## 背景与目标

hub 当前只渲染 2 种布局（dash 仪表盘 / photo 相框），`engine.render_frame` 按 `cfg.layout`(widget 列表) 顺序画 widget。

本阶段把 mockup-explorer 里的另外 4 种布局做进 hub，并把 engine 重构成**布局注册表**结构，让加布局变成"加一个函数"。布局本阶段先由 config 指定（web 选布局留阶段②）。目标尺寸只做当前设备的 **800×480**。

最终支持 6 种布局：

| 布局 | 组成 |
|---|---|
| dash（已有） | header + claude 状态 + usage + todos 环绕 |
| photo（已有） | 整屏三色照片 + 角标 |
| usage（新） | 巨号 token + 5h 进度环为主，状态/待办压小 |
| todo（新） | 大号待办清单为主 + 万年历/状态侧栏 |
| clock（新） | 巨型时钟 + 农历/节气 + 月历，信息为页脚 |
| split（新） | 左(状态+用量) / 右(万年历+待办) 四模块等权 |

## 设计

### 1. 布局注册表（engine 重构）

- 定义 `LAYOUTS: dict[str, Callable]`，每个布局一个渲染函数：
  `draw_dash / draw_photo / draw_usage / draw_todo / draw_clock / draw_split`，
  签名统一 `def draw_xxx(d, img, state, cfg) -> None`（photo 需要 img 贴图，故传 img）。
- `render_frame` 改为：取当前布局名 → `LAYOUTS[name](d, img, state, cfg)`；未知名回退 `dash`。
- 现有 dash/photo 渲染逻辑封装进 `draw_dash` / `draw_photo`（行为不变）。

### 2. config 指定布局

- `config.py` 新增 `layout_name: str = "dash"`（从 `config.yaml` 的 `layout.name` 读）。
- 保留旧 `layout.widgets` 兼容（dash 内部仍可用其顺序），但布局选择以 `layout_name` 为准。

### 3. 新 widget（widgets 扩展）

- `draw_big_clock(d, z, now)`：巨型 `HH:MM`（字号按 zone 自适应，黑色，冒号可红）。
- `draw_month_calendar(d, z, now)`：当月 7×6 网格 + 今日高亮(红) + 表头周几；农历用 cnlunar 算当月（格内小字可选）。
- `draw_usage_ring(d, z, usage)`：5h 窗口占用百分比画圆环进度（Pillow `arc`，满则红）。
- usage/todo/split 大量复用现有 `draw_header / draw_usage / draw_todos / draw_claude_status`，只是 zone 重排。

### 4. 各新布局组成（800×480，具体坐标实现时参照 mockup-explorer）

- **usage**：上半巨号 token + 进度环；下半状态/待办压缩成小条。
- **todo**：左 2/3 大号待办清单；右 1/3 侧栏(万年历 + 状态)。
- **clock**：上部巨型时钟 + 农历/节气；下部月历；最底信息页脚。
- **split**：竖分两栏，左(header+状态+用量)，右(万年历+待办)。

## 数据流

- 复用 `state.build_render_state`（已有 clock/lunar/usage/todos/claude/env）。
- 月历需要"当月各日 + 今日"：由 widget 内用 `now` + `cnlunar`/`calendar` 现算，不进 state。

## 错误处理

- 未知 layout_name → 回退 dash + log warning。
- photo 布局无图 → 回退 dash（沿用现有逻辑）。
- 新 widget 数据缺失（如 usage 无数据）→ 画占位，不崩。

## 测试（TDD，hub 侧 pytest）

- 新 widget：`draw_big_clock / draw_month_calendar / draw_usage_ring` 各渲染不崩 + 关键像素断言（如今日格有红像素、进度环高占用有红）。
- 各布局：`render_frame` 在每个 layout_name 下产出 800×480 帧不崩、字节数正确。
- config：`layout_name` 默认/yaml 覆盖。

## 落地顺序

1. engine：抽 `LAYOUTS` 注册表 + 把现有 dash/photo 封装成 `draw_dash/draw_photo`（保持行为，回归测试绿）。
2. config：加 `layout_name`。
3. 新 widget：`draw_big_clock` → `draw_usage_ring` → `draw_month_calendar`（TDD）。
4. 新布局：`draw_usage` → `draw_split` → `draw_todo` → `draw_clock`（组合 widget，TDD 渲染不崩）。
5. 本地 preview 逐布局看效果 + 真机抽验。

## 风险

- 月历 + 农历每格小字在 800×480 下可能偏挤，必要时只标今日农历 + 节气。
- 巨型时钟/进度环字号与圆弧需按 zone 调试，先粗后细。
- 坐标移植自 mockup-explorer(canvas) → Pillow，需逐布局比对预览。

## 非目标（留后续阶段）

- web 选布局 / 实时预览（阶段②）。
- 参数配置 / 照片管理（阶段③）。
- 400×300、240×416 小屏尺寸（当前单一 800×480 设备）。

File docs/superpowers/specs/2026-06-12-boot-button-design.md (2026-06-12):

# BOOT 按键(GPIO0)：短按刷新 + 长按配网

日期：2026-06-12
状态：待评审

## 背景与目标

板载 BOOT 键（GPIO0，低电平有效，内部上拉）接入固件，赋予两个手势：
- **短按** → 手动刷新（立即拉新帧刷屏，不等下次定时 600s）。
- **长按** → 重新配网（清 NVS WiFi 凭据 + 重启进 BLE/SoftAP 配网，换 WiFi 不用接串口擦 NVS）。

双击切换显示本期不做（预留）。

## 设计

### ① 手势识别（新 component `ip_button`）
- GPIO0 配置输入 + 内部上拉，低=按下。
- 一个 FreeRTOS task 轮询（20ms 周期）+ 消抖，识别：
  - **短按**：按下→释放，总时长 `< 1000ms`。
  - **长按**：持续按住 `≥ 3000ms`，触发即回调（不等释放）。
- 接口：`button_init(on_short_cb, on_long_cb)`，识别到手势调对应回调。

### ② 动作（main 接回调）
- **短按 → 刷新**：`xTaskNotify` 主循环，打断其等待，立即 `ch_fetch` + 刷屏。
- **长按 → 配网**：`creds_clear()` 清 NVS 的 ssid/pass + `esp_restart()` → 开机无凭据走配网流程。

### ③ 主循环改造
- 现有 `vTaskDelay(next*1000)` → `ulTaskNotifyTake(timeout=next*1000)`，短按 notify 时提前唤醒（其余超时行为不变）。

### ④ `ip_provisioning` 加 `creds_clear()`
- `nvs_erase_key("ssid"/"pass")` + commit（只清凭据，hub 地址 key 保留）。

## 开机下载模式注意

GPIO0 是 BOOT 键：**开机瞬间按住会进下载模式**（bootloader 行为，不进 app）。本功能只在 app 运行时检测，不受影响；用户开机别按住即可，运行中长按正常配网。实现里 button task 在 app 启动后才创建，天然规避。

## 测试

- 手势识别核心抽成纯函数 `gesture_step(state, level, now_ms) -> event`，逻辑可推理验证（项目无 C 单测框架，主要靠真机）。
- 真机：短按 → 屏立即刷新（日志 fetch 提前）；长按 ≥3s → 设备重启进配网（广播 PROV_InkPulse）。

## 落地顺序

1. `ip_button` component（GPIO0 + 手势 task + 回调）。
2. `ip_provisioning`：`creds_clear()`。
3. `main`：主循环改 notify 等待 + 注册短按/长按回调。
4. 真机验证：短按刷新；长按进配网。

## 风险

- 长按阈值 3s / 短按 1s 凭手感，真机可微调。
- 短按打断刷新若恰逢上一次刷新未完成（e-ink 21s），需让 fetch/show 串行（主循环单线程本就串行，notify 只是提前唤醒，安全）。

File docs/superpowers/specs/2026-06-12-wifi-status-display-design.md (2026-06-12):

# 仪表盘 WiFi 状态显示设计

日期：2026-06-12
状态：待评审

## 背景与目标

仪表盘由 hub 渲染位图、设备只负责显示。当前从屏上看不出网络状态：离线时屏保留旧帧，用户分不清是 WiFi 断、hub 不可达、还是数据没变。

本功能在 header 右上角设一个**统一的「WiFi 状态指示器」**：在线显示信号强度、离线显示红色告警。

## 设计

右上角同一块区域既是信号指示也是离线告警，两种互斥状态：

### ① 信号图标（在线，hub 渲染）
- **数据流**：设备 `ch_fetch` 用 `esp_wifi_sta_get_rssi()` 取 RSSI，像现有 `t/h` 一样加 URL 参数 `&rssi=<dBm>` 传给 hub。
- hub `/frame` 接收 `rssi`，传入渲染状态；`widgets` 在 header 右上角（温度左侧）按 RSSI 画 WiFi 信号格：
  - `>= -60` → 3 格(强)；`-60~-72` → 2 格；`-72~-82` → 1 格；`< -82` 或无 → 0 格(空心)。
- 颜色：黑色。

### ② 离线告警（离线，设备叠加）
- **触发**：主循环 `ch_fetch` 返回非 `ESP_OK`（http perform 失败 = WiFi 断 / hub 不可达），且**状态翻转**（在线→离线）。
- **形式**：设备在 `s_framebuf` 的**红 plane** 右上角（对齐信号图标区）画一个红色 WiFi 叉图标，`disp->show` + `refresh` 一次。利用 BWR 的红色 plane 做醒目告警。
- **恢复**：再次 fetch 成功时正常 hub 帧覆盖，红叉自然消除。
- **刷新策略**：仅在状态翻转（在线↔离线）时刷一次，避免 e-ink 频繁全刷（一次 21s）。

## 数据流 / 架构

- **RSSI**：固件 → URL 参数 → hub 渲染（在线信号格）。
- **离线叉**：固件本地检测 + 叠加（hub 不参与——离线时本就拉不到帧）。
- **位置对齐**：hub 信号格区 = 固件红叉区（右上角同坐标），保证两种状态视觉连贯。

## 坐标约定

- 指示器区域：header 右上角，约 32×24px；温度数字移到其左侧，避免重叠。
- 固件红叉：把该区域的 EPD 坐标换算成红 plane 字节偏移，写入内置叉位图。

## 错误处理

- `esp_wifi_sta_get_rssi()` 失败：`rssi` 传 0 / 省略，hub 画 0 格，不崩。
- 开机即离线（尚无有效帧）：跳过叠加（屏已 clear），仅靠后续翻转触发。

## 测试

- **hub**（TDD）：`widgets` 信号格按 rssi 画对应格数（渲染不崩、像素断言）；`/frame` 正确接收 `rssi` 参数。
- **固件**：离线叠加靠真机验证（断 hub 看红叉出现、恢复 hub 看红叉消失）。

## 落地顺序

1. hub：`/frame` 收 `rssi` + `widgets` 画信号格（TDD）。
2. 固件：`ch_fetch` 取 RSSI 传 URL 参数。
3. 固件：在线/离线状态翻转检测 + 红叉叠加 + 刷新策略。
4. 真机验证：信号格随 RSSI 变化；断 hub 看红叉；恢复看消失。

## 风险

- header 右上角空间紧张（温度 + 信号格），需调坐标避免重叠。
- e-ink 慢刷：离线红叉刷新占 21s，仅翻转时刷一次可接受。
- 离线叉只在「翻转」时刷；若设备此间被复位，需保证开机首次成功/失败也能正确置位。

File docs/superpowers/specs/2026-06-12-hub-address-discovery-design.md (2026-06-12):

# Hub 地址通用化（自动发现 + 可配置）设计

日期：2026-06-12
状态：待评审

## 背景与问题

固件里 hub 服务器地址是编译期写死的宏：

```c
// components/ip_config/include/ip_config/net_config.h
#define HUB_FRAME_URL "http://172.27.73.66:8080/frame"
```

仅 `components/ip_channel/src/http_hub.c:66` 一处使用。换网络、换跑 hub 的机器、或 DHCP 导致 IP 变化，都要改源码重新编译烧录。本次把它通用化：换网/换 IP 不再需要重编重烧。

## 目标 / 非目标

**目标**
- 局域网内设备开机自动找到 hub，无需任何手动配置。
- 跨网/公网/云上场景，能给设备配一个固定 hub 地址并持久保存。
- 都失败时仍有编译默认值兜底，行为不比现在差。

**非目标**
- 不改 hub 的帧渲染/接口协议（路径仍是 `/frame?t=..&h=..`）。
- 不给 BLE 配网加自定义字段（YAGNI；BLE 用户靠 mDNS 自动发现，跨网时用 SoftAP 补配）。
- 不引入云端注册/反向通道等重型发现机制。

## 解析链（每次开机，按优先级）

设备启动联网后，按顺序解析出一个 **hub base URL**（形如 `http://<host>:<port>`，不含路径与 query）：

1. **mDNS 自动发现** — 查询服务 `_inkpulse._tcp.local`。命中则取第一条结果的 IP + 端口，拼成 base URL。超时约 1.5s。
2. **NVS 手动地址** — mDNS 未命中时，读 NVS namespace `inkpulse` 的 key `hub`（用户通过 SoftAP 表单配置）。非空则用。
3. **编译默认值** — 仍为空则用 `net_config.h` 的 `HUB_DEFAULT_BASE` 兜底（永远有值）。

解析出的 base URL 交给 `http_hub`，由它统一拼 `"%s/frame?t=%.1f&h=%.1f"`。任一级成功即停止；HTTP 拉取失败时保留上一帧（沿用现有行为）。

## 固件改动
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

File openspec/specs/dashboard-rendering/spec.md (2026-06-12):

# dashboard-rendering Specification

## Purpose
TBD - created by archiving change enrich-dashboard-layout. Update Purpose after archive.
## Requirements
### Requirement: 头部显示完整日期时间与农历行
头部 SHALL 显示两行:第一行为完整公历日期时间 `YYYY-MM-DD HH:MM 周X`,第二行为农历信息。header 区高度 SHALL 增加以容纳两行,且下方各 widget 不被遮挡。

#### Scenario: 渲染完整日期时间
- **WHEN** 以本地时间 2026-06-12 11:23(周四)渲染头部
- **THEN** 第一行显示 `2026-06-12 11:23 周四`(年-月-日 时:分 周几)

#### Scenario: 头部新增农历行不挤压下方内容
- **WHEN** 渲染整帧
- **THEN** header 占据顶部约 76px 两行,`claude_status`/`usage`/`todos` 三区完整可见、无重叠
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

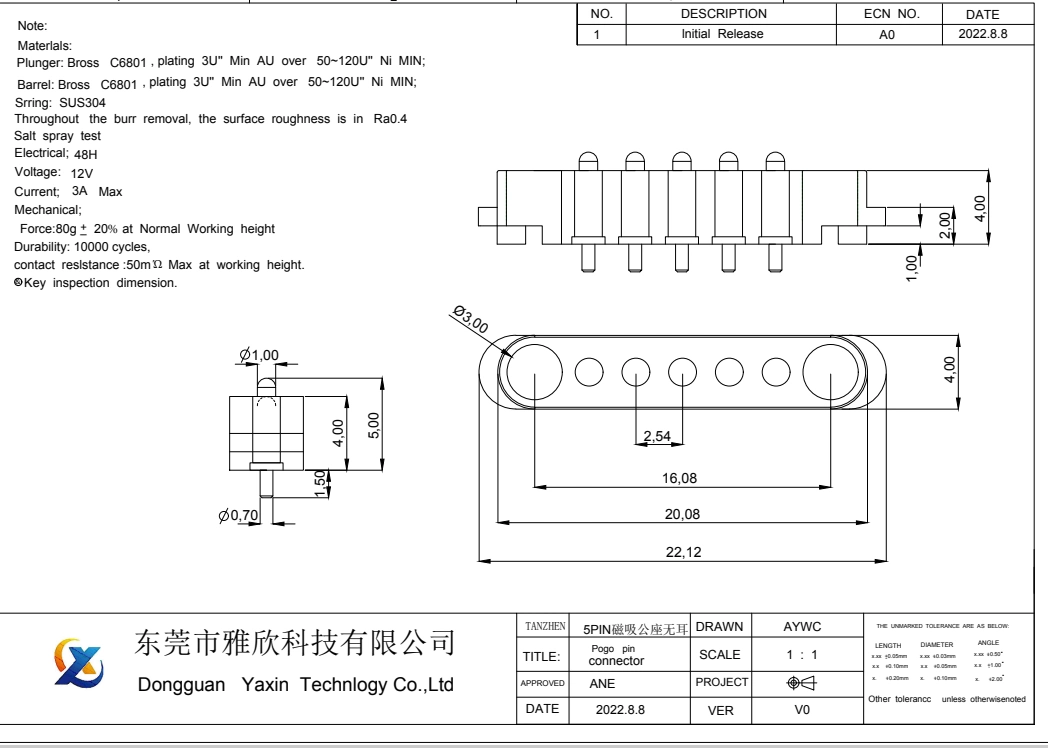
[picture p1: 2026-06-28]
hardware/docs/O1CN01B5k2d72NKPcyqfIw6_!!4611686018427382776-2-amp.webp

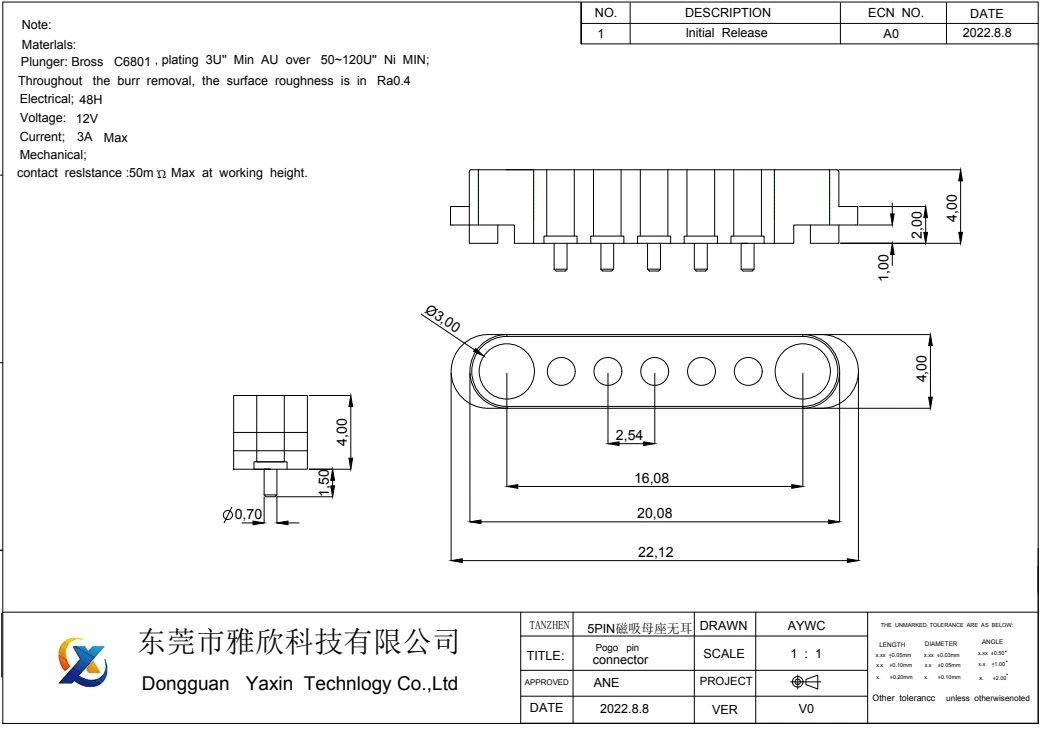
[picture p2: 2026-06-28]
hardware/docs/O1CN01paZEw42NKPcyueNwc_!!4611686018427382776-2-amp.webp

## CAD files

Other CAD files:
cad/output/assembly_shell.step
cad/output/assembly.step
cad/output/bezel.step
cad/output/base.step
cad/output/lid.step
cad/output/back_cover.step
hardware/archived/PCB.step
cad/output/back_cover.stl
cad/output/base.stl
cad/output/bezel.stl
cad/output/lid.stl
hardware/archived/PCB.DWG

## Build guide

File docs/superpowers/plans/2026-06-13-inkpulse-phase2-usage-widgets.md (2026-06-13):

# 第二期只读 widget(用量趋势 + 项目分布)实现计划

> **For agentic workers:** REQUIRED SUB-SKILL: Use superpowers:subagent-driven-development (recommended) or superpowers:executing-plans to implement this plan task-by-task. Steps use checkbox (`- [ ]`) syntax for tracking.

**Goal:** 给 InkPulse Hub 加两个只读 widget——用量趋势(近 N 天柱状)与项目分布(今日各项目占比),数据全部来自现有 Claude Code 日志,零新存储;并新增 `select` 参数类型让"度量(tokens/cost)"在网页编辑器里可选。

**Architecture:** 把 `collectors/usage.py` 的 jsonl 解析抽成共享迭代器 `_iter_usage_records()`,在其上建"按日"与"按项目"两个聚合函数;`build_render_state` 预算出 `usage_daily` / `usage_projects` 塞进 state;两个新 widget 在绘制时按自己的参数(days / top_n / metric)切片渲染。现有 8 widget 与 6 内置布局不受影响。

**Tech Stack:** Python 3.11 / FastAPI / Pillow / pytest。工作目录 `software/hub/`,测试用 `.venv/bin/python -m pytest`,提交统一加 `git commit --no-verify`(仓库 LFS 钩子缺 git-lfs)。

**关键约定:**
- `project = basename(cwd)`,cwd 取自每条日志记录的顶层 `cwd` 字段,缺失记 `"?"`。
- token 口径 = 净 `input + output`(不含缓存);cost 复用现有 `_PRICING` 估算。
- 度量 `metric ∈ {"tokens","cost"}`,默认 `tokens`,未知值回退 `tokens`。
- 所有颜色纯黑(无红色告警);空数据画"无数据"。
- 测试用合成 tmp `.jsonl` + 显式传 `now`,避开时区/真实文件的不确定性。

---

## Task 1: 抽出共享迭代器 `_iter_usage_records`(重构 `collect_usage`,行为不变)

**Files:**
- Modify: `inkpulse_hub/collectors/usage.py`
- Test: `tests/test_usage_iter.py`(新建)

- [ ] **Step 1: 写失败测试**

新建 `tests/test_usage_iter.py`:

```python
import json
import os
from datetime import datetime, timedelta, timezone
from inkpulse_hub.collectors.usage import _iter_usage_records, UsageRecord

NOW = datetime(2026, 6, 13, 12, 0, 0, tzinfo=timezone.utc).astimezone()

def _iso(dt_local):
    return dt_local.astimezone(timezone.utc).strftime("%Y-%m-%dT%H:%M:%S.000Z")

def _write_log(d, name, records):
    os.makedirs(d, exist_ok=True)
    with open(os.path.join(d, name), "w", encoding="utf-8") as f:
        for r in records:
            f.write(json.dumps(r) + "\n")

def _rec(dt_local, cwd, inp, out, model="claude-opus-4-8"):
    return {"timestamp": _iso(dt_local), "cwd": cwd,
            "message": {"model": model,
                        "usage": {"input_tokens": inp, "output_tokens": out}}}

def test_iter_yields_records_with_project_basename(tmp_path):
    _write_log(str(tmp_path), "a.jsonl", [
        _rec(NOW, "/home/u/workspace/InkPulse", 10, 5),
        _rec(NOW, "/home/u/webapp", 3, 2),
    ])
    recs = list(_iter_usage_records(str(tmp_path)))
    assert len(recs) == 2
    assert all(isinstance(r, UsageRecord) for r in recs)
    assert {r.project for r in recs} == {"InkPulse", "webapp"}
    one = next(r for r in recs if r.project == "InkPulse")
    assert one.input == 10 and one.output == 5

def test_iter_skips_bad_lines_and_no_usage(tmp_path):
    p = tmp_path / "b.jsonl"
    p.write_text(
        "{ not json\n"
        + json.dumps({"timestamp": _iso(NOW), "cwd": "/x/y", "message": {}}) + "\n"   # 无 usage
        + json.dumps(_rec(NOW, "/x/y", 1, 1)) + "\n",
        encoding="utf-8")
    recs = list(_iter_usage_records(str(tmp_path)))
    assert len(recs) == 1

def test_iter_missing_cwd_is_question_mark(tmp_path):
    _write_log(str(tmp_path), "c.jsonl", [
        {"timestamp": _iso(NOW), "message": {"usage": {"input_tokens": 1, "output_tokens": 0}}},
    ])
    recs = list(_iter_usage_records(str(tmp_path)))
    assert recs and recs[0].project == "?"

def test_iter_empty_dir(tmp_path):
    assert list(_iter_usage_records(str(tmp_path / "nope"))) == []
```

- [ ] **Step 2: 运行,确认失败**

Run: `.venv/bin/python -m pytest tests/test_usage_iter.py -v`
Expected: FAIL — `ImportError: cannot import name '_iter_usage_records'`(及 `UsageRecord`)

- [ ] **Step 3: 实现迭代器并重构 `collect_usage`**

在 `inkpulse_hub/collectors/usage.py` 顶部 import 段补充:

```python
from dataclasses import dataclass
from typing import Iterator, Optional
```

在 `_record_local_date` 函数之后、`collect_usage` 之前,插入:

```python
@dataclass
class UsageRecord:
    dt: datetime          # 本地时区
    project: str          # basename(cwd), 缺失记 "?"
    input: int
    output: int
    cache_read: int
    cache_create: int
    model: Optional[str]
    source: str           # 来源文件路径(供 session_count 计数, 保持旧行为)

def _project_of(rec: dict) -> str:
    cwd = rec.get("cwd")
    if isinstance(cwd, str) and cwd.strip():
        return os.path.basename(cwd.rstrip("/")) or "?"
    return "?"

def _iter_usage_records(logs_dir: str) -> Iterator[UsageRecord]:
    """遍历 logs_dir/**/*.jsonl, 逐条 yield 带 usage 的记录。
    坏行 / 无时间戳 / 无 usage 一律跳过(沿用旧容错口径)。"""
    if not os.path.isdir(logs_dir):
        return
    files = glob.glob(os.path.join(logs_dir, "**", "*.jsonl"), recursive=True)
    for fp in files:
        try:
            with open(fp, "r", encoding="utf-8") as f:
                for line in f:
                    line = line.strip()
                    if not line:
                        continue
                    try:
                        rec = json.loads(line)
                    except json.JSONDecodeError:
                        continue
                    dt = _record_dt(rec)
                    if dt is None:
                        continue
                    msg = rec.get("message") or {}
                    usage = msg.get("usage")
                    if not isinstance(usage, dict):
                        continue
                    yield UsageRecord(
                        dt=dt,
                        project=_project_of(rec),
                        input=int(usage.get("input_tokens", 0) or 0),
                        output=int(usage.get("output_tokens", 0) or 0),
                        cache_read=int(usage.get("cache_read_input_tokens", 0) or 0),
                        cache_create=int(usage.get("cache_creation_input_tokens", 0) or 0),
                        model=msg.get("model"),
                        source=fp,
                    )
        except OSError:
            continue

def _cost_of_record(r: UsageRecord) -> float:
    """单条记录花费估算(复用 _cost_of 的定价口径)。"""
    return _cost_of({
        "input_tokens": r.input,
        "output_tokens": r.output,
        "cache_creation_input_tokens": r.cache_create,
        "cache_read_input_tokens": r.cache_read,
    }, r.model)
```

然后把 `collect_usage` 的函数体(从 `u = Usage()` 到 `return u`)整体替换为基于迭代器的版本(保持签名与口径完全不变):

```python
def collect_usage(
    logs_dir: str,
    today: date | None = None,
    now: datetime | None = None,
    window_token_limit: int | None = None,
) -> Usage:
    """解析 Claude Code 会话日志(.jsonl):今日 token/花费 + 近 5h 窗口占比。"""
    u = Usage()
    if now is None:
        now = datetime.now().astimezone()
    if today is None:
        today = now.date()
    window_start = now - timedelta(hours=_WINDOW_HOURS)

    sessions_today = set()
    window_tokens = 0
    for r in _iter_usage_records(logs_dir):
        if r.dt.date() == today:
            u.input_tokens += r.input
            u.output_tokens += r.output
            u.cache_tokens += r.cache_read
            u.cost_usd += _cost_of_record(r)
            sessions_today.add(r.source)
        if r.dt >= window_start:
            window_tokens += r.input + r.output
    u.session_count = len(sessions_today)
    if window_token_limit and window_token_limit > 0:
        u.window_used_ratio = min(1.0, window_tokens / window_token_limit)
    return u
```

- [ ] **Step 4: 运行新测试 + 回归**

Run: `.venv/bin/python -m pytest tests/test_usage_iter.py tests/test_usage.py -v`
Expected: PASS(新 4 个 + `test_usage.py` 现有全部仍绿,证明重构未改 `collect_usage` 行为)

- [ ] **Step 5: 提交**

```bash
git add inkpulse_hub/collectors/usage.py tests/test_usage_iter.py
git commit --no-verify -m "refactor(hub): 抽出 _iter_usage_records 共享迭代器(collect_usage 行为不变)"
```

---

## Task 2: 按日聚合 `collect_daily_usage`

**Files:**
- Modify: `inkpulse_hub/collectors/usage.py`
- Test: `tests/test_usage_daily.py`(新建)

- [ ] **Step 1: 写失败测试**

新建 `tests/test_usage_daily.py`:

```python
import json
import os
from datetime import datetime, timedelta, timezone
from inkpulse_hub.collectors.usage import collect_daily_usage

NOW = datetime(2026, 6, 13, 12, 0, 0, tzinfo=timezone.utc).astimezone()

def _iso(dt_local):
    return dt_local.astimezone(timezone.utc).strftime("%Y-%m-%dT%H:%M:%S.000Z")

def _write_log(d, name, records):
    os.makedirs(d, exist_ok=True)
    with open(os.path.join(d, name), "w", encoding="utf-8") as f:
        for r in records:
            f.write(json.dumps(r) + "\n")

def _rec(dt_local, inp, out):
    return {"timestamp": _iso(dt_local), "cwd": "/p/InkPulse",
            "message": {"model": "claude-opus-4-8",
                        "usage": {"input_tokens": inp, "output_tokens": out}}}

def test_buckets_length_equals_days_and_ordered_old_to_new(tmp_path):
    _write_log(str(tmp_path), "a.jsonl", [_rec(NOW, 10, 5)])
    out = collect_daily_usage(str(tmp_path), days=7, now=NOW)
    assert len(out) == 7
    assert out[0]["date"] < out[-1]["date"]          # 旧 -> 新
    assert out[-1]["date"] == NOW.date()             # 末桶是今天

def test_missing_days_are_zero_filled(tmp_path):
    _write_log(str(tmp_path), "a.jsonl", [
        _rec(NOW, 10, 5),                    # 今天: 15 tok
        _rec(NOW - timedelta(days=3), 4, 1),  # 3 天前: 5 tok
    ])
    out = collect_daily_usage(str(tmp_path), days=7, now=NOW)
    by_date = {x["date"]: x["tokens"] for x in out}
    assert by_date[NOW.date()] == 15
    assert by_date[(NOW - timedelta(days=3)).date()] == 5
    assert by_date[(NOW - timedelta(days=1)).date()] == 0   # 无数据补零

def test_cost_summed(tmp_path):
    _write_log(str(tmp_path), "a.jsonl", [_rec(NOW, 1_000_000, 0)])  # opus 输入 $15/M
    out = collect_daily_usage(str(tmp_path), days=1, now=NOW)
    assert out[-1]["cost"] > 0

def test_empty_dir_all_zero(tmp_path):
    out = collect_daily_usage(str(tmp_path / "nope"), days=5, now=NOW)
    assert len(out) == 5 and all(x["tokens"] == 0 and x["cost"] == 0 for x in out)
```

- [ ] **Step 2: 运行,确认失败**

Run: `.venv/bin/python -m pytest tests/test_usage_daily.py -v`
Expected: FAIL — `ImportError: cannot import name 'collect_daily_usage'`

- [ ] **Step 3: 实现**

在 `inkpulse_hub/collectors/usage.py` 的 `collect_usage` 之后追加:

```python
def collect_daily_usage(logs_dir: str, days: int = 14,
                        now: datetime | None = None) -> list[dict]:
    """近 days 天每日桶, 旧->新, 缺日补零。
    返回 [{"date": date, "tokens": int(净), "cost": float}], 长度恒 = days。"""
    if now is None:
        now = datetime.now().astimezone()
    today = now.date()
    start = today - timedelta(days=days - 1)
    buckets: dict = {}
    for r in _iter_usage_records(logs_dir):
        d = r.dt.date()
        if start <= d <= today:
            b = buckets.setdefault(d, [0, 0.0])
            b[0] += r.input + r.output
            b[1] += _cost_of_record(r)
    out = []
    for i in range(days):
        d = start + timedelta(days=i)
        tk, co = buckets.get(d, (0, 0.0))
        out.append({"date": d, "tokens": tk, "cost": co})
    return out
```

- [ ] **Step 4: 运行,确认通过**

Run: `.venv/bin/python -m pytest tests/test_usage_daily.py -v`
Expected: PASS(4 个)

- [ ] **Step 5: 提交**

```bash
git add inkpulse_hub/collectors/usage.py tests/test_usage_daily.py
git commit --no-verify -m "feat(hub): collect_daily_usage 近N天按日聚合(缺日补零)"
```

---

## Task 3: 按项目聚合 `collect_project_usage`

**Files:**
- Modify: `inkpulse_hub/collectors/usage.py`
- Test: `tests/test_usage_project.py`(新建)

- [ ] **Step 1: 写失败测试**

新建 `tests/test_usage_project.py`:

```python
import json
import os
from datetime import datetime, timedelta, timezone
from inkpulse_hub.collectors.usage import collect_project_usage

NOW = datetime(2026, 6, 13, 12, 0, 0, tzinfo=timezone.utc).astimezone()

def _iso(dt_local):
    return dt_local.astimezone(timezone.utc).strftime("%Y-%m-%dT%H:%M:%S.000Z")

def _write_log(d, name, records):
    os.makedirs(d, exist_ok=True)
    with open(os.path.join(d, name), "w", encoding="utf-8") as f:
        for r in records:
            f.write(json.dumps(r) + "\n")

def _rec(dt_local, cwd, inp, out):
    return {"timestamp": _iso(dt_local), "cwd": cwd,
            "message": {"model": "claude-opus-4-8",
                        "usage": {"input_tokens": inp, "output_tokens": out}}}

def test_groups_by_basename_today_only_desc(tmp_path):
    _write_log(str(tmp_path), "a.jsonl", [
        _rec(NOW, "/p/InkPulse", 100, 0),
        _rec(NOW, "/p/InkPulse", 50, 0),
        _rec(NOW, "/p/webapp", 30, 0),
        _rec(NOW - timedelta(days=1), "/p/old", 999, 0),   # 昨天: 不计入今日
    ])
    out = collect_project_usage(str(tmp_path), now=NOW)
    assert [x["project"] for x in out] == ["InkPulse", "webapp"]   # 降序
    assert out[0]["tokens"] == 150

def test_empty_dir_returns_empty(tmp_path):
    assert collect_project_usage(str(tmp_path / "nope"), now=NOW) == []
```

- [ ] **Step 2: 运行,确认失败**

Run: `.venv/bin/python -m pytest tests/test_usage_project.py -v`
Expected: FAIL — `ImportError: cannot import name 'collect_project_usage'`

- [ ] **Step 3: 实现**

在 `inkpulse_hub/collectors/usage.py` 的 `collect_daily_usage` 之后追加:

```python
def collect_project_usage(logs_dir: str, today: date | None = None,
                          now: datetime | None = None) -> list[dict]:
    """今日各项目桶, 按 tokens 降序。
    返回 [{"project": str, "tokens": int(净), "cost": float}]; 空 -> []。"""
    if now is None:
        now = datetime.now().astimezone()
    if today is None:
        today = now.date()
    buckets: dict = {}
    for r in _iter_usage_records(logs_dir):
        if r.dt.date() == today:
            b = buckets.setdefault(r.project, [0, 0.0])
            b[0] += r.input + r.output
            b[1] += _cost_of_record(r)
    out = [{"project": p, "tokens": v[0], "cost": v[1]} for p, v in buckets.items()]
    out.sort(key=lambda x: x["tokens"], reverse=True)
    return out
```

- [ ] **Step 4: 运行,确认通过**

Run: `.venv/bin/python -m pytest tests/test_usage_project.py -v`
Expected: PASS(2 个)

- [ ] **Step 5: 提交**

```bash
git add inkpulse_hub/collectors/usage.py tests/test_usage_project.py
git commit --no-verify -m "feat(hub): collect_project_usage 今日按项目聚合(降序)"
```

---

## Task 4: 把两组聚合注入 `state`

**Files:**
- Modify: `inkpulse_hub/state.py`
- Test: `tests/test_state_phase2.py`(新建)

- [ ] **Step 1: 写失败测试**

新建 `tests/test_state_phase2.py`:

```python
from inkpulse_hub.config import Config
from inkpulse_hub.state import HubState

def test_render_state_has_daily_and_projects(tmp_path):
    cfg = Config()
    cfg.claude_logs = str(tmp_path / "logs")   # 不存在 -> 聚合返回空/全零, 不崩
    cfg.todos_store = str(tmp_path / "todos.json")
    cfg.photos_dir = str(tmp_path / "photos")
    st = HubState(cfg)
    state = st.build_render_state(now=1718000000.0)
    assert "usage_daily" in state and isinstance(state["usage_daily"], list)
    assert "usage_projects" in state and isinstance(state["usage_projects"], list)
    assert len(state["usage_daily"]) == 14   # 默认 14 天全零桶
```

- [ ] **Step 2: 运行,确认失败**

Run: `.venv/bin/python -m pytest tests/test_state_phase2.py -v`
Expected: FAIL — `KeyError: 'usage_daily'`

- [ ] **Step 3: 实现**

`inkpulse_hub/state.py` 顶部把 usage 的 import 改为同时引入两个新函数。找到:

```python
from .collectors.usage import collect_usage
```
改为:
```python
from .collectors.usage import collect_usage, collect_daily_usage, collect_project_usage
```

在 `build_render_state` 的返回字典里,`"clock": self._clock(now),` 这一行之后(`"now": now,` 之前)插入两行:

```python
            "usage_daily": collect_daily_usage(self.cfg.claude_logs),
            "usage_projects": collect_project_usage(self.cfg.claude_logs),
```

> 说明:这里不传 `now`,聚合各自取系统当前时间——与 `collect_usage(...)` 现状一致;`build_render_state` 的 `now` 参数仅用于时钟/农历的确定性测试。

- [ ] **Step 4: 运行,确认通过**

Run: `.venv/bin/python -m pytest tests/test_state_phase2.py -v`
Expected: PASS

- [ ] **Step 5: 提交**

```bash
git add inkpulse_hub/state.py tests/test_state_phase2.py
git commit --no-verify -m "feat(hub): build_render_state 注入 usage_daily/usage_projects"
```

---

## Task 5: `draw_usage_trend` 竖直柱状 widget

**Files:**
- Modify: `inkpulse_hub/render/widgets.py`
- Test: `tests/test_widget_usage_trend.py`(新建)

- [ ] **Step 1: 写失败测试**

新建 `tests/test_widget_usage_trend.py`:

```python
from datetime import date, timedelta
from PIL import Image, ImageDraw
from inkpulse_hub.render.widgets import draw_usage_trend, Zone

def _img(w=400, h=240):
    img = Image.new("RGB", (w, h), (255, 255, 255))
    d = ImageDraw.Draw(img)
    d.fontmode = "1"
    return img, d

def _has_black(img):
    return any(img.getpixel((x, y)) == (0, 0, 0)
               for x in range(img.width) for y in range(img.height))

def _daily(vals):
    base = date(2026, 6, 1)
    return [{"date": base + timedelta(days=i), "tokens": v, "cost": v / 1000}
            for i, v in enumerate(vals)]

def test_draws_black_bars_with_data():
    img, d = _img()
    draw_usage_trend(d, Zone(0, 0, 400, 240), _daily([10, 20, 30, 5, 40, 15, 25]), days=7)
    assert _has_black(img)

def test_empty_data_shows_no_data_no_crash():
    img, d = _img()
    draw_usage_trend(d, Zone(0, 0, 400, 240), [], days=7)
    assert _has_black(img)   # "无数据" 文字也是黑像素, 关键是不抛异常

def test_all_zero_shows_no_data():
    img, d = _img()
    draw_usage_trend(d, Zone(0, 0, 400, 240), _daily([0, 0, 0]), days=3)
    # 不抛异常即可(全零 -> 无数据)

def test_metric_cost_uses_cost_values():
    # cost 全大、tokens 全零时, metric=cost 仍应画出柱子(证明读了 cost 维度)
    img, d = _img()
    series = [{"date": date(2026, 6, 1), "tokens": 0, "cost": 5.0},
              {"date": date(2026, 6, 2), "tokens": 0, "cost": 9.0}]
    draw_usage_trend(d, Zone(0, 0, 400, 240), series, days=2, metric="cost")
    assert _has_black(img)
```

- [ ] **Step 2: 运行,确认失败**

Run: `.venv/bin/python -m pytest tests/test_widget_usage_trend.py -v`
Expected: FAIL — `ImportError: cannot import name 'draw_usage_trend'`

- [ ] **Step 3: 实现**

在 `inkpulse_hub/render/widgets.py` 末尾追加:

```python
def draw_usage_trend(d: ImageDraw.ImageDraw, z: Zone, daily,
                     days: int = 7, metric: str = "tokens") -> None:
    """近 days 天用量竖直柱状图。daily: [{date, tokens, cost}] 旧->新。"""
    days = max(1, min(int(days), 14))
    key = metric if metric in ("tokens", "cost") else "tokens"
    cy = _title_bar(d, z, f"用量趋势 · 近{days}天")
    body = Zone(z.x, cy, z.w, z.y + z.h - cy)
    series = (daily or [])[-days:]
    vals = [max(0, x.get(key, 0)) for x in series]
    if not series or max(vals, default=0) <= 0:
        _center_text(d, body, "无数据", _font(20), BLACK)
        return
    n = len(series)
    gap, label_h = 4, 16
    chart_h = body.h - label_h
    bw = max(2, (body.w - gap * (n + 1)) // n)
    vmax = max(vals)
    f = _font(12)
    for i, (x, v) in enumerate(zip(series, vals)):
        bx = body.x + gap + i * (bw + gap)
        bh = int((chart_h - 2) * (v / vmax))
        top = body.y + chart_h - bh
        d.rectangle((bx, top, bx + bw - 1, body.y + chart_h - 1), fill=BLACK)
        dt = x["date"]
        lbl = f"{dt.month}/{dt.day}"
        tw = d.textlength(lbl, font=f)
        d.text((bx + (bw - tw) / 2, body.y + chart_h + 2), lbl, fill=BLACK, font=f)
```

- [ ] **Step 4: 运行,确认通过**

Run: `.venv/bin/python -m pytest tests/test_widget_usage_trend.py -v`
Expected: PASS(4 个)

- [ ] **Step 5: 提交**

```bash
git add inkpulse_hub/render/widgets.py tests/test_widget_usage_trend.py
git commit --no-verify -m "feat(hub): draw_usage_trend 近N天柱状 widget"
```

---

## Task 6: `draw_project_dist` 横向占比条 widget

**Files:**
- Modify: `inkpulse_hub/render/widgets.py`
- Test: `tests/test_widget_project_dist.py`(新建)

- [ ] **Step 1: 写失败测试**

新建 `tests/test_widget_project_dist.py`:

```python
from PIL import Image, ImageDraw
from inkpulse_hub.render.widgets import draw_project_dist, Zone

def _img(w=400, h=240):
    img = Image.new("RGB", (w, h), (255, 255, 255))
    d = ImageDraw.Draw(img)
    d.fontmode = "1"
    return img, d

def _has_black(img):
    return any(img.getpixel((x, y)) == (0, 0, 0)
               for x in range(img.width) for y in range(img.height))

def _projects(pairs):
    return [{"project": p, "tokens": t, "cost": t / 1000} for p, t in pairs]

def test_draws_black_with_data():
    img, d = _img()
    draw_project_dist(d, Zone(0, 0, 400, 240), _projects([("InkPulse", 60), ("webapp", 40)]))
    assert _has_black(img)

def test_top_n_caps_and_merges_others():
    # 6 个项目, top_n=2 -> 应渲染 2 行 + "其他"。用一个能抓行数的探针:
    img, d = _img(h=300)
    projs = _projects([(f"proj{i}", 10 * (6 - i)) for i in range(6)])
    rows = []
    orig = ImageDraw.ImageDraw.text
    def spy(self, xy, text, *a, **k):
        rows.append(text)
        return orig(self, xy, text, *a, **k)
    ImageDraw.ImageDraw.text = spy
    try:
        draw_project_dist(d, Zone(0, 0, 400, 300), projs, top_n=2)
    finally:
        ImageDraw.ImageDraw.text = orig
    assert any("其他" in t for t in rows)          # 合并行存在
    assert any("proj0" in t for t in rows)          # 最大项在
    assert not any("proj5" in t for t in rows)      # 被并入"其他"

def test_empty_shows_no_data_no_crash():
    img, d = _img()
    draw_project_dist(d, Zone(0, 0, 400, 240), [])
    # 不抛异常即可
```

- [ ] **Step 2: 运行,确认失败**

Run: `.venv/bin/python -m pytest tests/test_widget_project_dist.py -v`
Expected: FAIL — `ImportError: cannot import name 'draw_project_dist'`

- [ ] **Step 3: 实现**

在 `inkpulse_hub/render/widgets.py` 末尾追加:

```python
def draw_project_dist(d: ImageDraw.ImageDraw, z: Zone, projects,
                      top_n: int = 5, metric: str = "tokens") -> None:
    """今日各项目占比横向条。projects: [{project, tokens, cost}]。"""
    top_n = max(1, int(top_n))
    key = metric if metric in ("tokens", "cost") else "tokens"
    cy = _title_bar(d, z, "项目分布 · 今日")
    body = Zone(z.x, cy, z.w, z.y + z.h - cy)
    items = sorted(projects or [], key=lambda x: x.get(key, 0), reverse=True)
    total = sum(max(0, x.get(key, 0)) for x in items)
    if not items or total <= 0:
        _center_text(d, body, "无数据", _font(20), BLACK)
        return
    rows = [(x["project"], max(0, x.get(key, 0))) for x in items[:top_n]]
    rest = items[top_n:]
    if rest:
        rows.append(("其他", sum(max(0, x.get(key, 0)) for x in rest)))
    f = _font(16)
    row_h = max(18, min(28, body.h // len(rows)))
    name_w, pct_w = 84, 48
    bar_x = body.x + name_w
    bar_max = max(4, body.w - name_w - pct_w)
    for i, (name, v) in enumerate(rows):
        ry = body.y + i * row_h
        nm = name if len(name) <= 6 else name[:5] + "…"
        d.text((body.x + 4, ry), nm, fill=BLACK, font=f)
        frac = v / total
        bw = int(bar_max * frac)
        d.rectangle((bar_x, ry + 3, bar_x + bw, ry + row_h - 6), fill=BLACK)
        d.text((bar_x + bw + 4, ry), f"{int(round(frac * 100))}%", fill=BLACK, font=f)
```

- [ ] **Step 4: 运行,确认通过**

Run: `.venv/bin/python -m pytest tests/test_widget_project_dist.py -v`
Expected: PASS(3 个)

- [ ] **Step 5: 提交**

```bash
git add inkpulse_hub/render/widgets.py tests/test_widget_project_dist.py
git commit --no-verify -m "feat(hub): draw_project_dist 今日项目占比横向条 widget"
```

---

## Task 7: 注册两个 widget + `select` 参数元数据

**Files:**
- Modify: `inkpulse_hub/render/registry.py`
- Modify: `tests/test_registry.py`(给注入 state 补两个键 + 新增 select 元数据断言)

- [ ] **Step 1: 改 `tests/test_registry.py`(先让其失败)**

把 `test_registry.py` 里 `_state()` 返回字典中追加两键(在 `"now": ...` 行旁):

```python
        "usage_daily": [{"date": __import__("datetime").date(2026, 6, 13), "tokens": 100, "cost": 0.1}],
        "usage_projects": [{"project": "InkPulse", "tokens": 100, "cost": 0.1}],
```

把 `test_existing_widgets_registered` 里的 `expected` 集合加入两个新名:

```python
    expected = {"header", "claude_status", "usage", "usage_ring",
                "todos", "big_clock", "calendar", "photo",
                "usage_trend", "project_dist"}
```

在文件末尾新增一个断言 select 元数据的测试:

```python
def test_phase2_widgets_have_select_metric_param():
    for name in ("usage_trend", "project_dist"):
        params = REGISTRY[name].params
        metric = next(p for p in params if p["key"] == "metric")
        assert metric["type"] == "select"
        assert {"tokens", "cost"} <= {o["value"] for o in metric["options"]}
```

- [ ] **Step 2: 运行,确认失败**

Run: `.venv/bin/python -m pytest tests/test_registry.py -v`
Expected: FAIL — `usage_trend` 未注册(`expected <= set(REGISTRY)` 失败 / KeyError)

- [ ] **Step 3: 实现**

在 `inkpulse_hub/render/registry.py` 的 `_qrcode` 适配器之后(`REGISTRY = {` 之前)追加两个适配器:

```python
def _usage_trend(d, img, z, state, cfg, p):
    W.draw_usage_trend(d, z, state.get("usage_daily", []),
                       days=int(p.get("days", 7) or 7),
                       metric=p.get("metric", "tokens"))

def _project_dist(d, img, z, state, cfg, p):
    W.draw_project_dist(d, z, state.get("usage_projects", []),
                        top_n=int(p.get("top_n", 5) or 5),
                        metric=p.get("metric", "tokens"))
```

在 `REGISTRY` 字典里、`"qrcode": ...` 那一项之后(闭合 `}` 之前)加两项:

```python
    "usage_trend":   WidgetSpec("usage_trend", "用量趋势", _usage_trend, {"cols": 4, "rows": 3},
        [{"key": "days", "label": "天数", "type": "number", "default": 7},
         {"key": "metric", "label": "度量", "type": "select", "default": "tokens",
          "options": [{"value": "tokens", "label": "Token数"},
                      {"value": "cost", "label": "花费$"}]}]),
    "project_dist":  WidgetSpec("project_dist", "项目分布", _project_dist, {"cols": 4, "rows": 3},
        [{"key": "top_n", "label": "显示前N项", "type": "number", "default": 5},
         {"key": "metric", "label": "度量", "type": "select", "default": "tokens",
          "options": [{"value": "tokens", "label": "Token数"},
                      {"value": "cost", "label": "花费$"}]}]),
```

- [ ] **Step 4: 运行,确认通过**

Run: `.venv/bin/python -m pytest tests/test_registry.py -v`
Expected: PASS(含新 select 元数据测试,且 `test_each_widget_draws_without_error` 对两个新 widget 也用注入数据画出不抛错)

- [ ] **Step 5: 提交**

```bash
git add inkpulse_hub/render/registry.py tests/test_registry.py
git commit --no-verify -m "feat(hub): 注册 usage_trend/project_dist + select 度量参数"
```

---

## Task 8: 网页编辑器支持 `select` 参数 + API 契约测试 + 全量回归

**Files:**
- Modify: `inkpulse_hub/web/config.html`(参数表单渲染 + 取值)
- Modify: `tests/test_layouts_api.py`(新增契约测试)

- [ ] **Step 1: 写失败的 API 契约测试**

在 `tests/test_layouts_api.py` 末尾追加:

```python
def test_catalog_exposes_phase2_widgets_with_select(tmp_path):
    cfg, c = _client(tmp_path)
    widgets = {w["name"]: w for w in c.get("/api/layouts").json()["widgets"]}
    assert {"usage_trend", "project_dist"} <= set(widgets)
    metric = next(p for p in widgets["usage_trend"]["params"] if p["key"] == "metric")
    assert metric["type"] == "select"
    assert {"tokens", "cost"} <= {o["value"] for o in metric["options"]}
```

- [ ] **Step 2: 运行,确认通过(后端已在 Task 7 就绪)**

Run: `.venv/bin/python -m pytest tests/test_layouts_api.py::test_catalog_exposes_phase2_widgets_with_select -v`
Expected: PASS(GET /api/layouts 已返回完整 REGISTRY,含 select 参数)

> 说明:此测试在 Task 7 完成后即应通过,作为 API 契约固化;无需改后端。

- [ ] **Step 3: 编辑器渲染 `select`(改 config.html)**

`inkpulse_hub/web/config.html` 中,`edParams` 渲染逻辑(约第 211-213 行)当前为:

```javascript
  if (!w || !w.params.length) { box.innerHTML = ''; return; }
  box.innerHTML = w.params.map(p =>
    `<div class="row"><label>${esc(p.label)}</label><input data-k="${p.key}" type="${p.type === 'date' ? 'date' : (p.type === 'number' ? 'number' : 'text')}" value="${p.default || ''}"></div>`).join('');
```

替换为(新增 select 分支):

```javascript
  if (!w || !w.params.length) { box.innerHTML = ''; return; }
  box.innerHTML = w.params.map(p => {
    if (p.type === 'select') {
      const opts = (p.options || []).map(o =>
        `<option value="${o.value}" ${o.value === p.default ? 'selected' : ''}>${esc(o.label)}</option>`).join('');
      return `<div class="row"><label>${esc(p.label)}</label><select data-k="${p.key}" style="flex:1;padding:6px 8px;border:1px solid #d4d4d8;border-radius:6px">${opts}</select></div>`;
    }
    const t = p.type === 'date' ? 'date' : (p.type === 'number' ? 'number' : 'text');
    return `<div class="row"><label>${esc(p.label)}</label><input data-k="${p.key}" type="${t}" value="${p.default || ''}"></div>`;
  }).join('');
```

- [ ] **Step 4: 取值时把 `select` 也收进 params(改 config.html)**

同文件中收集参数那一行(约第 256 行)当前为:

```javascript
  document.querySelectorAll('#edParams input').forEach(i => params[i.dataset.k] = i.value);
```

替换为:

```javascript
  document.querySelectorAll('#edParams input, #edParams select').forEach(i => params[i.dataset.k] = i.value);
```

- [ ] **Step 5: 全量回归**

Run: `.venv/bin/python -m pytest -q`
Expected: 全绿(基线 95 + 本期新增约 20 个测试,合计 ~115 passed)。

- [ ] **Step 6: 真机/浏览器手动验收**

```bash
systemctl --user restart inkpulse-hub 2>/dev/null || (pkill -f inkpulse_hub; cd software/hub && nohup ./run.sh >/tmp/inkpulse-hub.log 2>&1 & disown)
```
打开 `http://192.168.2.139:8080/config`:新建一个布局 → 框选区域 → widget 下拉选「用量趋势」/「项目分布」→ 「度量」应是**下拉框**(Token数/花费$)→ 填天数/TopN → 放入 → 保存 → 切到该布局 → 看 `/preview.png` 出现柱状图/占比条。

- [ ] **Step 7: 提交**

```bash
git add inkpulse_hub/web/config.html tests/test_layouts_api.py
git commit --no-verify -m "feat(hub): 编辑器支持 select 参数 + 用量趋势/项目分布 API 契约测试"
```

---

## 自检(写完计划对照 spec)

- **Spec §2 范围**:迭代器重构(T1)、daily(T2)、project(T3)、state 注入(T4)、两 widget(T5/T6)、注册+select(T7)、编辑器 select(T8)——逐条有任务。✓
- **Spec §5 数据模型**:`UsageRecord` 字段、`collect_daily_usage(days=14)`、`collect_project_usage` 签名与计划一致。✓
- **Spec §6 参数**:`usage_trend{days,metric}`、`project_dist{top_n,metric}`、`metric` 为 select 带 options——T7 元数据与 T5/T6 适配器默认值一致(days=7/top_n=5/metric=tokens)。✓
- **Spec §6.4 select 类型**:T7(元数据)+ T8(编辑器渲染+取值);PUT API 不校验 params 值,无后端改动。✓
- **Spec §7 容错**:空目录→空/全零(T2/T3 测试)、空数据→"无数据"(T5/T6 测试)、未知 metric 回退 tokens(widget 内 `key=...` 逻辑)。✓
- **Spec §8 测试计划**:迭代器/daily/project/collect_usage 回归/两 widget/registry/API 契约——全覆盖。✓
- 类型一致性:`state["usage_daily"]` 元素 `{date,tokens,cost}` 在 T2 产出、T5 消费;`{project,tokens,cost}` 在 T3 产出、T6 消费,字段名一致。✓

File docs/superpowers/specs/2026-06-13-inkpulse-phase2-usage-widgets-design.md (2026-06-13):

# InkPulse 第二期(只读批):用量趋势 + 项目分布(设计文档)

> 日期:2026-06-13 · 状态:已通过设计评审,待写实现计划
> 关联:[网格布局系统设计(第一期)](2026-06-13-inkpulse-grid-layout-system-design.md) · 实现计划见 `docs/superpowers/plans/`

## 1. 背景与目标

第一期把布局变成了数据驱动的网格系统:加新功能 = 写一个 `draw_xxx` + 注册一行,不再碰布局引擎。本设计是 **第二期的第一批**——按第一期 spec §9 规划的"本地数据 widget"中**零外部 API 风险、零新存储**的两个:

- **用量趋势**:近 N 天用量柱状图。
- **项目分布**:今日各项目用量占比(横向条)。

二者的数据都来自现有 Claude Code 会话日志(`~/.claude/projects/**/*.jsonl`),只需扩展现有 `collectors/usage.py` 的聚合维度,**不引入任何新数据管线或存储**。

第二期剩余两个 widget(习惯打卡、温湿度曲线)各自需要新存储/交互,**另开 spec**,不在本期范围。

## 2. 范围

### 本期做(In Scope)
- 扩展 `collectors/usage.py`:把现有 jsonl 解析抽成共享迭代器,新增**按日聚合**与**按项目聚合**两个函数。
- `state` 新增 `usage_daily`、`usage_projects` 两键(在 `build_render_state` 预算)。
- 两个新 widget:`usage_trend`(竖直柱状)、`project_dist`(横向条),注册进 REGISTRY。
- 新增参数类型 **`select`**(下拉),让"度量(tokens/cost)"在网页编辑器里可选。
- 配套测试(collector 聚合 + widget 绘制 + 参数行为)。

### 本期不做(Out of Scope / YAGNI)
- 习惯打卡、温湿度曲线(各自另开 spec,需新存储/交互/采集器)。
- 第三期联网 widget(天气/日程/行情)。
- 单遍扫描优化(三个聚合函数各自扫一遍日志,见 §7)。
- sparkline / 图表库(纯 Pillow 画)。
- 度量值的服务端校验(PUT API 不校验 params 值,沿用现状)。

## 3. 决策记录(brainstorm 结论)

| 决策点 | 选择 | 理由 |
|---|---|---|
| 本期范围 | **只做两个只读 widget** | 零外部 API、零新存储,快且低风险;打卡/温度曲线各自要新存储,另开 spec |
| 数据放置 | **预算进 `state`,widget 按参数切片** | 沿用现有"collector→state,adapter 只读 state"模式;registry 测试可注入数据,确定性好;IO 集中 |
| 度量(纵轴) | **做成 widget 参数 `metric`(select)** | 用户在编辑器里选 tokens/cost,无需为两套度量各做一个 widget |
| token 口径 | **净 input+output(不含缓存)** | 与现有 5h 窗口口径一致;缓存量级极大(可上亿)会压扁所有柱子,失去趋势意义 |
| 项目识别 | **`project = basename(cwd)`** | 每条日志记录都带 `cwd` 字段,稳健,无需解码目录名 |
| 颜色 | **纯黑,无红色告警** | 趋势/占比无"告警"语义;红色在本系统专留给"需注意"(超预算/临近等) |
| 默认网格跨度 | **均 4×3 格** | 与 usage/calendar 同档,放得下柱状/条形 + 标题栏 |

## 4. 架构总览

```
build_render_state(now)
  ├─ usage         = collect_usage(...)              # 现有, 不变
  ├─ usage_daily   = collect_daily_usage(logs, 14)   # 新: 近14天每日桶
  └─ usage_projects= collect_project_usage(logs)     # 新: 今日每项目桶

render_frame → placement(widget="usage_trend", params={days,metric})
  └─ adapter 读 state["usage_daily"] → 取末 days 天 → 按 metric 取值 → draw_usage_trend
     placement(widget="project_dist", params={top_n,metric})
  └─ adapter 读 state["usage_projects"] → 按 metric 排序取 top_n + 其他 → draw_project_dist
```

要点:数据层算"全量"(近 14 天 / 所有项目),widget 在绘制时按自己的参数(days/top_n/metric)切片。这样 `state` 与参数解耦,adapter 保持纯函数(只读 state + params),测试可注入数据。

### 模块划分(单一职责)
- `collectors/usage.py`(改):抽出 `_iter_usage_records()` 共享迭代器;`collect_usage` 改用它(行为不变);新增 `collect_daily_usage`、`collect_project_usage`。
- `state.py`(改):`build_render_state` 增 `usage_daily`、`usage_projects` 两键。
- `render/widgets.py`(改):新增 `draw_usage_trend`、`draw_project_dist`。
- `render/registry.py`(改):注册两个 widget + 适配器;`metric` 参数用新类型 `select`。
- `web/config.html`(改):参数表单支持 `type: "select"`(渲染下拉框)。

## 5. 数据模型

### 5.1 共享迭代器(`collectors/usage.py`)
```python
@dataclass
class UsageRecord:
    dt: datetime          # 本地时区
    project: str          # basename(cwd), 缺失记 "?"
    input: int
    output: int
    cache_read: int
    cache_create: int
    model: str | None

def _iter_usage_records(logs_dir) -> Iterator[UsageRecord]:
    # 遍历 **/*.jsonl, 逐条 yield 带 usage 的记录(坏行/无时间戳/无 usage 跳过)
```
现有 `collect_usage` 改为消费此迭代器重建"今日累计 + 5h 窗口"(口径、字段完全不变)。

### 5.2 按日聚合
```python
def collect_daily_usage(logs_dir, days=14, now=None) -> list[dict]:
    # 返回近 days 天(含今天)每日桶, 旧→新, 无数据的天补零:
    # [{"date": date, "tokens": int, "cost": float}, ...]   长度恒 = days
```
- `tokens = input + output`(净),`cost` 按现有 `_PRICING` 估算。
- 缺数据的日期补零桶(保证柱状图 X 轴连续)。

### 5.3 按项目聚合(今日)
```python
def collect_project_usage(logs_dir, today=None, now=None) -> list[dict]:
    # 今日每个项目一桶, 按 tokens 降序:
    # [{"project": str, "tokens": int, "cost": float}, ...]
```
- 仅统计今日记录;空 → 空列表。

### 5.4 注入 state
`build_render_state` 新增:
```python
"usage_daily":    collect_daily_usage(self.cfg.claude_logs),
"usage_projects": collect_project_usage(self.cfg.claude_logs),
```

## 6. Widget 与参数

### 6.1 `usage_trend`(竖直柱状,近 N 天)
```
┌ 用量趋势 · 近7天 ────────────┐
│                  ▆           │
│        ▃    ▅    █    ▆      │
│   ▂    █    █    █    █   ▃  │
│ 6/07 6/08 6/09 6/10 6/11 …  │
└──────────────────────────────┘
```
- 顶部标题栏(复用 `_title_bar`);其下等宽柱;X 轴标 `M/D`。
- 柱高按区间内最大值归一化;全零时画基线 + "无数据"。
- 参数:`days`(number, 默认 7,绘制时 clamp 到 1..14)、`metric`(select: tokens/cost,默认 tokens)。

### 6.2 `project_dist`(横向条,今日 Top-N 占比)
```
┌ 项目分布 · 今日 ─────────────┐
│ InkPulse  ▓▓▓▓▓▓▓▓▓▓  62%   │
│ webapp    ▓▓▓▓▓        28%   │
│ 其他      ▓▓            10%   │
└──────────────────────────────┘
```
- 按 `metric` 降序;取前 `top_n`,其余合并为"其他"行。
- 每行:项目名(截断)+ 横条(长度∝占比)+ 百分比。
- 空数据 → 居中"无数据"。
- 参数:`top_n`(number, 默认 5)、`metric`(select,默认 tokens)。

### 6.3 适配器(`registry.py`)
```python
def _usage_trend(d, img, z, state, cfg, p):
    W.draw_usage_trend(d, z, state.get("usage_daily", []),
                       days=int(p.get("days", 7)), metric=p.get("metric", "tokens"))

def _project_dist(d, img, z, state, cfg, p):
    W.draw_project_dist(d, z, state.get("usage_projects", []),
                        top_n=int(p.get("top_n", 5)), metric=p.get("metric", "tokens"))
```
注册项(`default_span` 均 `{cols:4, rows:3}`):
```python
"usage_trend": WidgetSpec("usage_trend", "用量趋势", _usage_trend, {"cols":4,"rows":3},
    [{"key":"days","label":"天数","type":"number","default":7},
     {"key":"metric","label":"度量","type":"select","default":"tokens",
      "options":[{"value":"tokens","label":"Token数"},{"value":"cost","label":"花费$"}]}]),
"project_dist": WidgetSpec("project_dist", "项目分布", _project_dist, {"cols":4,"rows":3},
    [{"key":"top_n","label":"显示前N项","type":"number","default":5},
     {"key":"metric","label":"度量","type":"select","default":"tokens",
      "options":[{"value":"tokens","label":"Token数"},{"value":"cost","label":"花费$"}]}]),
```

### 6.4 新参数类型 `select`
- 数据约定:params 项 `{"key","label","type":"select","default","options":[{"value","label"}]}`。
- `config.html` 编辑器:`type==="select"` 时渲染 `<select>`(选项取 `options`),否则沿用现有 text/date/number 输入框。
- 后端 `PUT /api/layouts` 不校验 params 值(沿用现状),故无 API 改动。

## 7. 错误处理与性能

- **日志目录不存在 / 空**:聚合返回空(daily 仍返回长度 = days 的全零桶);widget 画"无数据"。
- **坏行 / 无时间戳 / 无 usage**:迭代器跳过(沿用现有容错)。
- **未知 metric**:回退 tokens。
- **widget 内异常**:被 engine 的 per-widget 隔离捕获,画 `n/a`(第一期已有)。
- **性能**:三个聚合各扫一遍日志(每次渲染)。现有 `collect_usage` 本就每次渲染扫一遍;新增两个 widget 仅在出现在当前布局时其数据才被用到,但 `build_render_state` 当前对所有 widget 一律预算。渲染非高频(设备 ~10s 轮询、变化才出图),**本期接受三遍扫描,不做单遍优化**(YAGNI;日志规模过大再议)。

## 8. 测试计划(pytest,沿用现有风格)

合成数据:测试写若干 tmp `.jsonl`(含 `timestamp` / `cwd` / `message.usage` / `message.model`),指向 `cfg.claude_logs = tmp_dir`。
- `_iter_usage_records`:产出条数、字段、坏行跳过。
- `collect_daily_usage`:桶数恒 = days、日期连续、缺日补零、tokens/cost 求和正确、空目录全零。
- `collect_project_usage`:按 cwd basename 分组、今日过滤、降序、空目录空列表。
- `collect_usage` **回归**:重构后今日/窗口口径不变(现有测试必须仍绿)。
- `draw_usage_trend`:有数据画黑像素;全零画"无数据"不崩;`days` clamp;`metric` 切换改变柱高来源。
- `draw_project_dist`:画黑像素;`top_n` 截断 + "其他"合并;空数据"无数据";`metric` 切换。
- `registry`:两 widget 已注册、能在注入 state 下绘制不抛错;`metric` 参数 `type=="select"` 且带 `options`。
- `/api/layouts` GET:widget 目录含 `usage_trend`/`project_dist`,其 params 含 select 项(契约测试)。

## 9. 新增依赖

无。纯复用现有 Pillow / 标准库。

## 10. 验收标准

1. 网页编辑器里能放入"用量趋势""项目分布",并通过下拉选择度量(tokens/cost);保存、切换、在预览/设备上看到图。
2. 用量趋势按 `days` 显示对应天数柱子;项目分布按 `top_n` 显示前 N 项 + 其他,占比正确。
3. 无日志/空数据时两 widget 画"无数据",整帧不崩。
4. `collect_usage` 现有行为不变,全部测试通过。

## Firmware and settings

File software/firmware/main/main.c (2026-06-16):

#include <stdio.h>
#include "freertos/FreeRTOS.h"
#include "freertos/task.h"
#include "esp_log.h"
#include "ip_sensor/sensor.h"
#include "ip_display/display.h"
#include "ip_net/net.h"
#include "ip_provisioning/provisioning.h"
#include "ip_config/net_config.h"
#include "ip_channel/channel.h"
#include "ip_button/button.h"
#include "esp_system.h"   // esp_restart

static const char *TAG = "inkpulse";

#define PARTIAL_BEFORE_FULL 8    // 连续局刷达此次数 → 强制一次全刷洗残影/灰(过渡值, 待厂商波形)

static uint8_t s_framebuf[96000];

// 定义 INKPULSE_VERIFY(idf.py build -DINKPULSE_VERIFY=1 或在此 #define)
// 可跑阶段一 bring-up harness: 温湿度 + 白/黑/红, 不联网。
#ifdef INKPULSE_VERIFY

void app_main(void)
{
    ESP_LOGI(TAG, "==================================================");
    ESP_LOGI(TAG, "  InkPulse 合并验证: 温湿度 + 屏幕");
    ESP_LOGI(TAG, "==================================================");

    ESP_LOGI(TAG, "[1] HTU21D 温湿度:");
    const sensor_if_t *sensor = htu21d_sensor();
    sensor->init();
    for (int i = 0; i < 3; i++) {
        sensor_env_t env = {0};
        sensor->read(&env);
        if (env.temp_valid || env.humidity_valid)
            ESP_LOGI(TAG, "    温度=%.2f C (valid=%d)   湿度=%.2f %% (valid=%d)",
                     env.temp_c, env.temp_valid, env.humidity, env.humidity_valid);
        else
            ESP_LOGW(TAG, "    读取失败");
        vTaskDelay(pdMS_TO_TICKS(1000));
    }

    ESP_LOGI(TAG, "[2] 墨水屏: 初始化 + 白/黑/红/分屏/棋盘");
    const display_if_t *disp =
#if CONFIG_PANEL_SSD1677_BW_426
        ssd1677_driver();
#else
        uc8179_driver();
#endif
    disp->init();
    disp->selftest();
    ESP_LOGI(TAG, "=== 验证结束 ===");
    while (1) vTaskDelay(pdMS_TO_TICKS(1000));
}

#else  // ---- 联网主循环(默认) ----

// 离线叉: BWR 用红 plane 画红叉; BW 用单 plane 画黑叉。on=画, off=清。
static void mark_offline(uint8_t *fb, const display_caps_t *c, bool on)
{
    const int x0 = 766, y0 = 8, sz = 18;
    if (c->color_model == DISP_BW) {
        int rb = 800 / 8;                 // 旋转后单 plane 行字节(800/8=100)
        uint8_t *plane = fb;              // bit=1=黑
        for (int i = 0; i <= sz; i++) {
            for (int w = 0; w < 3; w++) {
                int yy = y0 + i;
                int xa = x0 + i + w, xb = x0 + sz - i + w;
                uint8_t ma = 0x80 >> (xa % 8), mb = 0x80 >> (xb % 8);
                if (on) { plane[yy*rb + xa/8] |= ma;  plane[yy*rb + xb/8] |= mb; }
                else    { plane[yy*rb + xa/8] &= ~ma; plane[yy*rb + xb/8] &= ~mb; }
            }
        }
        return;
    }
    int rb = c->width / 8;                 // BWR: row bytes (800/8=100)
    uint8_t *red = fb + c->frame_bytes / 2;
    for (int i = 0; i <= sz; i++) {
        for (int w = 0; w < 3; w++) {
            int yy = y0 + i;
            int xa = x0 + i + w, xb = x0 + sz - i + w;
            uint8_t ma = 0x80 >> (xa % 8), mb = 0x80 >> (xb % 8);
            if (on) { red[yy*rb + xa/8] |= ma;  red[yy*rb + xb/8] |= mb; }
            else    { red[yy*rb + xa/8] &= ~ma; red[yy*rb + xb/8] &= ~mb; }
        }
    }
}

// 按键回调: 短按唤醒主循环立即刷新; 长按清凭据重启进配网。
static TaskHandle_t s_main_task;
static void on_btn_short(void) { if (s_main_task) xTaskNotifyGive(s_main_task); }
static void on_btn_long(void)  { creds_clear(); esp_restart(); }

void app_main(void)
{
    ESP_LOGI(TAG, "boot");
    s_main_task = xTaskGetCurrentTaskHandle();
    button_init(on_btn_short, on_btn_long);
    const display_if_t  *disp   =
#if CONFIG_PANEL_SSD1677_BW_426
        ssd1677_driver();
#else
        uc8179_driver();
#endif
    const sensor_if_t   *sensor = htu21d_sensor();
    const channel_if_t  *chan   = http_hub_channel();
    disp->init();
    sensor->init();
    ip_net_init();
    ip_net_prepare_sta();   // STA netif 必须在连接前创建(有凭据直连 / 无凭据 mgr 配网都需要),
                            // 否则即使关联上 AP 也没 DHCP client、拿不到 IP。幂等。

    display_caps_t caps;
    disp->get_caps(&caps);

    char ssid[33]={0}, pass[65]={0};
    if (!creds_load(ssid,sizeof ssid,pass,sizeof pass)) {
        if (!ble_provisioning()->run(PROV_BLE_TIMEOUT_S)) {
            // BLE 超时/失败 → SoftAP 起网页, 等用户配网后内部 esp_restart
            softap_provisioning()->run(0);
            disp->clear();
            while (1) vTaskDelay(pdMS_TO_TICKS(1000));   // 等重启
        }
        // BLE 配网成功(凭据已存 NVS), 重读
        creds_load(ssid,sizeof ssid,pass,sizeof pass);
    }
    // 统一用 NVS 凭据连接(BLE 路径: 不 esp_restart, 故不会触发 App "Device disconnected";
    //   BLE 期间 mgr 已 auto-stop, 这里 STA 重连一次即可)
    if (ip_net_sta_connect(ssid,pass) != ESP_OK) {
        disp->clear(); while (1) vTaskDelay(pdMS_TO_TICKS(1000));
    }
    disp->clear();   // 开机消残影
    chan->init(&caps);

    bool online = true;       // 连接状态, 仅在翻转时刷屏(避免 e-ink 频繁全刷)
    int  refresh_token = 0;   // hub 刷新令牌基线; 变化=web 请求真机刷新
    bool first_frame = true;   // 循环内首次出图 → 强制全刷, 建立 0x26 内容基准
    int  partial_count = 0;    // 已连续局刷次数
    while (1) {
        sensor_env_t env; sensor->read(&env);
        channel_result_t r = { .changed = false, .next_refresh_s = 600 };
        esp_err_t fr = chan->fetch(s_framebuf, sizeof s_framebuf, &env, &r);
        bool now_online = (fr == ESP_OK);

        bool changed_any = false, recovered = false;
        if (now_online && r.changed) {
            disp->show(s_framebuf, caps.frame_bytes);   // 新帧已覆盖整 buffer(含叉区)
            changed_any = true;
        } else if (!now_online && online) {
            mark_offline(s_framebuf, &caps, true);       // 在线->离线: 叠叉
            disp->show(s_framebuf, caps.frame_bytes);
            changed_any = true;
        } else if (now_online && !online) {
            mark_offline(s_framebuf, &caps, false);      // 离线->在线: 清叉
            disp->show(s_framebuf, caps.frame_bytes);
            changed_any = true;
            recovered = true;                            // 离线恢复 → 强制全刷
        }
        if (changed_any) {
            bool force_full = first_frame || recovered ||
                              (partial_count >= PARTIAL_BEFORE_FULL);
            if (disp->refresh_partial && !force_full) {
                disp->refresh_partial();
                partial_count++;
            } else {
                disp->refresh();                          // UC8179 无 refresh_partial 时恒走这里
                partial_count = 0;
            }
            first_frame = false;
        }
        online = now_online;

        ESP_LOGI(TAG, "fetch -> %s, next=%ds",
                 (now_online && r.changed) ? "新帧已刷" :
                 now_online                ? "未变/未刷" : "出错/离线",
                 r.next_refresh_s);
        int next = r.next_refresh_s < 30 ? 30 : r.next_refresh_s;
        // 分段等待: 每 10s 查 hub 刷新令牌, 令牌变化(web 请求刷新)或 BOOT 短按则提前刷新
        int waited = 0;
        while (waited < next) {
            int step = (next - waited) > 10 ? 10 : (next - waited);
            if (ulTaskNotifyTake(pdTRUE, pdMS_TO_TICKS((uint32_t)step * 1000))) break;  // BOOT 短按
            waited += step;
            int tok = http_hub_poll_token();
            if (tok >= 0 && tok != refresh_token) { refresh_token = tok; break; }
        }
    }
}

#endif

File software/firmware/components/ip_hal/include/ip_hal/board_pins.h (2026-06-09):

#pragma once
// E075A42 (UC8179) <-> ESP32-S3 引脚映射，来自原理图 net label 坐标逐行对齐确认
#define EPD_PIN_SCLK   41   // SCL
#define EPD_PIN_MOSI   42   // SDA
#define EPD_PIN_CS     40   // CSB
#define EPD_PIN_DC     39   // DC
#define EPD_PIN_RST    38   // RES
#define EPD_PIN_BUSY   37   // BUSY_N (低=忙)

#define EPD_WIDTH       800
#define EPD_HEIGHT      480
#define EPD_ROW_BYTES   (EPD_WIDTH / 8)            // 100
#define EPD_PLANE_BYTES (EPD_ROW_BYTES * EPD_HEIGHT) // 48000

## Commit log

2026-06-01 feat:实现原理图和PCB布局
    [PCB1.PcbDoc, PCB_Project.PrjPcb, Sheet1.SchDoc]
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2026-06-01 [hw] 完成初版布局
    [PCB1.PcbDoc, PCB_Project.PrjPcb, Sheet1.SchDoc]
2026-06-04 [hw] 更新原理图、PCB和3d模型
    [PCB1.PcbDoc, PCB1.step, Sheet1.SchDoc]
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2026-06-04 [feat] 生成墨水屏外壳v1参数化模型(build123d)
    - cad/enclosure.py: 前框/后盖/底座三件 + 装配体参数化脚本
    - cad/output/: 三件 STEP(LFS)+STL 及装配体, 含预览PNG
    - 斜墙安装面经校验为精确60°仰角; 三件均水密可打印
    - cad/render_preview.py: STL/STEP -> PNG 预览校验工具
    [assembly.step, back_cover.step, back_cover.stl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]
2026-06-04 [feat] 外壳v2: 加宽底座/减薄屏框后盖/修正斜墙朝向与装配
    - 底座加宽大扁平脚板 130x90, 斜墙外移到±63 横撑176mm宽屏(稳定性)
    - 背腔减薄 17->5mm: 前框总深 19.2->7.2, 后盖 17.25->5.25
    - 修正斜墙三角朝向: 斜面朝-Y+Z, 屏朝观察者并向后倾(此前朝后/30°均已纠正)
    - 重写make_assembly: 屏框背面共面贴合60°斜墙, 屏底落铰接点, Z_min=0不破桌面
    - 同步更新设计文档
    [assembly.step, back_cover.step, back_cover.stl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]
2026-06-04 chore(lfs): stl 等 3D 网格格式纳入 LFS,png 预览图改为 gitignore
    - .gitattributes: 新增 *.stl/*.3mf/*.obj/*.glb/*.ply/*.amf/*.brep LFS 规则
    (build123d 导出的网格模型与通用 3D 交换格式)
    - .gitignore: 忽略 cad/output/*.png 预览渲染图(可由 render_preview.py 重生成)
    - 从跟踪中移除已提交的 4 个预览 png(工作区文件保留)
2026-06-04 [feat] 外壳按真实PCB1.step更新: 仓70x50/孔±30,±20/Type-C定位
    - 从 hardware/PCB1.step 实测: 板70.1x50.04, 孔Φ3.2@(±30,±20),
    Type-C在Y-长边中点, FPC排座在Y+长边中点, 最高元件~3.7mm
    - 外壳: PCB仓71.1x51, 螺柱(±30,±20), Type-C开口+Y壁中心高7.65
    - 新增 analyze_pcb.py(STEP机械接口提取) / fitcheck.py(真实PCB装配核对)
    - fitcheck验证: 螺柱对孔/板落仓内/Type-C对位 全通过
    - 同步设计文档 §1/§5
    [assembly.step, back_cover.step, base.step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]
2026-06-04 [feat] 底座内腔减薄 15->9mm (元件仅3.7mm)
    - CAVITY_CLEAR 15->9, 核心盒壁高 17->11mm
    - 校验: Type-C开口顶10.65 + 元件顶9.7 均被11mm壁包住
    - fitcheck 重验: PCB落仓/螺柱对孔/Type-C对位 仍通过
    [assembly.step, back_cover.step, base.step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]
2026-06-04 [feat] PCB抽拉式卡扣盖板 + 修复盖板压穿PCB
    - 新增第4件 lid: 沿+X抽出, 前后唇导轨, +X卡扣detent+手指凸耳, 前缘FPC缺口, 避让斜墙
    - 修复: 盖板原坐落z6.75压穿PCB(顶7.6)/元件(顶9.7); Z链改为自LID_BOT_Z=10.25上推
    - 修复: 前导轨立条原切板35mm³ -> 改悬臂支托(z9.8起)悬于PCB上方
    - 核心盒壁高 11->12.5 (容盖板于元件上方), 内腔10.5
    - 真实PCB验收: 盖板底10.25 > 元件顶9.66 余量0.59; base∩PCB=0; 四件valid
    [assembly.step, back_cover.step, base.step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]
2026-06-04 [feat] PCB前移(FPC够长)+盖板改后(+Y)抽出+放宽紧配合
    - 新增CORE_CY=-11: PCB仓前移11mm, 排座->-33, FPC跨度24->14mm(20mm排线够到)
    - 螺柱随移至(±30,+9)/(±30,-31), Type-C后壁->+17, FPC缺口->前缘
    - 盖板抽出方向 +X->+Y(向后): 侧壁导轨, 后端卡扣+凸耳, 避开前斜墙, 覆盖整块PCB
    - 后壁削低至10.3让盖板滑出; Type-C开口随之(z5.2..10.2)
    - 放宽紧配合: 盖板对元件余量0.59->0.94, Type-C对连接器0.15->0.60
    - 真实PCB验收: FPC14mm/base∩PCB=0/lid∩PCB=0/螺柱偏差0.12mm/四件valid
    [assembly.step, back_cover.step, base.step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]
2026-06-04 [fix] 修复装配体各件耦合干涉 (6对两两干涉全清零)
    - make_assembly: 后盖摆放错误(未翻转->压屏框2636mm³); 改为绕Y翻180+以"后盖外表面"
    对齐斜墙面(屏框组件靠斜墙的是后盖外表面, 非bezel背面), base∩back 713->0
    - 盖板前缘公式漏算前挡条厚度, 压进挡条1.7mm(盖板关不到位); 抵到挡条+Y面外, base∩lid 114->0
    - 后盖凸台边框顶到bezel角立柱(Φ5)48mm³; 凸台区加Φ6 boss让位, 盖板保留Φ2.7螺丝孔, ->0
    - 新增 check_interf.py 装配两两干涉检查工具
    - 复验: base/bezel/back_cover/lid 两两干涉全=0, 四件valid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
    [assembly.step, back_cover.step, back_cover.stl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]
2026-06-04 [fix] 卡扣detent凸点悬空(独立实体)修复
    - detent凸点原中心X=±34.05, 半径1->到35.05, 距侧壁内面35.55差0.5mm, 悬空成独立实体
    (装配STEP里多出2个3mm³浮块, 即查看器的 SOLID/SOLID_1)
    - DETENT_X外移到 INNER_HALF_W-0.3, 嵌入侧壁0.7mm连体, 仍凸入槽~0.7咬合盖板
    - 结果: base 3实体->1实体; 装配体 6实体->4实体(每件1个); 两两干涉仍全0; 四件valid
    [assembly.step, back_cover.step, base.step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]
2026-06-04 [feat] 凹槽免螺丝固定屏框 (取消接缝螺丝)
    - 脚板前缘向-Y延伸13.5mm(前缘->-58.5)托住前挡唇; 铰接/斜墙仍在-45
    - 前挡唇: 改为竖直内面(立于屏前底角-53前0.4mm), 屏前倾抵唇防倒出
    (subagent原做60°斜唇上部插进屏框28.8mm³ -> 竖直唇后降到卡点轻触级)
    - 取消2× M3接缝螺丝(及SEAM变量); 斜墙保留做后撑斜面
    - 加轻卡点(cleat)擦触屏前表面, 插到底轻扣防碰出
    - 验收: 6对干涉中5对=0, base∩bezel=3.67mm³(卡点轻触<5可接受);
    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
    [assembly.step, back_cover.step, base.step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]
2026-06-04 [feat] 盖板去抽拉凸耳, 改顶面防滑横条
    - 凸耳在+Y后端与Type-C数据线打架, 移除
    - 改为顶面靠后端5道沿X横条(凸0.7mm), 拇指压住推开上盖
    - 横条顶z12.8<壁顶12.85; 盖板不再伸出后缘(Y最大=14.52); 仍1实体
    - 干涉不变(5对0, 卡点轻触3.67), 全valid
    [assembly.step, back_cover.step, base.step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]
2026-06-04 [feat] 底座后缘缩至与PCB盒齐平 (让开Type-C数据线)
    - 脚板后缘 +45 -> +17.02 (=核心盒后壁), Type-C口后方不再有脚板, 数据线插入清爽
    - 前缘仍-58.5托前挡唇; 重心Y≈-16偏前, 缩后缘不影响防倾
    - base深 103.5->75.52; 仍1实体; FPC14mm/干涉(5对0+卡点3.67)/全valid 不变
    [assembly.step, back_cover.step, base.step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]
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2026-06-05 [hw] 完成第一版本PCB
    [PCB1.PcbDoc, PCB_Project.PrjPcb, Sheet1.SchDoc]
2026-06-05 [feat] 屏框/后盖/底座脚板外形四角R10圆角
    - CORNER_R=10; 三件外形首块改圆角矩形拉伸(robust, 不靠边选择)
    - 屏框角立柱在R10内不受影响; 干涉不变(5对0+卡点3.67); 全valid
    - 盖板暂未倒(隐藏件且四边为导轨/卡扣功能面, R10会破坏咬合)
    [assembly.step, back_cover.step, back_cover.stl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]
2026-06-05 [hw] TypeC母座下移
    [PCB1.PcbDoc, PCB1.step]
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2026-06-05 [feat] 装配体组入真实PCB预览 + 对新PCB复核通过
    - make_assembly 增 pcb 参数; main 导入 hardware/PCB1.step 按装配姿态(翻转+移CORE_CY+坐螺柱)并入
    - assembly.step 现含 4外壳件 + 真实PCB(914实体)用于预览
    - 新PCB(Type-C外挪1mm)复核: FPC14mm/孔位/干涉(5对0)全过; Type-C recess 2.37->1.35mm, 开口仍对位
    [assembly.step, back_cover.step, base.step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]
2026-06-05 [feat] Type-C开口改为贴合USB-C的圆端长圆形(obround)+内侧让位
    - 原方孔12.5x5 -> obround 9.6x3.4(圆端r1.7, SlotOverall), 贴合USB-C插头8.34x2.56
    - counterbore: 外侧贴合obround(可见端口) + 内侧加宽12x4.4让位连接器壳体(11.3宽,伸入壁1.15)
    - 复核: base∩PCB 1.85->0, lid∩PCB=0, FPC14mm, 外壳件干涉(5对0+卡点3.67), 全valid
    [assembly.step, back_cover.step, base.step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]
2026-06-05 [feat] 另存仅外壳装配 assembly_shell.step (4件, 不含PCB)
    - main 增导出 assembly_shell.step: bezel/back_cover/base/lid 闭合装配, 无PCB
    - 775KB/4实体 (对比含PCB的 assembly.step 26MB/914实体)
    [assembly_shell.step]
2026-06-09 [docs] InkPulse 墨水屏显示系统设计文档
    方案: 瘦客户端 + 本机Hub渲染。Hub(Python/FastAPI/Pillow)采集Claude状态(hooks)
    与用量(解析订阅日志)、管理待办(Web UI)与照片, 渲染800×480三色位图经HTTP下发;
    固件(ESP-IDF)拉帧→ETag去重→UC8179全刷→离线缓存。组合仪表盘默认布局, YAML配置。
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2026-06-09 [fw] 墨水屏驱动跑通(白黑红色彩正确) + HTU21D集成 + 合并验证
    屏幕: 补焊升压后UC8179全刷正常、黑/白/红极性正确(无需取反)。
    epd_init: PON后不再死等BUSY(本板PON不回高), 改固定800ms ramp; DRF仍等BUSY。
    新增htu21d(I2C GPIO2/1, addr0x40)。main为温湿度+屏幕合并验证。
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2026-06-11 build(fw): 自定义分区表(app 2MB) + 启用NimBLE
    [partitions.csv]
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2026-06-11 fix(fw): BLE配网收尾不崩溃/不误断App + 开机消红残影 + 湿度诊断
    - ble_prov: 改用 wifi_prov_mgr_wait()+定时器超时, 去掉自建 event group (修 xEventGroupSetBits assert 崩溃)
    - wifi_prov: 配网成功后复用 mgr 已建立连接直接进主循环, 不再 esp_restart (修 App "Device disconnected")
    - main: 联网后首帧前 epd_clear() 消除阶段一红测试图案的 BWR 红残影
    - htu21d: 上电软复位(0xFE) + 测量 raw 诊断日志 (湿度通道恒返回0, 定位为传感器硬件问题)
    - README: 配网章节更新为 BLE 为主 + SoftAP 兜底
    [htu21d.c, main.c]
2026-06-11 fix(hub): 三色渲染关抗锯齿/跨平台中文字体 + 隐藏无效湿度
    - engine: d.fontmode="1" 关抗锯齿 (三色严格量化会丢抗锯齿灰边导致小字发虚)
    - widgets: 中文字体路径补 Linux/Windows; 顶栏湿度仅 0~100% 有效才显示 (传感器损坏的负值自动隐藏, 换好后自动恢复)
2026-06-11 docs: 补项目总览 README + hardware/cad/hub 子系统文档
    - 新增顶层 README: 项目简介/系统架构图/仓库结构/技术规格速查/端到端快速开始/当前状态路线图/文档索引
    - 新增 hardware/README: Altium 工程文件/元件库 submodule/板上器件/引脚映射/机械接口
    - 新增 cad/README: build123d 工具链/四件套零件/装配关系/校验脚本/关键参数
    - 扩充 hub/README: 模块结构/采集器/HTTP端点表/config.yaml/hooks/测试
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2026-06-11 fix(fw): SoftAP兜底切AP前先esp_wifi_stop + VERIFY补分屏/棋盘图案
    对账发现的两项缺口:
    - wifi_prov: start_provision_ap() 首行加 esp_wifi_stop(), 修 BLE配网/STA 残留状态导致切 AP 模式失败(计划注里预警的潜在 bug)
    - main: INKPULSE_VERIFY 分支补 epd_show_split/epd_show_checker 调用(函数早已实现, 之前未串进 bring-up harness)
    [main.c]
2026-06-11 fix(fw): 修 INKPULSE_VERIFY 编译宏从未生效 + 防 cache 残留
    测 split/checker 时发现 verify 模式形同虚设:
    - main/CMakeLists.txt: 加 target_compile_definitions 把 idf.py -DINKPULSE_VERIFY 的 CMake 变量转成 C 宏, 否则 main.c 的 #ifdef INKPULSE_VERIFY 永远看不到它
    - build.sh/build.ps1: build 显式 -DINKPULSE_VERIFY=0 清掉 verify 残留在 CMake cache 的值, 避免 verify 后普通 build 仍跑验证模式
    真机验证: verify 序列完整跑通(白/黑/红/分屏/棋盘, 屏显正常)
2026-06-11 fix(fw): STA 直连支持 WPA3-SAE(修重启后无法重连小米热点) + 断连 reason 日志
    实测烧回固件后用 NVS 凭据直连 Xiaomi 15 反复在 auth 阶段失败, 抓 reason 定位:
    - wifi_prov: load_creds 手动 STA 直连补 WPA2/WPA3 混合 threshold + PMF capable + SAE H2E;
    纯 WPA3(小米热点)在 SAE auth 阶段需要这些, 否则连不上。
    此 bug 之前被掩盖——'端到端跑通'一直走 BLE 配网复用 wifi_prov_mgr 连接(mgr 默认支持 SAE),
    load_creds 直连路径从未在 WPA3 真机验证, 实际设备一重启就无法自动重连。
    - on_wifi: 打印 disconnect reason/rssi 便于诊断。
    真机验证: 重启用 NVS 凭据直连 WPA3-SAE 成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
2026-06-11 fix(hub): 照片等比缩放(letterbox)避免拉伸变形
    dither_bwr 用 ImageOps.contain 等比缩放 + 白底居中, 不再硬 resize 到 800×480 把图拉伸。test_photos 4 passed。
2026-06-11 fix(fw): WPA3-SAE 直连断开自动重连(修偶发 auth 超时掉 SoftAP)
    复位多次发现 WPA3 直连时连时不连: reason=2(AUTH_EXPIRE)是 SAE 握手偶发超时, 信号强(-23)非密码/信号问题。
    - on_wifi: STA_DISCONNECTED 时重连重试(最多 STA_MAX_RETRY=8 次)再放弃进配网, 而非首次失败即掉 SoftAP
    - WaitBits 超时 15s→40s, 留足重试时间
    真机验证: 直连 Xiaomi15 WPA3-SAE 成功拉帧上屏
2026-06-11 fix(fw): WPA3-SAE 直连改主流程循环重连(带2s间隔)替代回调猛连
    实测回调里立即重连8次仍全败(reason 205/2 交替, AP 对密集重连限速/拒绝)。
    - 重连逻辑从 on_wifi 回调移到主流程: 带 2s 间隔循环重连最多 15 次, 每次给 8s 等 SAE 握手
    - on_wifi 回归只设 GOT_IP/FAILED 标志
    WPA3-SAE 在 ESP32+小米热点组合下握手本就偶发失败, 此策略给 AP 喘息、最终连上; 实测连上拉帧上屏完整仪表盘。
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2026-06-12 refactor(fw): 新增 ip_hal component(SPI/I2C/GPIO 封装 + board_pins)
    - main/pins.h → components/ip_hal/include/ip_hal/board_pins.h(git mv)
    - spi_bus.h/c: 从 epd_uc8179.c 抽取 hal_spi_init/cmd/data/data_buf/reset/busy_level
    - i2c_bus.h/c: 从 htu21d.c 抽取 hal_i2c_init/write/read
    - main/epd_uc8179.c, frame_client.c: pins.h → ip_hal/board_pins.h
    - main/CMakeLists.txt: REQUIRES 加 ip_hal
    [board_pins.h, i2c_bus.c, spi_bus.c]
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2026-06-12 fix(fw): 修重构回归 — STA netif 无条件创建(有凭据直连路径漏建致拿不到IP)
    重构 main 编排时 ip_net_prepare_sta() 只放在无凭据(配网)分支, 有凭据直连路径没创建 STA netif → WiFi 关联上 WPA3 但无 DHCP client、拿不到 IP、循环重连耗尽。原 wifi_prov.c 两分支都创建 netif。
    改为 ip_net_init() 后无条件 ip_net_prepare_sta()(幂等)。
    真机端到端验证: 连 Xiaomi15 WPA3-SAE → DHCP IP 172.27.73.42 → 拉帧上屏, 行为与重构前一致。
    [main.c]
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2026-06-12 fix(fw): WiFi 加密门槛改 WIFI_AUTH_WPA2_PSK(兼容 WPA2/WPA3, 修纯WPA2热点拒连)
    原 WIFI_AUTH_WPA2_WPA3_PSK 是'最低门槛'、枚举值更高, 会把纯 WPA2 热点判为不达标拒连(reason=211, 真机实测命中)。改为 WPA2_PSK 门槛: 同时接受 WPA2 与 WPA3; pmf/sae 保留兼容 WPA3-SAE。根治之前 WPA3-SAE 偶发抽风——可改用更稳的 WPA2 热点。
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2026-06-12 feat: hub 地址通用化 — mDNS 自动发现 + NVS 手动 + 编译默认兜底
    换网/换 IP 不再需要重编重烧, 设备开机自动发现 hub。
    固件:
    - ip_channel/http_hub: resolve_hub_base 三级解析(mDNS _inkpulse._tcp >
    NVS 手动 > 编译默认), 拼 /frame; 引入 espressif/mdns 托管组件
    - ip_provisioning: hub_addr_load/save(NVS key "hub") + SoftAP 表单加
    "Hub 地址" 可选栏(urldecode 解码)
    - ip_config: HUB_FRAME_URL → HUB_DEFAULT_BASE(默认兜底, 不含 /frame)
    hub:
    - discovery.py: zeroconf 注册 _inkpulse._tcp; _pick_lan_ip 排除
    VPN/CGNAT(198.18/100.x) 选真实局域网 IP; INKPULSE_HOST_IP 可显式覆盖
    - __main__: 启动注册 mDNS, 退出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
2026-06-13 fix(hub): 照片支持 .webp 格式
    photos.py 选片(pick_photo)与 server.py 列表(/api/photos)的扩展名
    白名单都漏了 webp, 导致从网页保存的 .webp 图既不在列表显示、也选不中
    渲染。Pillow 原生可解码 webp, 两处各加 .webp 即可。
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2026-06-13 fix(hub): 内置布局只读(PUT 拒覆盖 + 编辑器另存为)+ 补 widget 异常隔离测试
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2026-06-13 fix(hub): 编辑器 select option value 也转义(XSS 加固)
2026-06-13 fix(hub): 待办复选框改用思源黑含的 ✓/□(原 ☑/☐ 缺字形显示为方块)
2026-06-13 fix(hub): 今日用量标签 tok -> tokens(完整单词)
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2026-06-13 fix(hub): clock 时钟字号收小 + 头部按宽度自适应(修 split 头部覆盖)
2026-06-13 fix(hub): split 用量给足3行(不再截会话数) + 月历星期表头调大
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2026-06-14 fix(weather): current() 解析失败时降级返回 None(坏缓存不崩)
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2026-06-14 fix(weather): geocode 中文2字市名补"市"重试(修厦门等搜不到)
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2026-06-14 fix(market): _get_bytes 加 User-Agent(修 OKX 403)
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2026-06-15 fix(render): draw_header 红色(星期/节日)走 accent, 补齐 header 的 BW 降级
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2026-06-15 fix(render): claude_status/usage/usage_ring 条件红走 accent, bw 全态无红
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2026-06-15 fix(fw/display): SSD1677 改行式流写, 消除 48KB 整屏 .bss(DRAM 溢出)
    [ssd1677.c, ssd1677_internal.h, ssd1677_selftest.c]
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2026-06-15 fix(hub/web): 真机面板隐藏坏传感器哨兵值(湿度 -100/0、越界温度)
    湿度传感器损坏时回 -100/0 哨兵, 面板原样显示成"湿度 -100%"。
    仅在 0<湿度≤100、-50<温度<80 时显示, 与帧渲染的无效值过滤一致。
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2026-06-16 fix(hub/web): 预览框跟随帧形状, 消除竖屏白条
    PreviewPanel 的 .screen 原写死 aspect-ratio 5/3(7.5寸横版), 竖屏帧
    (480x800) contain 进去左右大片留白且缩得太小。改为收紧包住帧本身、
    按高度(72vh)封顶居中, 形状自动跟随横/竖版, 既消白条又放大更清晰。
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2026-06-16 fix(fw/display): 处理 review 反馈(wait_busy 超时防护/clear 同步0x26/set_ram_counter 改名/selftest 去重)
    [ssd1677.c, ssd1677_internal.h, ssd1677_selftest.c]
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2026-06-16 fix(fw/display): 局刷改用本屏型号官方参考(0x21 差分+0xFC, 去自定义LUT)
    借的 3.7寸 LUT 致背景发灰——用错路子。本屏 GDEQ0426T82 官方驱动证实: OTP
    自带局刷波形, 不需 0x32 自定义 LUT。关键是 0x21 Display Update Control1:
    局刷 0x00(用旧RAM 0x26 差分)+0x22=0xFC; 全刷 0x40(bypass)+0x22=0xF7。
    [ssd1677.c]
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2026-06-17 revert(fw/net): hub 编译默认改回 .64, 不写死本机临时 IP
    撤销 fe3db83 里把默认 hub 地址改成 192.168.10.217 的临时绕过。
    解析优先级本就是 mDNS自动发现 > NVS手动配 > 编译默认兜底, 编译默认
    不应携带某台机的 DHCP 临时 IP。设备以 mDNS 为先。
    注: 本机 WSL2 mirrored 网络 + Clash TUN 下 mDNS 多播到不了板子,
    若该环境要让板子联上 hub, 走 NVS 手动配(配网表单填 hub 地址)或修
    WSL/Windows 多播转发, 不再依赖编译默认。
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2026-06-28 feat:v1.1硬件改版
    [PCB1.PcbDoc, PCB_Project.PrjPcb, Sheet1.SchDoc]
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2026-06-29 [feature] 更新pcb与对应的2d/3d文件
    [PCB.DWG, PCB.step, PCB1.PcbDoc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]
2026-07-01 [feature] 更新pcb文件
    [PCB1.PcbDoc]
